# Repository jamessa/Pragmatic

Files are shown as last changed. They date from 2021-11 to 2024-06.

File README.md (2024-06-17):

# Pragmatic Keyboard Kit

**Pragmatic 務實鍵盤** 是一個分離式鍵盤套件，有數字列，有方向鍵與功能列。支援VIAL與QMK，輕鬆調整鍵盤配置，是分離式鍵盤的基本款。

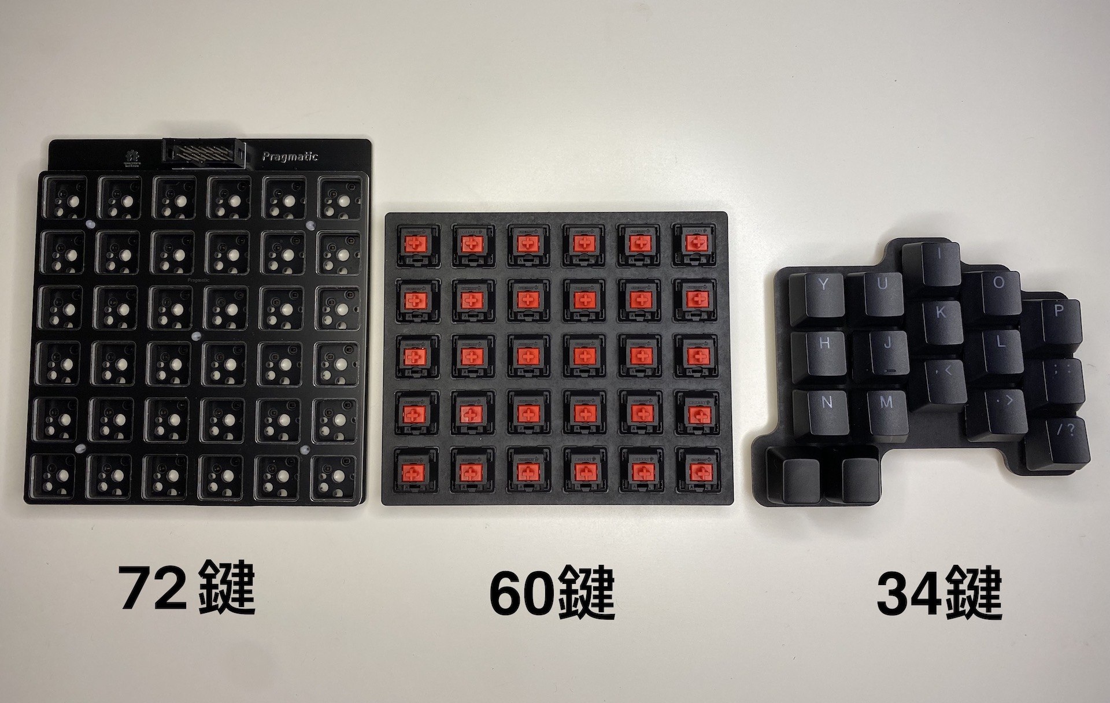
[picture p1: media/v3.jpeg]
V3


# 務實主義

本套件的開發將會務實的採用[敏捷流程](http://theleanstartup.com)，每次都發佈最小可行硬體套件，然後讓大家一起討論，看看如何讓這個鍵盤變得更好用。

換言之，這將是一把大家一起設計的鍵盤，而設計的原則就是「 **務實** 」，只加入使用的功能，降低開發的時間與成本；使用最少的硬體，達到最好的效果。

在嘗試了超多款鍵盤與超級多的[人體工學研究](https://youtu.be/p7gZdOTpbP8)之後，上週我無意間試做了分離式鍵盤的始祖直排[Let's split](https://github.com/nicinabox/lets-split-guide)，不得了！！！這實在太好用了，**務實，一整個好用。**

首先直排讓手指可以**自然的上下移動，減少手指的負擔**，讓使用者不會過勞。分離式鍵盤可以顯著改善腰酸背痛的辦公室症候群。自己改用了分離式鍵盤以後，背痛就減輕八成(個人經驗)。

**總鍵數達到72個，但是使用的空間卻比60%鍵盤還小**，實在是太神奇了。因此我才會想要開啟這個專案。

務實的設計目標是用最少的晶片做出可分離的鍵盤。不同於一般的分離式鍵盤需要兩個控制板，務實鍵盤只需要用到一個控制板。

**Pragmatic 務實鍵盤**是100%開源的，全程使用開源電路軟體KiCad設計，讓大家可以隨意改出符合自己需求的版本。要實踐一把務實鍵盤，需要以下的材料：

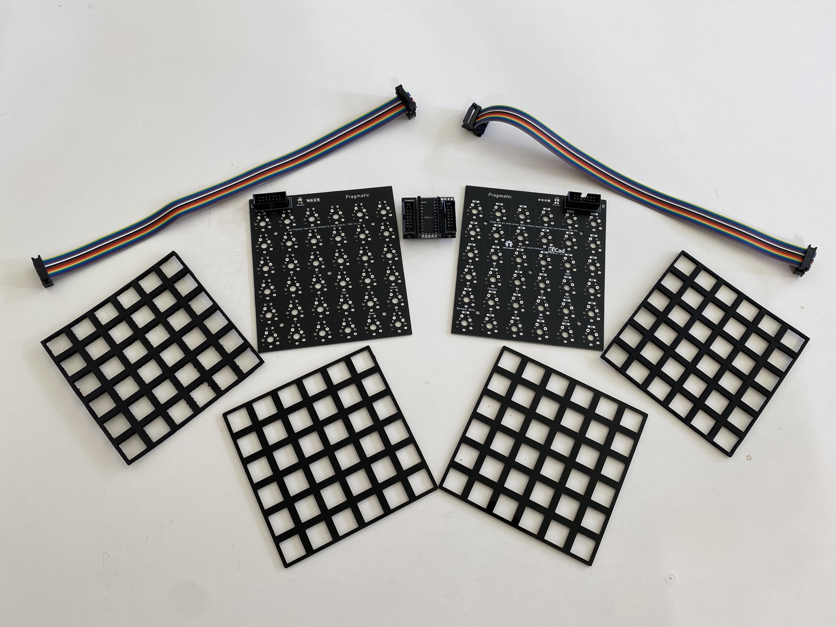
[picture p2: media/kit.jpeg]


- 務實鍵盤電路板套組，如上圖：
  - 電路板 * 3片：主控、左手、右手。
  - 壓克力定位板 * 2片
  - 消音泡棉 * 2片
  - 排線 * 2條

- 套組不含
   - [Pro Micro](https://www.sparkfun.com/products/12640)或相容的開發
   - 軸
   - 鍵帽
   - 願意打破傳統的心（對，就是你！）

# 預設配置
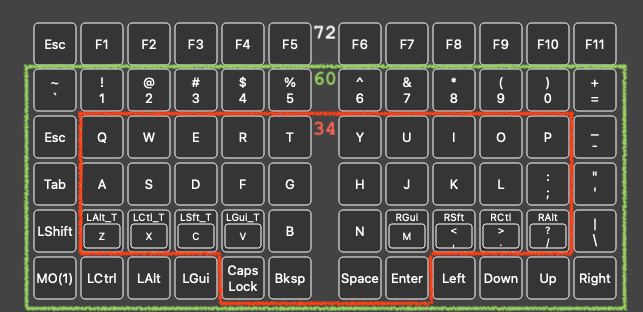
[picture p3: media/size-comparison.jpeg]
size comparison chart


# [使用手冊](START.md)

# FAQ

Pragmatic V3 FAQ (https://youtu.be/gGC56R72y4Q)說明影片

## 分離式鍵盤會不會很難適應？
老實說，這絕對不是一天就可以適應的，但是[鍵人谷](https://www.facebook.com/groups/1111882339005914)太多人換過鍵盤了，都可以提供很多方法。我自己會建議每天[keybr.com](keybr.com)練習15分鐘，慢慢打，求正確度，不用擔心速度。一到兩週就可以上手了，從此人生就改變了?!

## 拇指好按嗎？
內行人，其實我的右手很弱，打字一整天右手就會開始痛。然後我開始做鍵盤配置與手的解剖學研究，才發現到拇指不應該大量使用

## 組裝好之後，桌面到鍵帽(假設是高軸加上XDA鍵帽)的厚度如何？
24mm 我也是用XDA。應該說，因為我不用QWERTY配置，導致我只有XDA可以使用。

## 可以改鍵盤配置嗎？
本鍵盤支援[QMK](https://qmk.fm)與[Vial](https://get.vial.today)，讓你為所欲為。

## 可以給一下目前您用的定義嗎？
我的配置。我平常寫C, Python,最近寫Tex😅 打字的話，漢語拼音佔九成，英文一成。
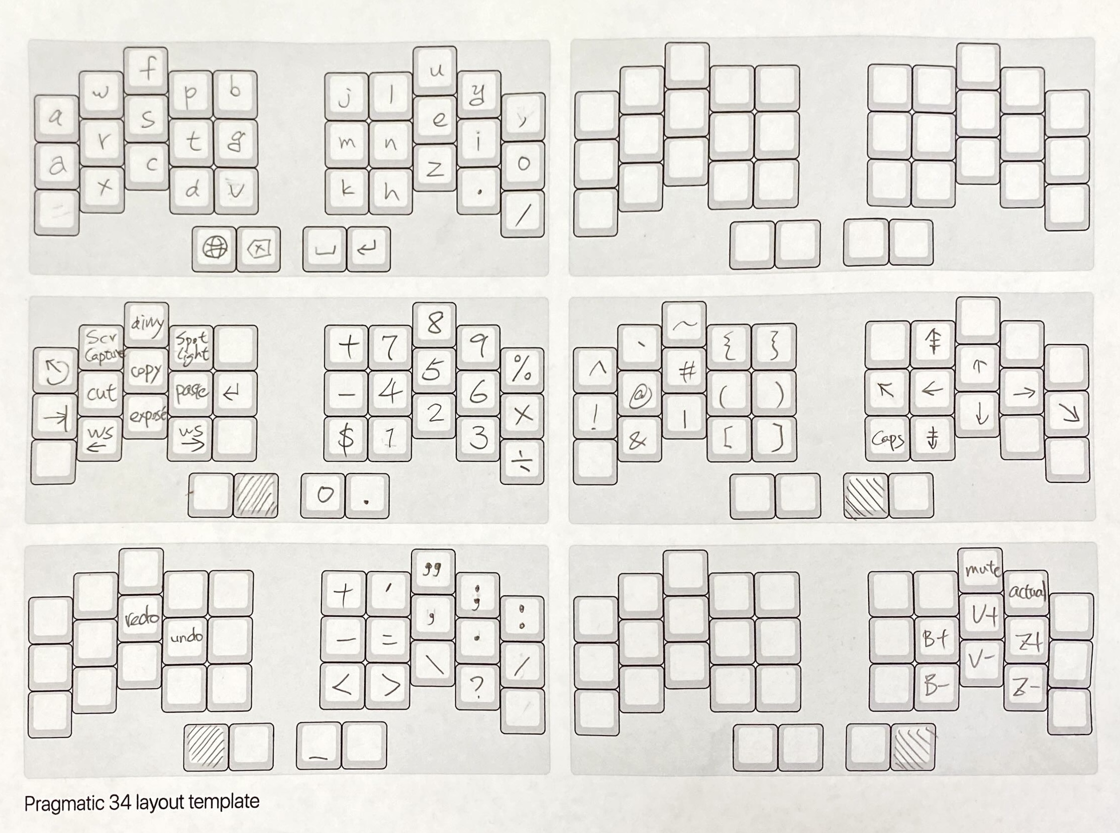
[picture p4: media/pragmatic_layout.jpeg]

而且我喜歡用鉛筆做記號，方便我快速修改配置。你可以在此下載

- 34的空白設計檔[PDF](media/pragmatic%2034%20layout%20sheet.pdf)。
- 42的空白設計檔[PDF](media/Pragmatic%2042%20Layout%20Designer.pdf)、[SVG](media/Pragmatic%2042%20Layout%20Designer.svg)。

## 關於小鍵盤使用比較複雜的指令，比如說 <kbd>Ctrl</kbd>+<kbd>C</kbd>，<kbd>Command</kbd>+<kbd>Space</kbd>這種橫跨多個 Layer 的情形，有甚麼比較好的處理方式嗎？設定Macro？

包括切換workspace，我都是做成左手快捷鍵。可以參考上圖左邊中間的配置，那是我的操作與數字層。

## 在咖啡廳使用會被搭訕嗎？
我不知道為什麼你要這麼問。但是我們也做了一個抽樣調查，正妹/天菜受訪者表示會想要瞭解這個新奇的鍵盤，而不是使用者別擔心。

# 安裝說明
1. 依照下圖順序排列
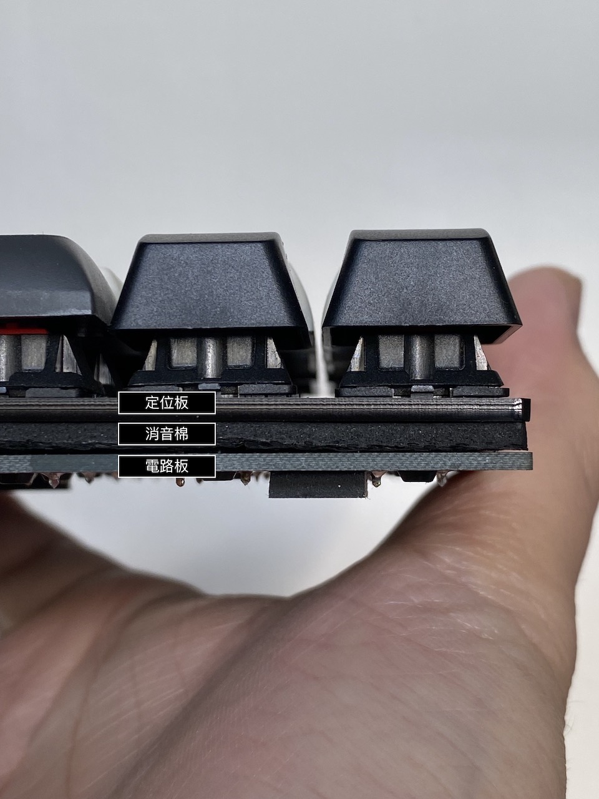
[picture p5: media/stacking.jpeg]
stacking

2. 接線方式
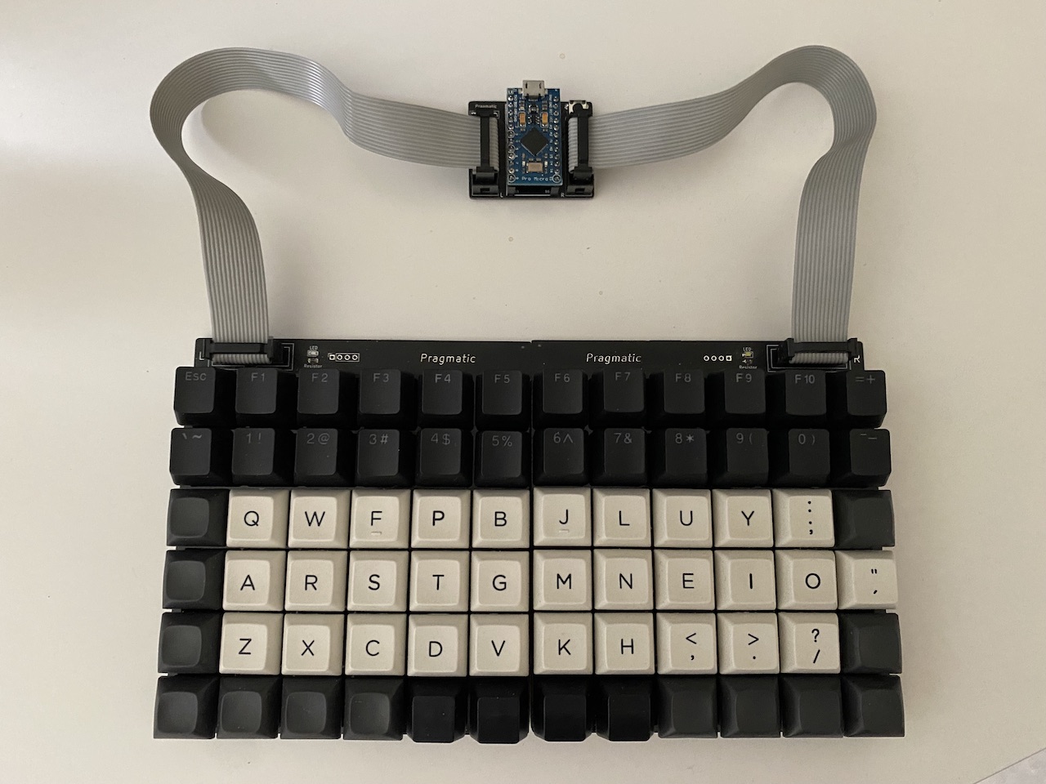
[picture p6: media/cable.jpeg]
cable


# Vial使用方式

1. 下載[Vial](https://get.vial.today)
1. 打開Vial.app就可以修改配置了。

# 更新韌體
1. 下載最新的
  - [QMK Toolbox](https://github.com/qmk/qmk_toolbox/releases/latest)
  - [務實韌體](https://github.com/jamessa/Pragmatic/releases/latest)
  - [Vial配置軟體](https://get.vial.today/download/)
2. 開啟「Vial」，備份目前的配置。「Vial」->「Save current layout」。
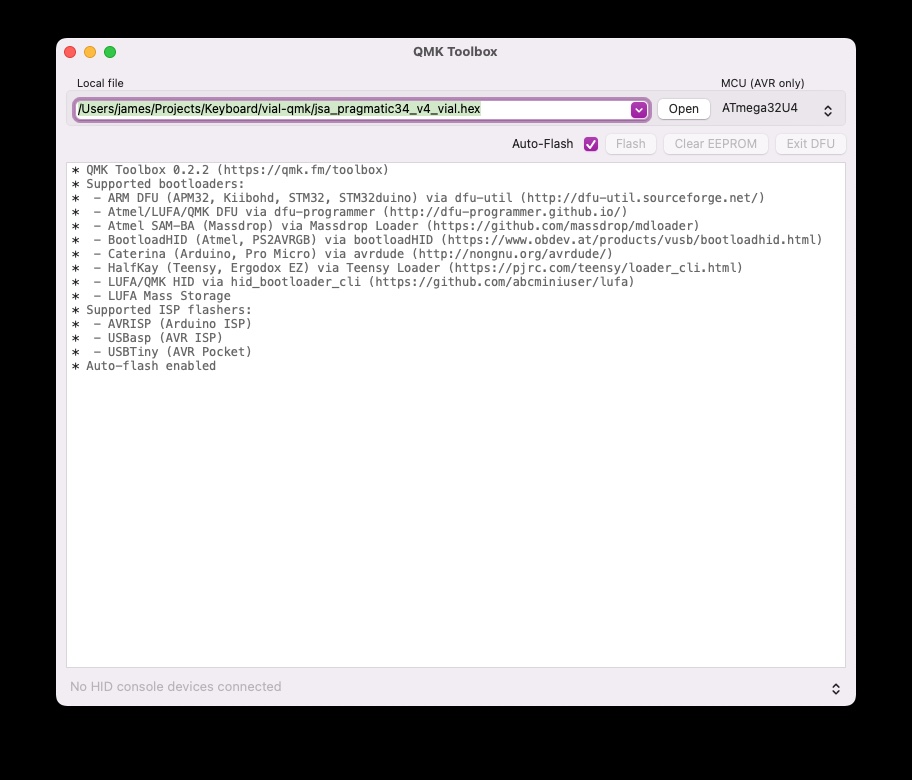
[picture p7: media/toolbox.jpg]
toolbox
3. 開啟QMK toolbox，選取剛剛下載的韌體，並且勾選*Auto-Flash*。
4. 按下控制板上面小小的Reset按鈕，這樣就更新完成了。

# Inspired by

- [34 key layout](Seniply https stevep99 github io seniply by Stevenp99)
- [Let's split](https://github.com/nicinabox/lets-split-guide)
- [GH36](https://geekhack.org/index.php?topic=61306.0)
- [Nyquist/Levison Keyboard](https://keeb.io/products/nyquist-keyboard)
- Xah lee [Why function keys are useful!](http://xahlee.info/kbd/keyboard_function_keys.html)
- Quasimode https://en.wikipedia.org/wiki/Mode_(user_interface)
- Mode slips and low discoverability. https://www.nngroup.com/articles/modes/

# 想知道更多

[臉書討論](https://www.facebook.com/groups/1111882339005914/posts/1790356644491810) 或 加入[Telegram群組](https://t.me/joinchat/qp7NLK_H0vY2MjA1)

# Changelog
- 2022-08-08 Refactor folder structure.
- 2022-08-05 Pragmatic 34 R2.
- 2022-06-11 V3.1 Controller with OLED.
- 2022-03-18 V3 with [3 form factor](https://www.facebook.com/groups/1111882339005914/posts/1883231691870971/)
- 2022-03-02 V2 Hotswap
- 2022-01-09 改用 Kicad 6
- V0.4 改回ProMicro腳位，增加相容性。
- V0.3 改為Elite-C腳位，重新定義IDC connector的腳位。
- V0.2 改為雙面版。
- V0.1 開始。

## Gallery

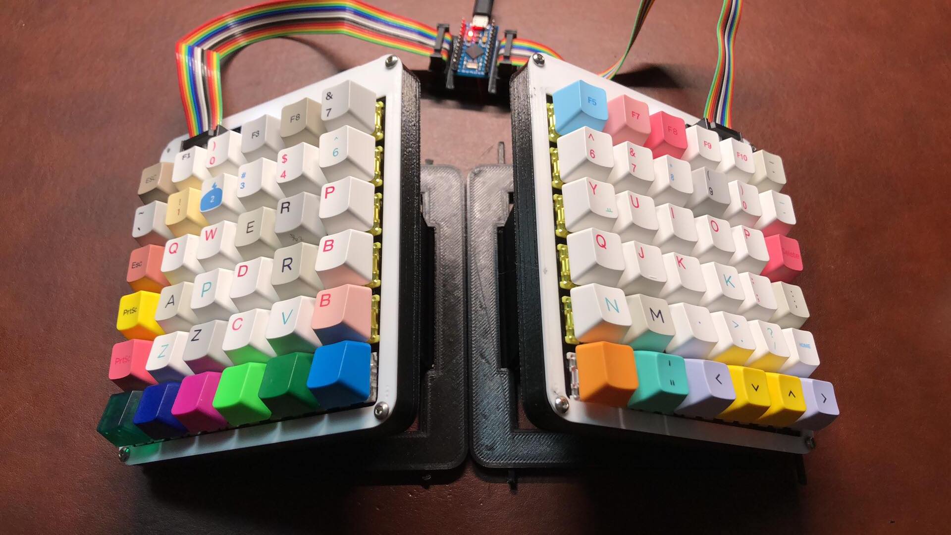
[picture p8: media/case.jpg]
Pragmatic with Case

Pragmatic 72 [Tent Case](https://www.thingiverse.com/thing:5178752) designed by [Botio! Studio](https://botiostudio.com)

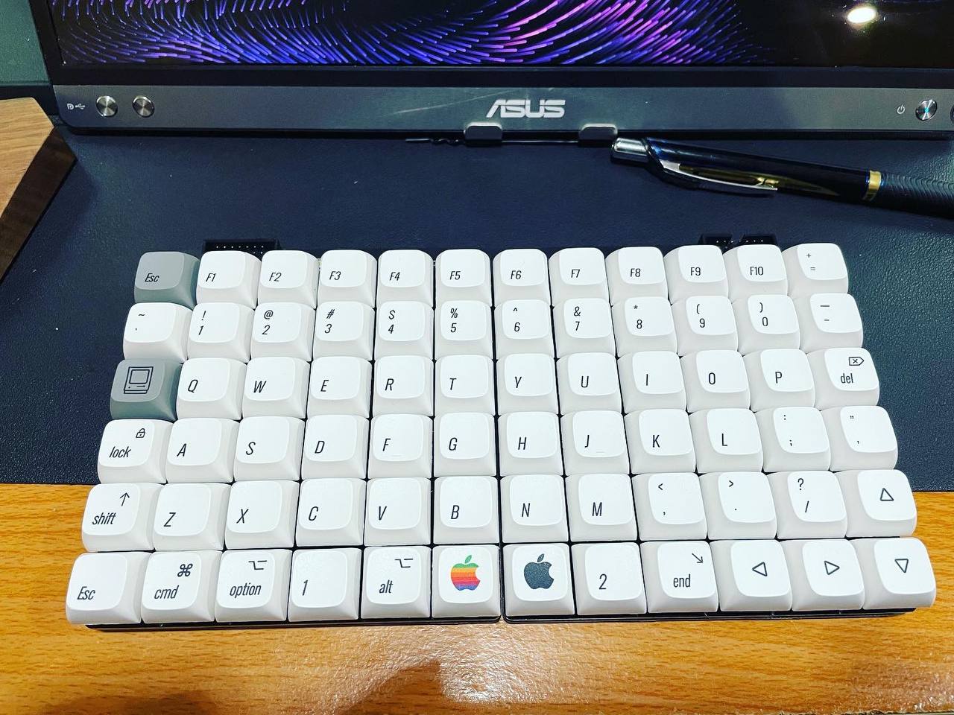
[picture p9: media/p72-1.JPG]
Pragmatic 72
 Pragmatic 72 by Bart.

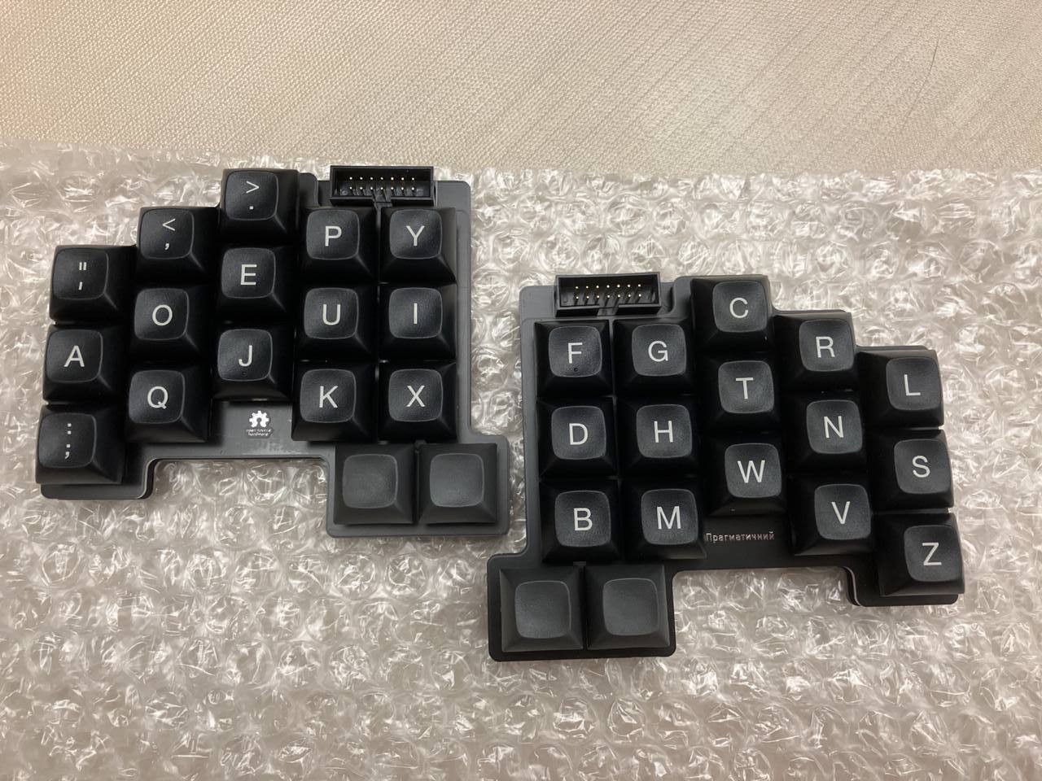
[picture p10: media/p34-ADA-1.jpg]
Pragmatic 34
 Pragmatic 34 with [ADA keycaps](https://drop.com/buy/tex-ada-keycap-set) by Sean

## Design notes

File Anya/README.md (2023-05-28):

# Changelog
## 2023-05-29 R2
- Use SK6812 for eaiser key switch change

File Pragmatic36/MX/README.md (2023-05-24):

The Pragmatic 36 keyboard features

- 21 keys per hand with a fully symmetric double side design. One side is designed for the left hand and the other for the right.
- Duplex Matrix to save pins. Use Controller A.
-  8-pin connector that utilizes a user-friendly 2x4 2.54mm PinHeader.
- Support Kailh hotswap sockets.
- A modern 19mm x 19mm key pitch.
- Supports Kailh PG12800 Half key switch.

Current status: initing.

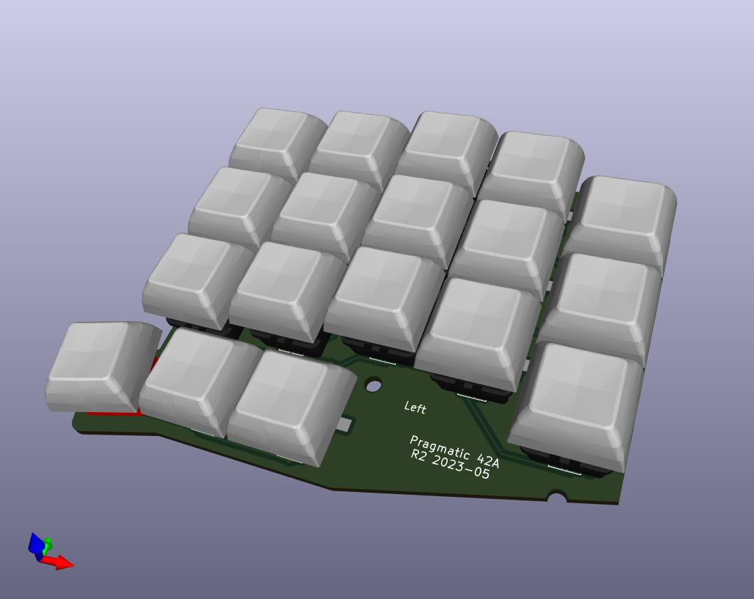
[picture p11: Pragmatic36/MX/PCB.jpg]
PCB


# Revsions
## MX36A1 2023-05-24 
   ^^ Swith type MX or Choc
     ^^ Number of keys
       ^ Matrix Type: null for naïve matrix, A for duplex matrix
        ^ PCB Revision
- Stagger Profile MX V3
- Initial release, modified from MX42A2.

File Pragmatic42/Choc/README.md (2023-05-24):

The Pragmatic56 keyboard features

- 28 keys per hand with a fully symmetric double side design. One side is designed for the left hand and the other for the right.
- Duplex Matrix to save pins.
-  8-pin connector that utilizes a user-friendly 2x4 2.54mm PinHeader.
- Support Kailh hotswap sockets.
- A compact key arrangement with a 19mm x 18mm pitch and an 18mm vertical pitch that reduces fingers need to travel distance.

Current status: Validating.

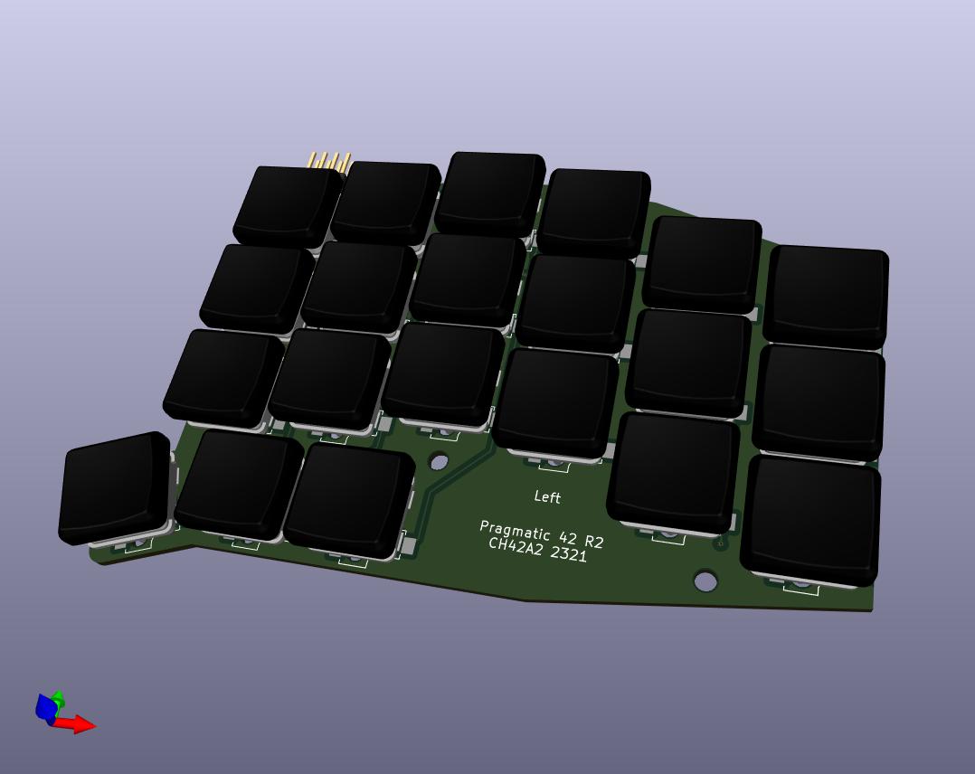
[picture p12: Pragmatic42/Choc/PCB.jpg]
PCB


PCB with switches

# Revisions

## CH42A2 2321
   ^^ Switch type CHoc or MX
     ^^ Number of keys
       ^ Matrix Type: null for naïve matrix, A for duplex matrix
        ^ PCB Revision
- Change to Profile Choc V3

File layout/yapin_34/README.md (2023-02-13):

# Pragmatic 60 
> (34 keys version)

> This is 34 key layout for Pragmatic 60

> This layout is for "Programmer Dvorak" user

> by yapin

## Design Detail

### 設計緣由
- 因為當初不敢直接跳34鍵的坑，所以先拿60鍵試水溫，但是由於實際使用時遇到符號鍵配置的問題，需要重新設計和習慣，思考了一下最後還是決定直接設計34鍵的配置，希望之後可以無縫接軌Pragmatic 34

### 設計邏輯

#### Layer 0
1. 主要參考Pragmatic 34 的功能鍵邏輯，再加上照搬Programmer Dvorak 的主鍵位
2. Backspace 和 Enter 在同一邊主要是考量到這兩按鍵不會需要大量的交替使用，因此放在同一邊即可。
    - 2-1. Enter內縮主要是因為以下原因
        - 2-1-1. 在terminal中enter會立即觸發，因此避免誤按
        - 2-1-2. 個人使用頻率上backspace遠高於enter

3. Space 習慣以右手觸發，幾乎不太會有左右手交互觸發的情形，因此只使用左半邊的space

#### Layer 1

1. 將原本Programmer Dvorak的數字列往下挪移
2. 將{}, [], () 獨立出來，以=,*為分界其餘符號向左遞補
    - 2-1. 部份符號可以利用shift轉換其他符號，因此直接將這些符號在向下挪移
    - 2-2. 考量到 "-" 已經習慣在home row，所以保留該位置並將 "@", "^" 往左移動
    - 2-3. 由於符號層正在適應，且原先符號可支援shift進行切換，因此保留shift，未來嘗試能否利用vial達到自定義shift layout

#### Layer 2

1. 此層主要用來定義{}, [], () 與方向鍵
2. {}, [], ()按鍵位置大幅採用Programmer Dvorak設計
3. 方向鍵以右手為主，並且以人類直覺為主
    - 3-1. Home 常用來指向程式碼的首位，因此設計在左方向鍵的左方
    - 3-2. End 常用來指向程式碼的末位，因此設計在右方向鍵的右方
    - 3-3. Page Up, Page Down 由於過往相對位置在方向鍵的右上方，因此考慮相對位置與邏輯進行配置
    - 3-4. Cope, Paste, Cut, 由於常配合方向鍵+shift進行選取，所以設計在右手邊
    - 3-5. 由於時常使用範圍選取功能，所以將shift定義在左手食指
    - 3-6. Esc, Tab則保留相對位置
    - 3-7. 保留alt, gui按鍵，這兩按鍵在單螢幕時，可以簡易地切換桌布和工作區

#### Layer 3

1. 未動工，預計保留給多媒體鍵，coding相關

#### Layer 4

1. 未動工，考慮保留給numpad

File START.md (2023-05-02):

# 組裝

### 務實56
組裝影片

組裝影片 (https://youtu.be/EOoOmIPXUWc)

### 務實34、60、75

1. 認識你的鍵盤。一把務實鍵盤由一塊主控板與兩片手板組成。
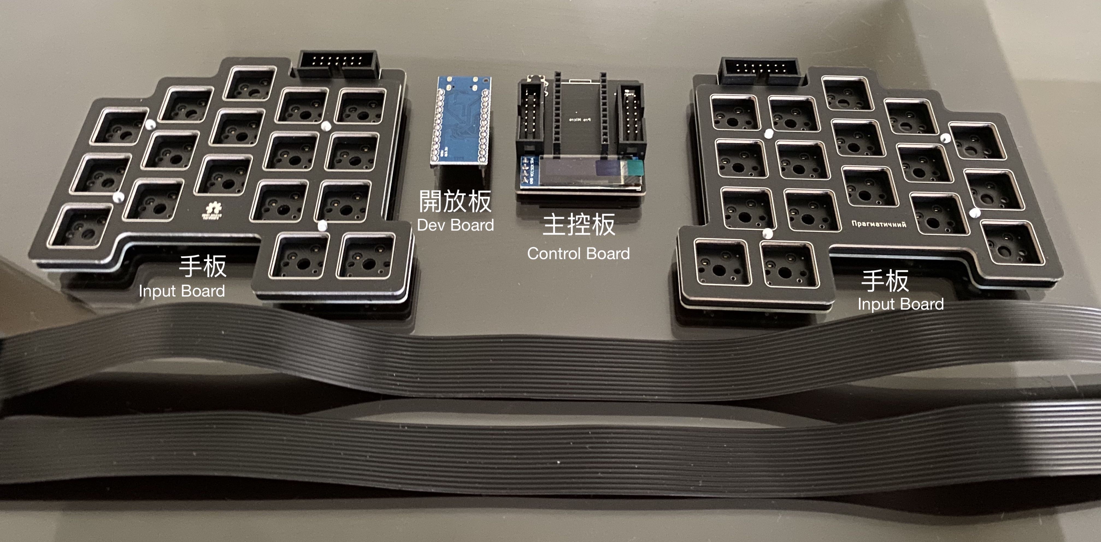
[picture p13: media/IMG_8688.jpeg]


1. 將開發板安裝到主控板上。注意Type C接口朝上。
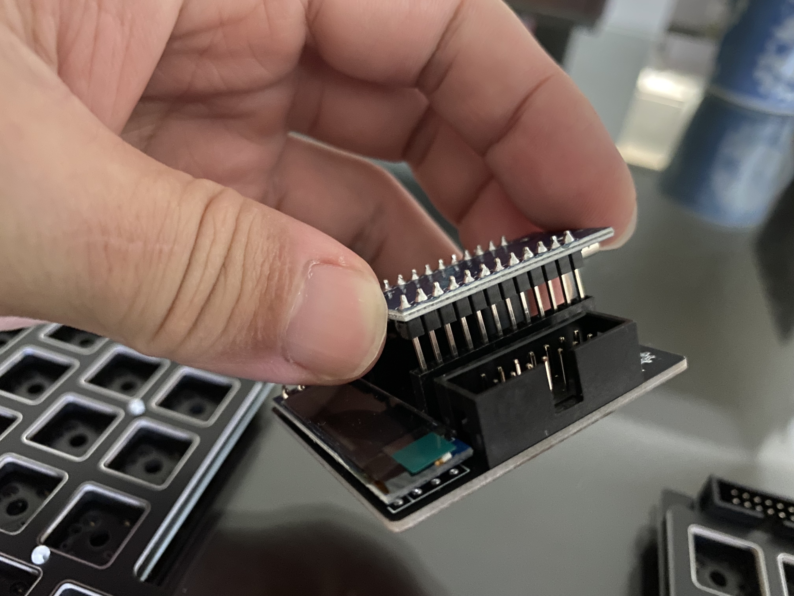
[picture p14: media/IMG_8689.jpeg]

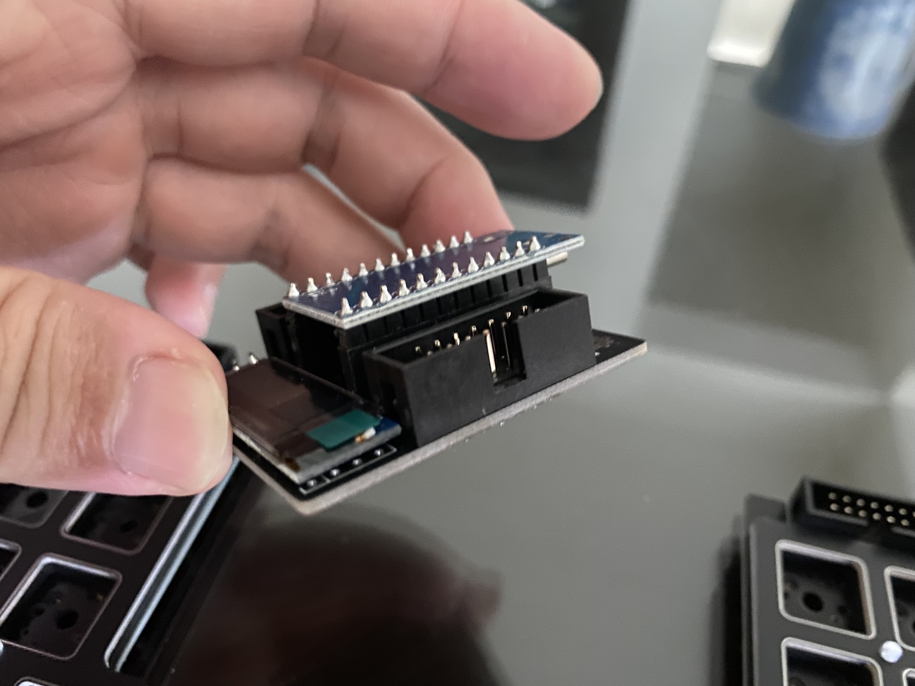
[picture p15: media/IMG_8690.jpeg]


1. 將排線插入主控板。注意排線有卡榫，要依照卡榫方向安裝。
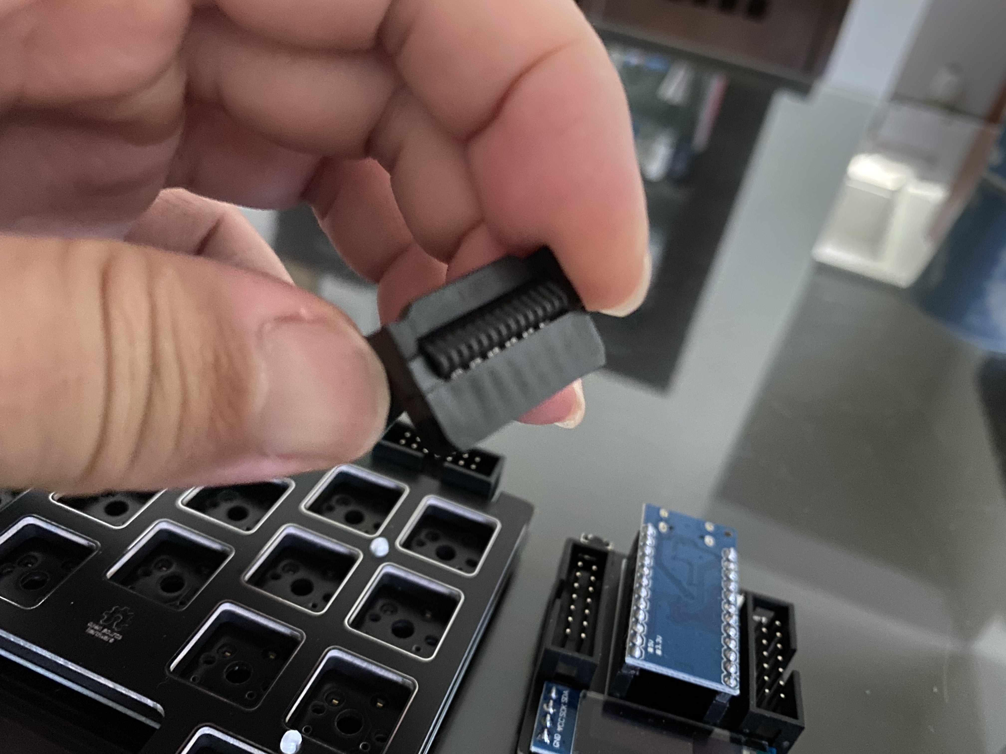
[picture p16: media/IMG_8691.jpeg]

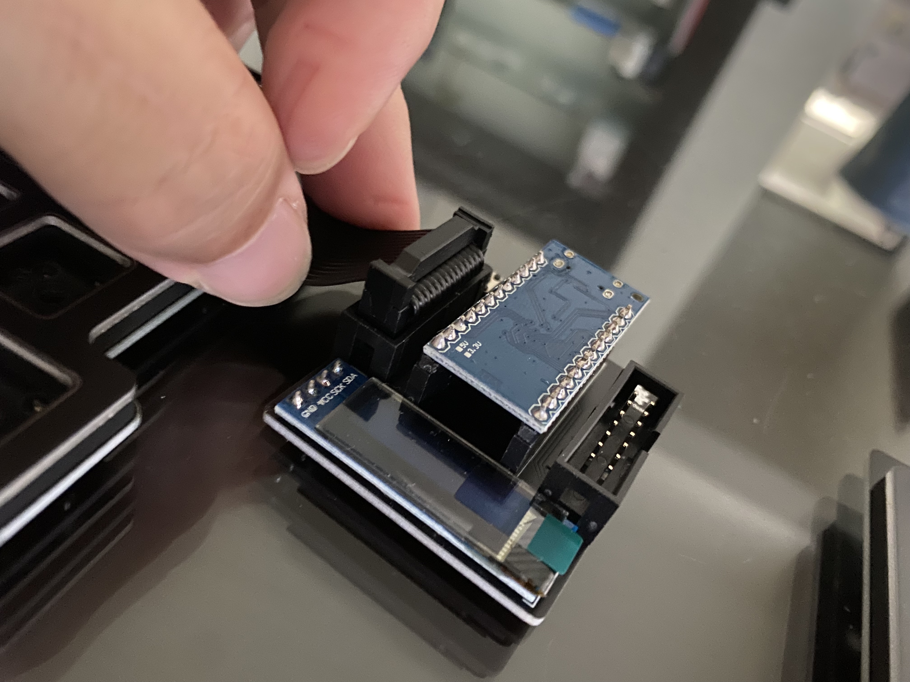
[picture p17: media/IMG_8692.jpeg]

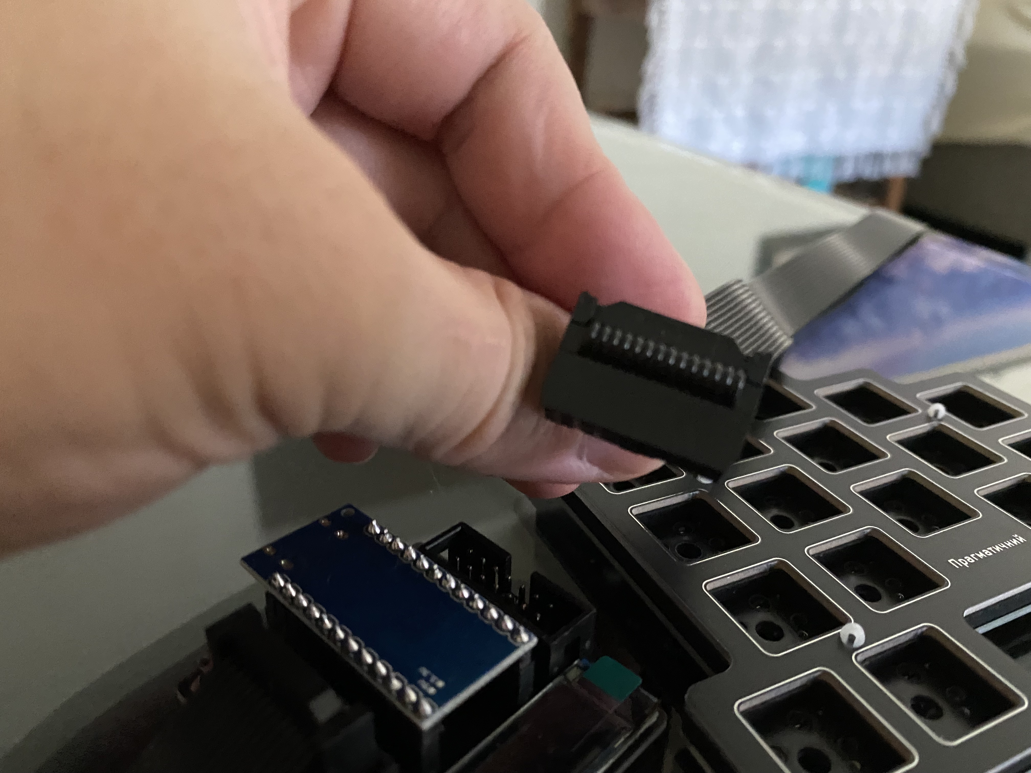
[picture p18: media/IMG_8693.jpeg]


1. 將排線插入手板。
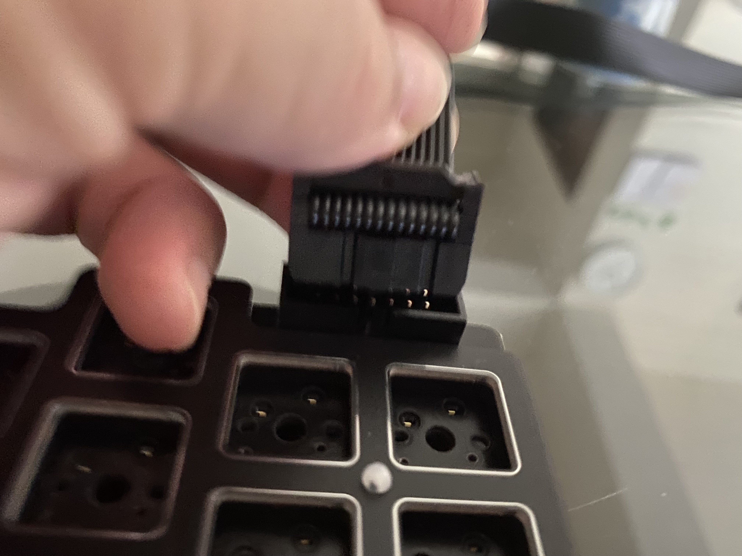
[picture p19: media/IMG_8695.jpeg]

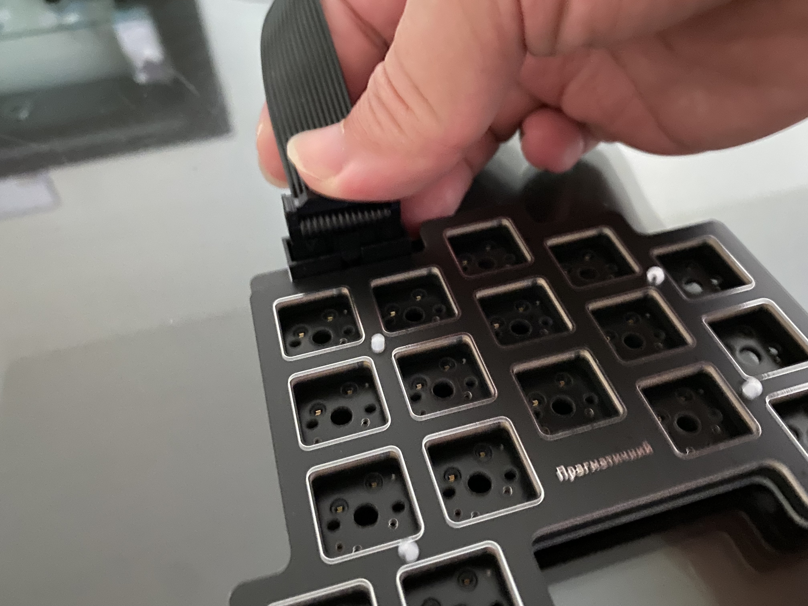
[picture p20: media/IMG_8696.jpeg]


1. 完成品。
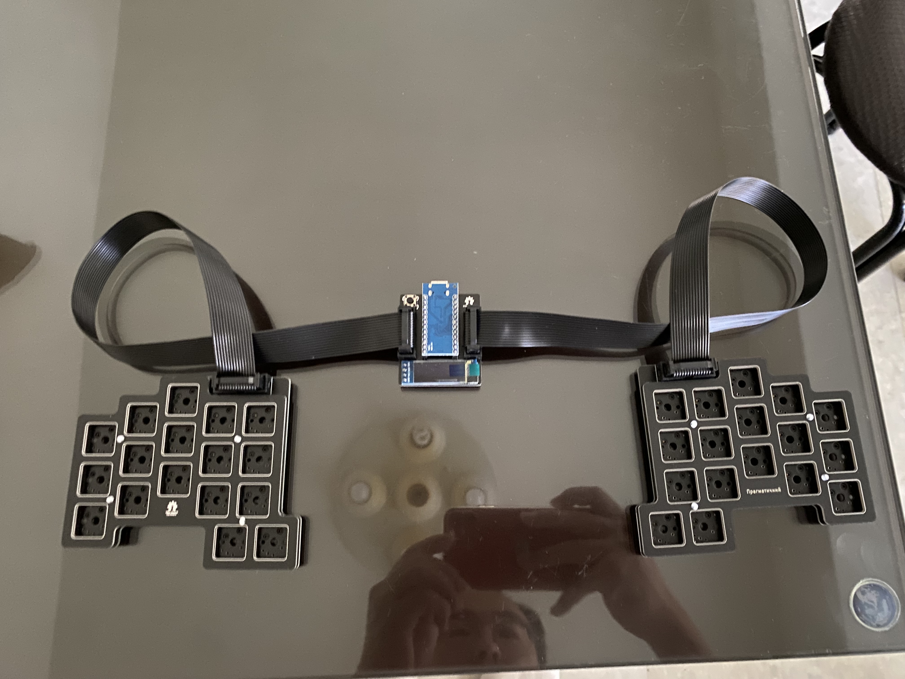
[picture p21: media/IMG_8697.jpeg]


## 測試

1. 接上電腦後會顯示
```
Pragmatic
-= 34 =-
```
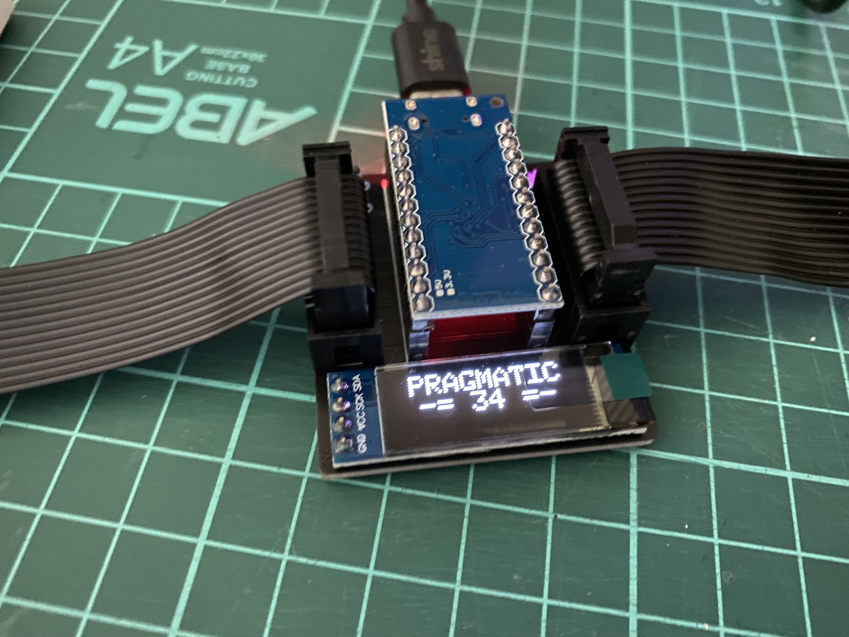
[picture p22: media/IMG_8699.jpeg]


1. 安裝 Vial.app，打開後開啟Matrix Tester頁面

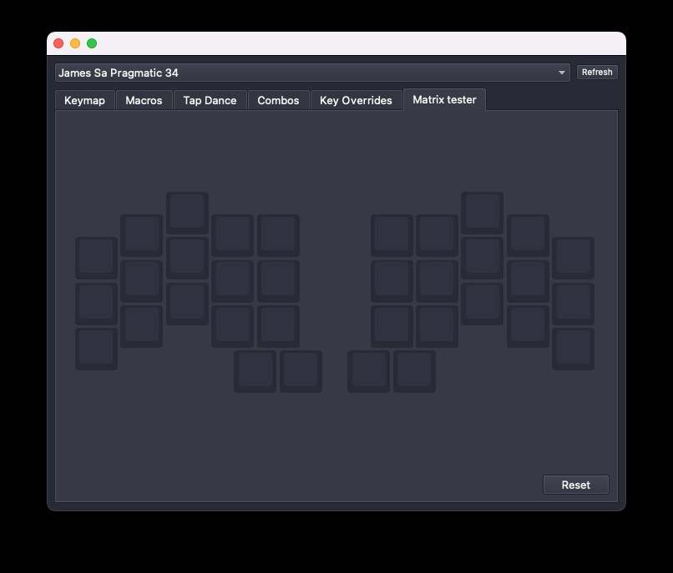
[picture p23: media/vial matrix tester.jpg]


1. 用導電物，譬如鑷子或是杜邦線依序輕觸熱插拔座的兩端。也可以直接把軸一個個裝上去，邊裝邊測試。
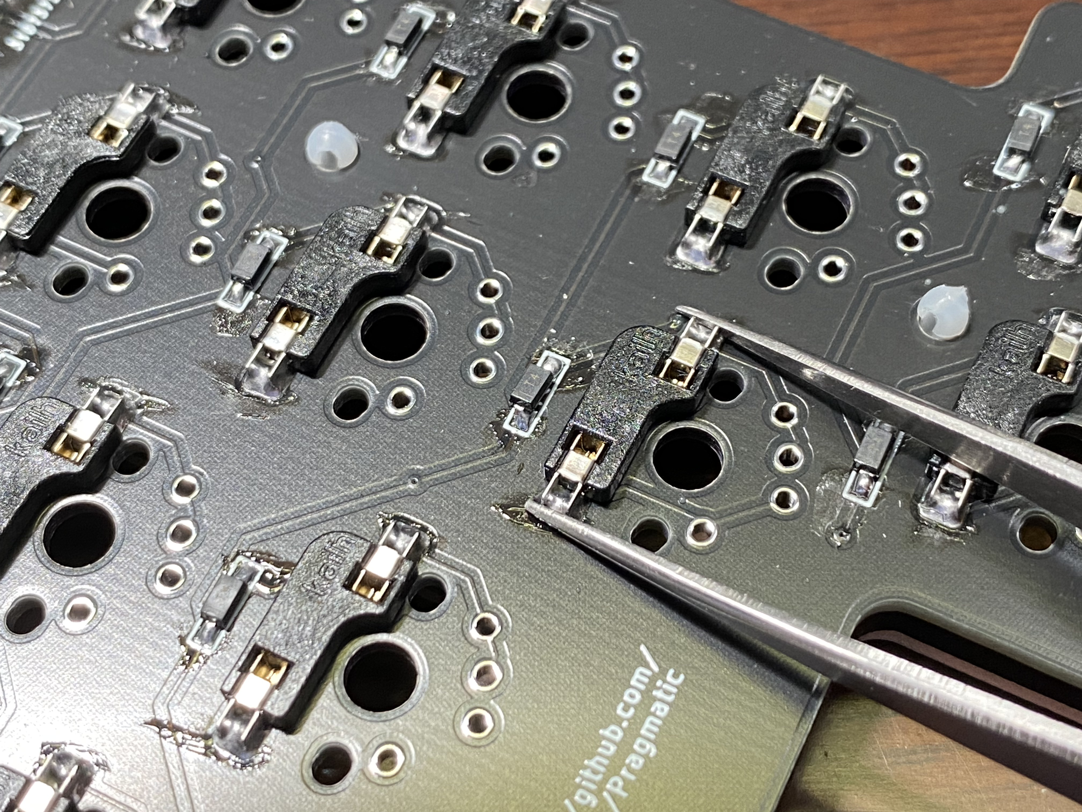
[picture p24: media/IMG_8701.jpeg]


1. 如果每一個按鍵都亮起來了，就是測試成功了。
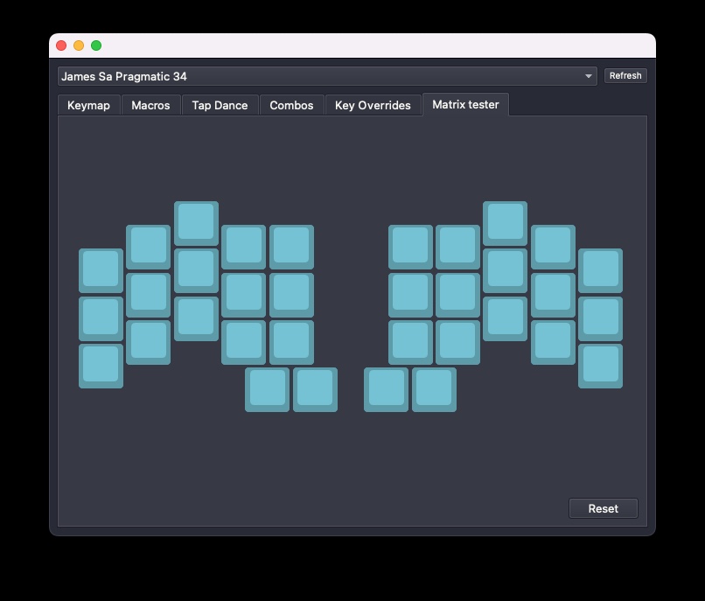
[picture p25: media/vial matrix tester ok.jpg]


## 使用

打開 Vial.app 的 Keymap頁面，預設的英文輸入法是Colemak DHM
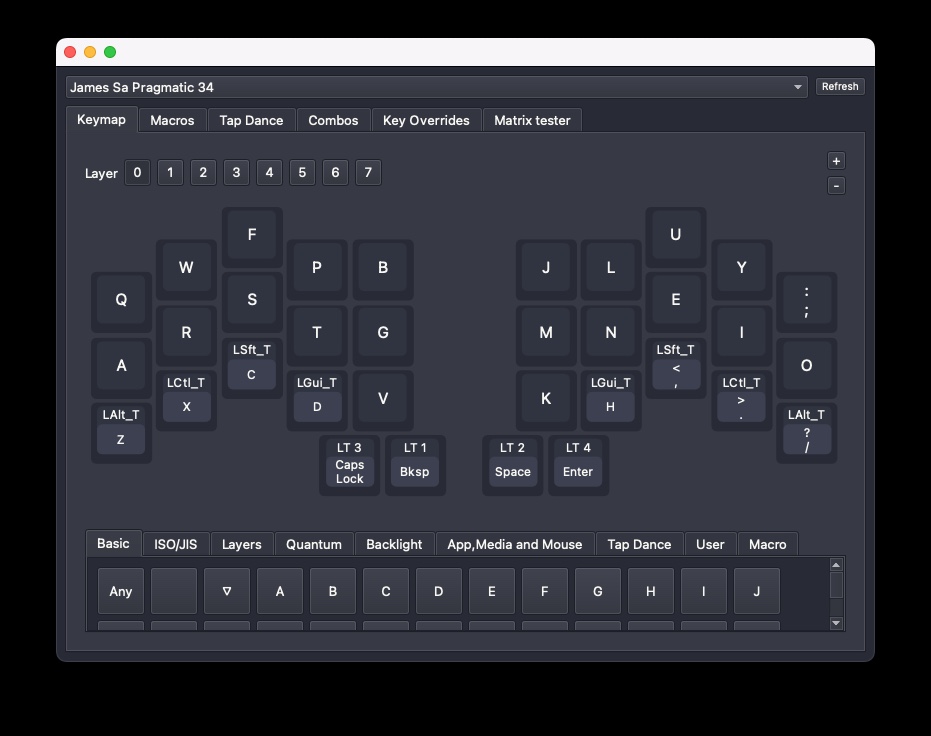
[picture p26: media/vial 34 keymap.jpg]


修飾鍵 Modifiers
- `LGui_T(D)`：表示長按就是左Gui鍵，按一下是<kbd>D</kbd>。Gui鍵在macOS就是<kbd>⌘</kbd>，在Windows就是<kbd>⊞</kbd>
- `LSft_T(C)`：表示長按就是左<kbd>Shift</kbd>，按一下是<kbd>C</kbd>。
- `LCtl_T(X)`：表示長按就是左<kbd>Control</kbd>，按一下是<kbd>X</kbd>。
- `LAlt_T(Z)`：表示長按就是左<kbd>Alt</kbd>，按一下是<kbd>Z</kbd>。

層鍵 Layer Keys
- `LT1(Bksp)`：表示長按Long Tap會切到第1層，按一下是<kbd>Backspace</kbd>。
- `LT2(Space)`：表示長按會切到第2層，按一下是<kbd>Space</kbd>。
- `LT3(Caps Lock)`：表示長按會切到第3層，按一下是<kbd>Caps Lock</kbd>。
- `LT4(Enter)`：表示長按會切到第4層，按一下是<kbd>Enter</kbd>。

# 改

要修改前，記得先把目前的配置存起來，Vial.app -> File -> Save Current Layout。

如果遇到問題，都可以直接到[Telegram Group](https://t.me/+qp7NLK_H0vY2MjA1)詢問喔。

> "If computer is the bicycle to the mind, keyboard is the pedal.", James Sa, creator of Pragmatic keyboard.

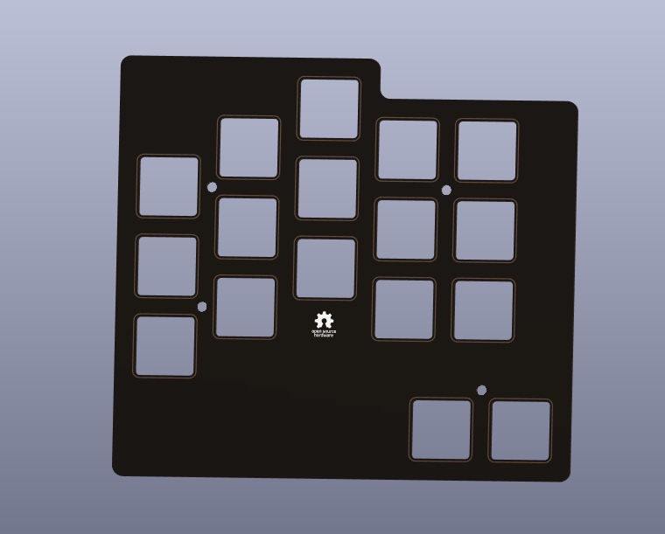
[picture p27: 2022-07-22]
Pragmatic34/LeftPlate/Renders/Screen Shot 2022-07-17 at 10.48.44 PM.jpg

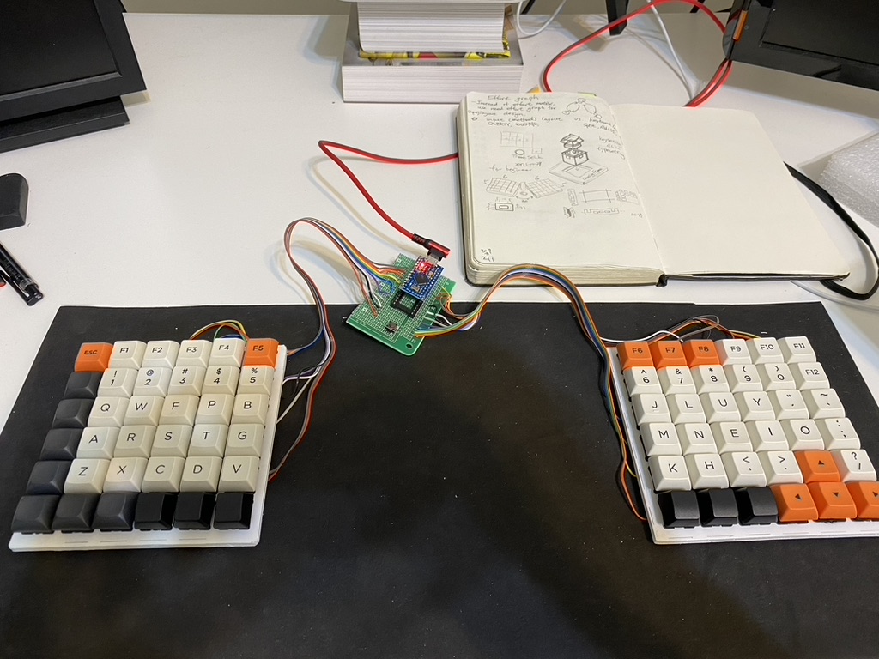
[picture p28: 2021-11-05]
media/poc.jpeg

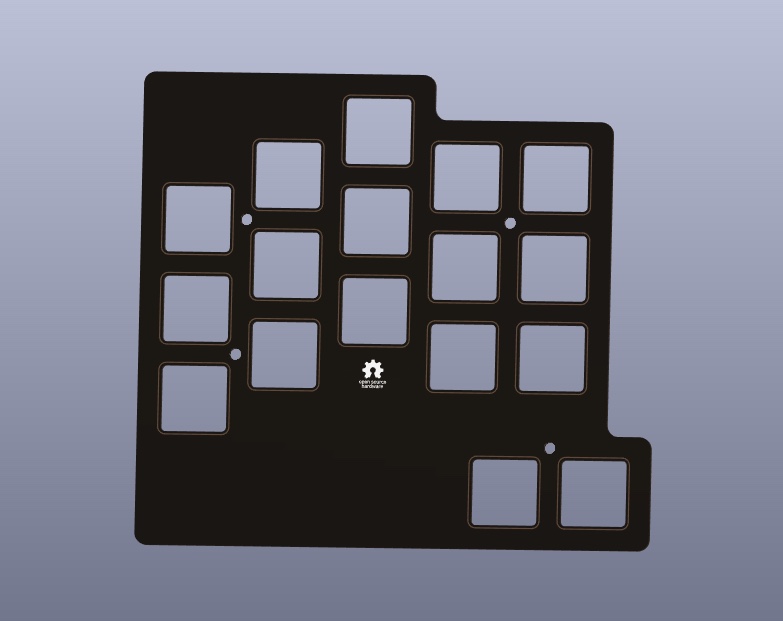
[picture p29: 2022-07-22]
Pragmatic34/RightPlate/Renders/Screen Shot 2022-07-17 at 10.47.02 PM.jpg

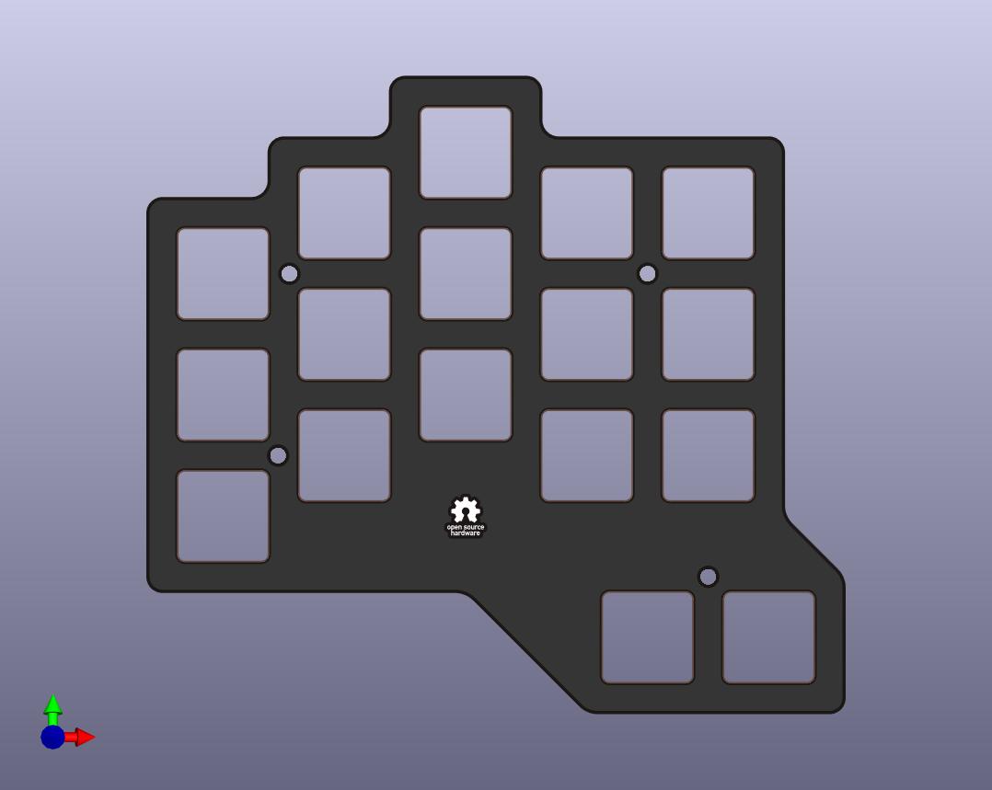
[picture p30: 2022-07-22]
Pragmatic34/RightPlate/Renders/final.jpg

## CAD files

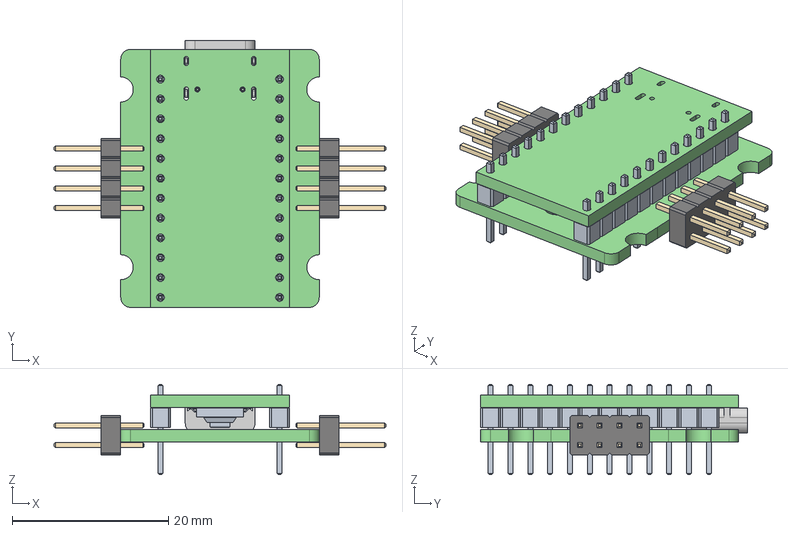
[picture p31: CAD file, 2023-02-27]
ControlR2/Control PCB.step
42.5 x 34.1 x 11.5 mm
Control PCB

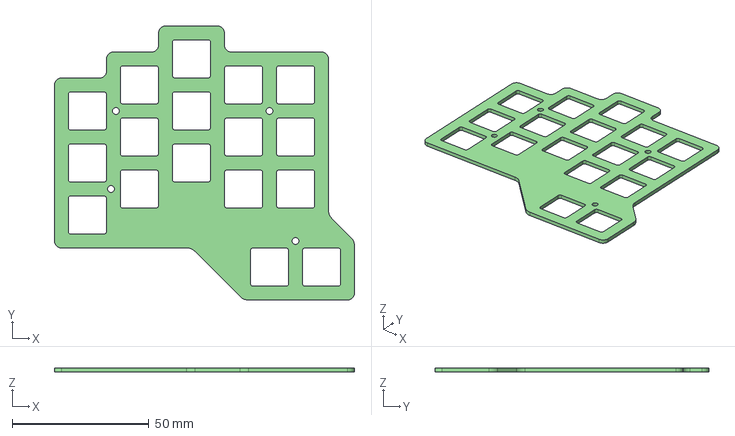
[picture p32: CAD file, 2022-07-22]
Pragmatic34/LeftPlate/Plate.step
109.9 x 100.3 x 1.60 mm

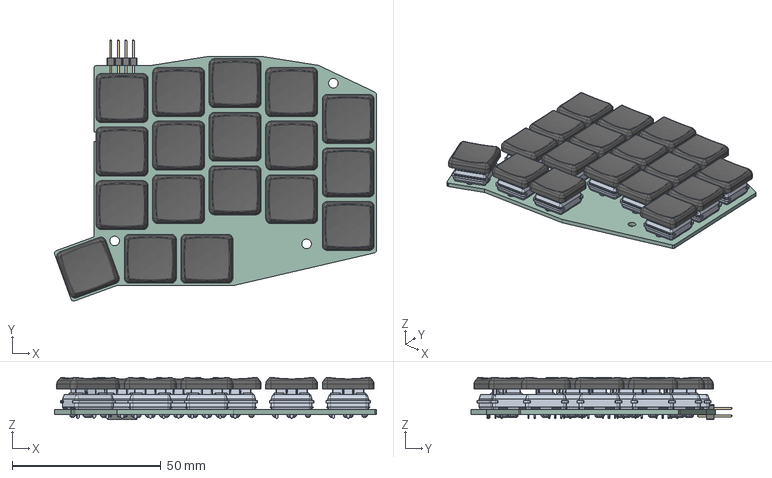
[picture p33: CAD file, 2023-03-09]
Pragmatic36/Choc/PCB.step
108.2 x 87.8 x 14.3 mm
PCB

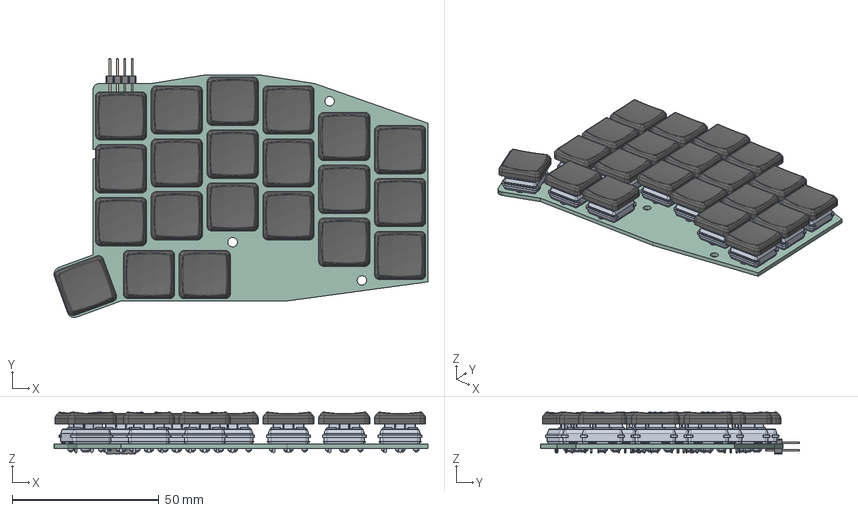
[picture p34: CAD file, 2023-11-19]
Pragmatic42/Choc/PCB R2.step
127.3 x 88.2 x 14.3 mm
Input PCB

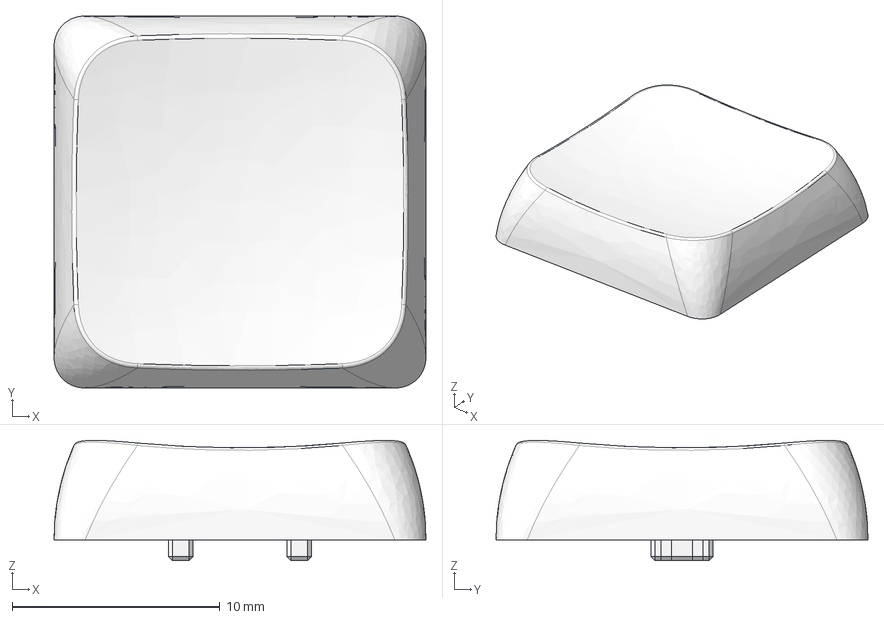
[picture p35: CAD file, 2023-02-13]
Pragmatic54/Choc/Models/Kailh Choc FunkMonk 1u.step
17.9 x 17.9 x 5.78 mm

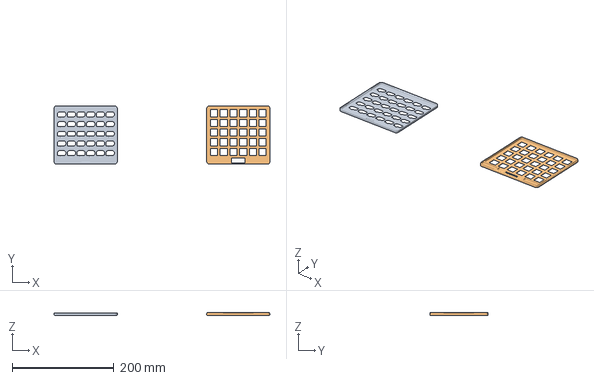
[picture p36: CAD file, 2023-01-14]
Pragmatic60/Case/MX60 V3 Low Profile.3mf
424.4 x 114.9 x 5.60 mm
Bottom
Top

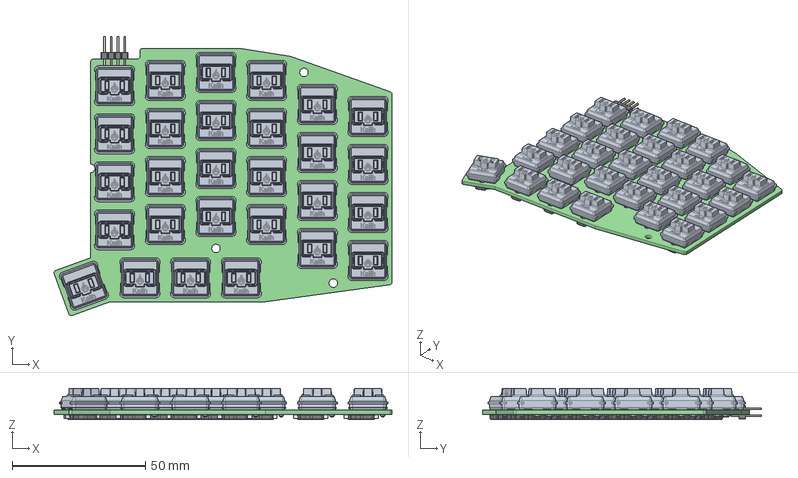
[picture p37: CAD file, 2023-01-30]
Prototyping/V4/V4.step
126.7 x 104.8 x 11.7 mm
V4 PCB

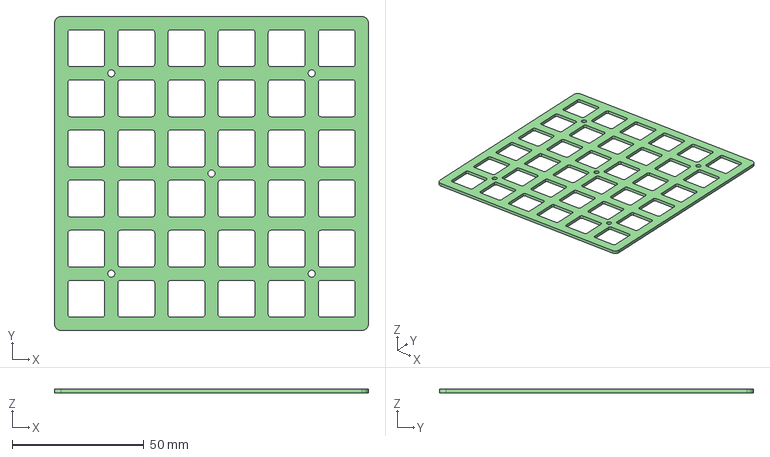
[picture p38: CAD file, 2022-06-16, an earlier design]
Archive/Pragmatic72/Input 6x6 plate/Plate.step
119.4 x 119.4 x 1.60 mm

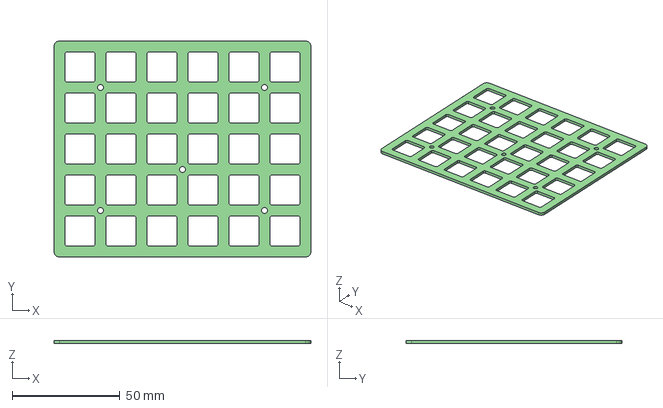
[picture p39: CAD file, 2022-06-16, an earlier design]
Pragmatic60/Input 5x6 plate/Plate.step
119.4 x 100.3 x 1.60 mm

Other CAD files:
Pragmatic34/RightPlate/Plate.step
Pragmatic42/Choc/PCB.step

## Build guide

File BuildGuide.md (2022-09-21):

# 務實34組裝說明

你需要一下工具
- 鑷子
- 斜口鉗
- 烙鐵
- 橡皮筋一條

預估時間約90分鐘可以完成。

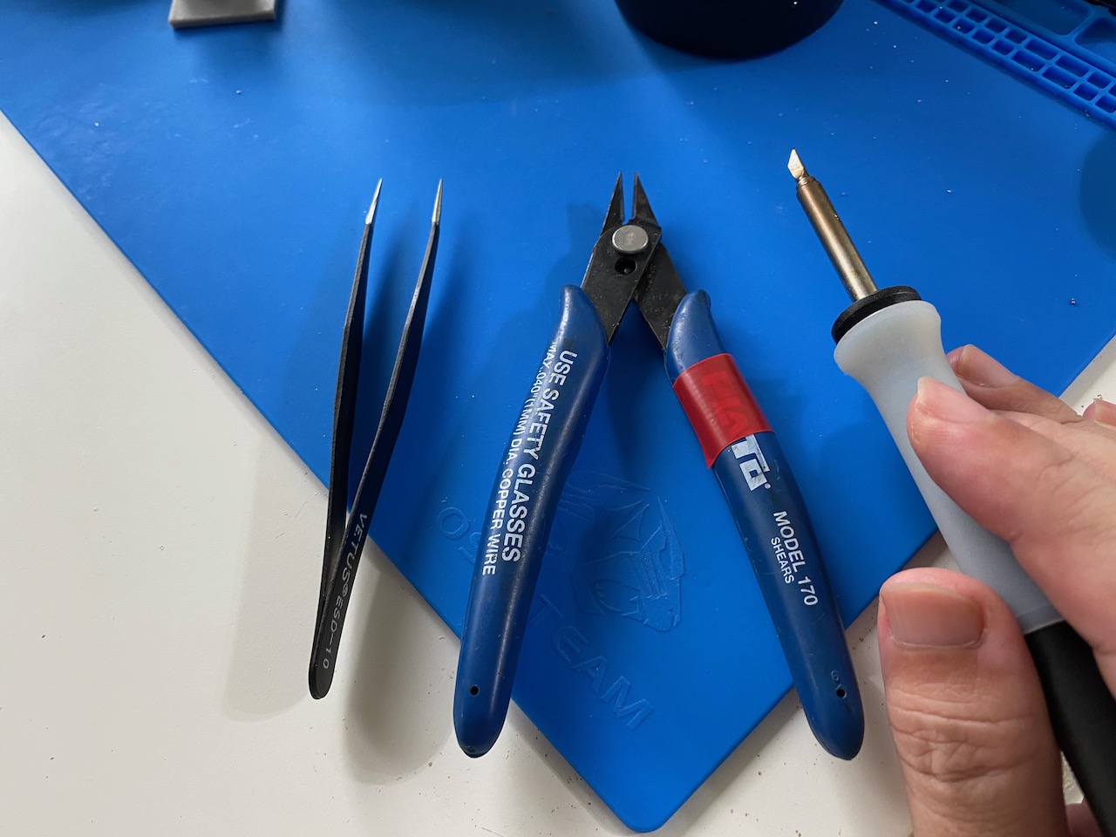
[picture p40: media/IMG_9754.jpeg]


# 手板的焊接

1. 在二極體腳位右邊(紅色箭頭處)的焊點加上一些焊錫。
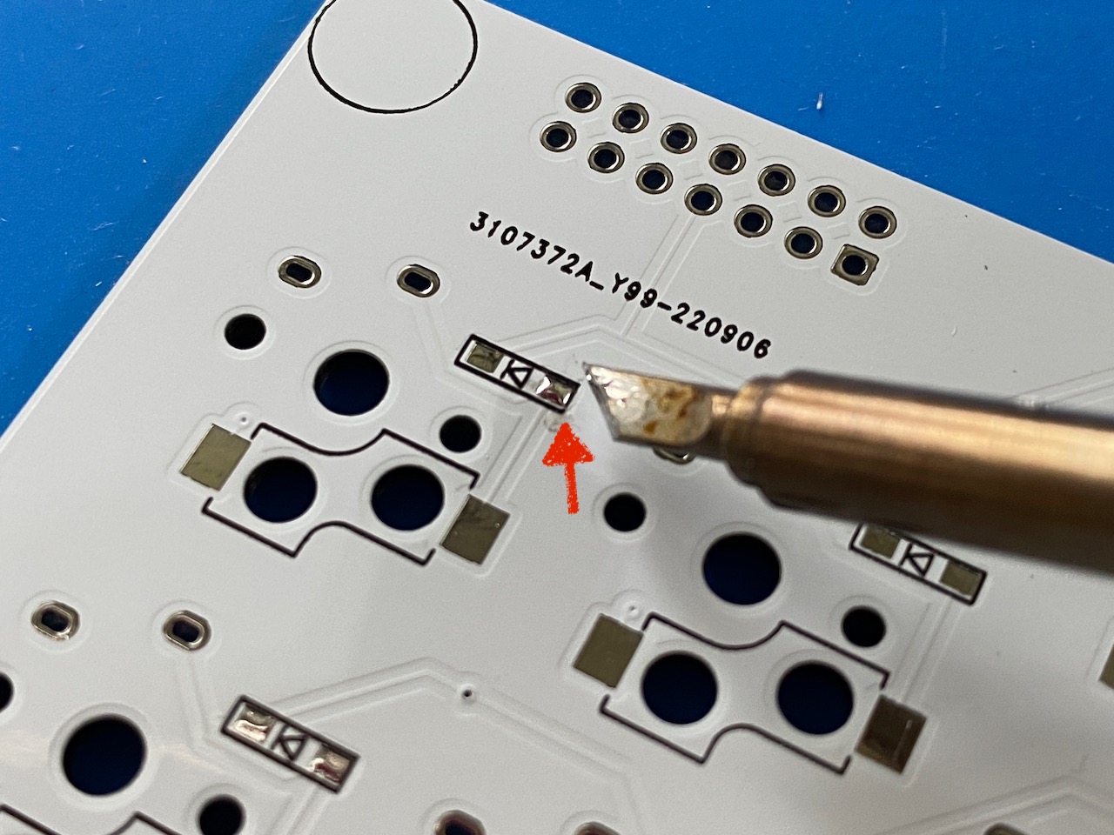
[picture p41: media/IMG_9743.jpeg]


2. 擺上二極體並確認方向。二極體有方向性，元件上有一條直槓(紅色箭頭)，請跟圖示(綠色箭頭)保持同一方向。
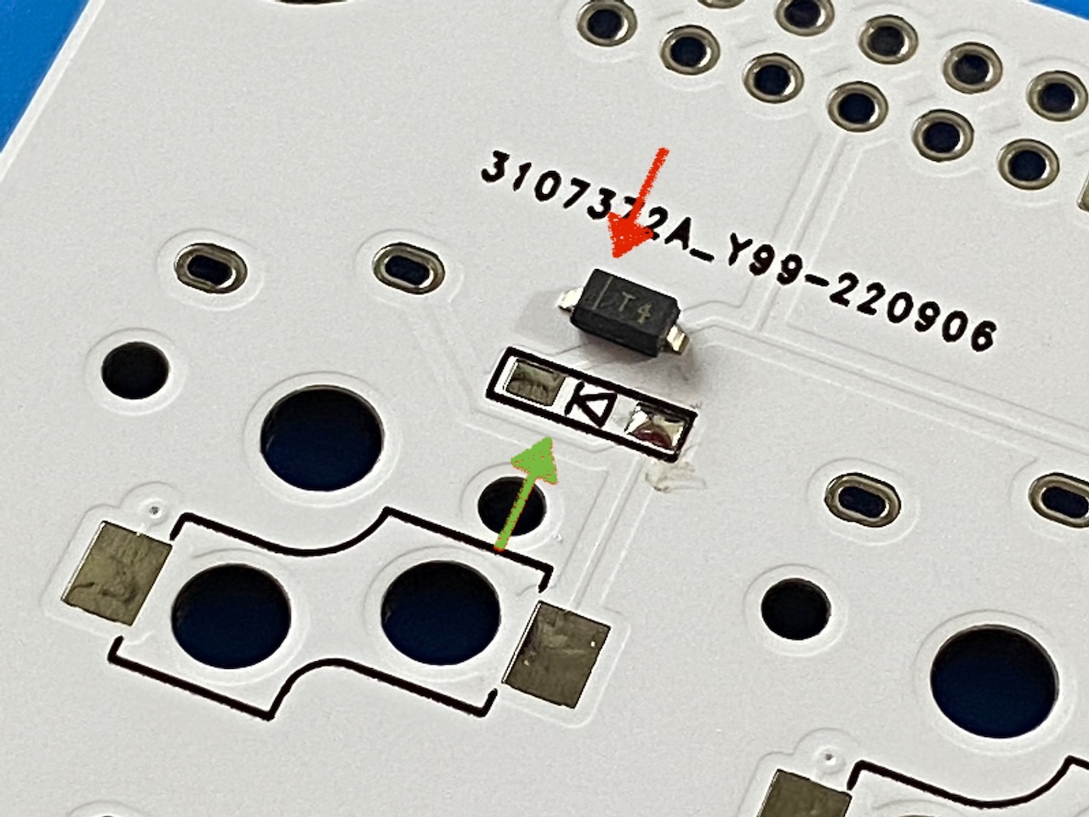
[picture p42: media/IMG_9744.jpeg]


3. 用鑷子固定，先焊一邊。
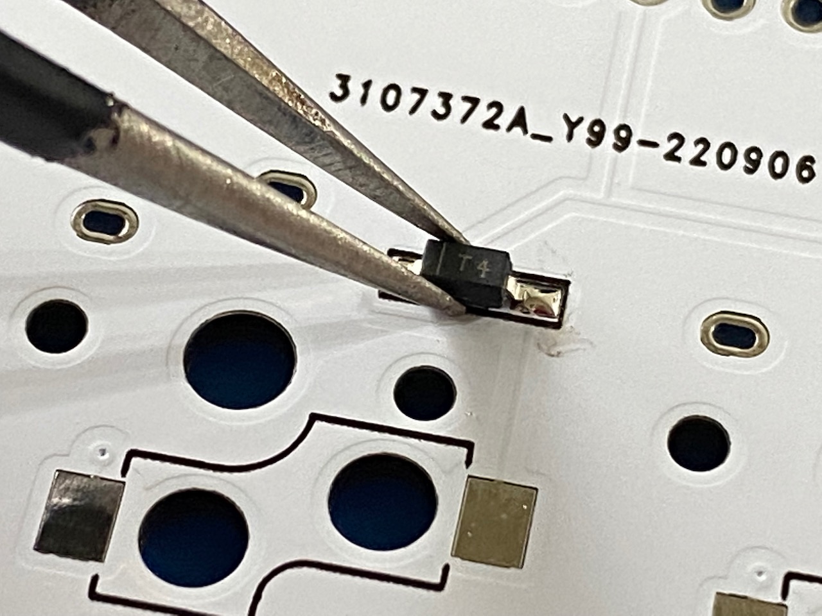
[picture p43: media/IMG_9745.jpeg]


4. 再焊另外一邊。登登，你就完成一個二極體了。接下來把剩下的33個二極體都焊起來吧。要注意，大部分的二極體都是直桿在右邊，但是少數上直槓在左邊，焊接前請注意。
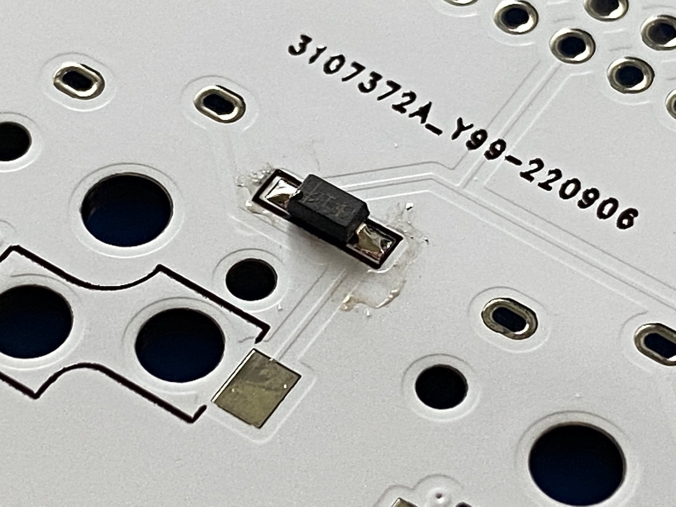
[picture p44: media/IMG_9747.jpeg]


5. 接下來焊接熱插拔座吧。先把它依照圖示放好。
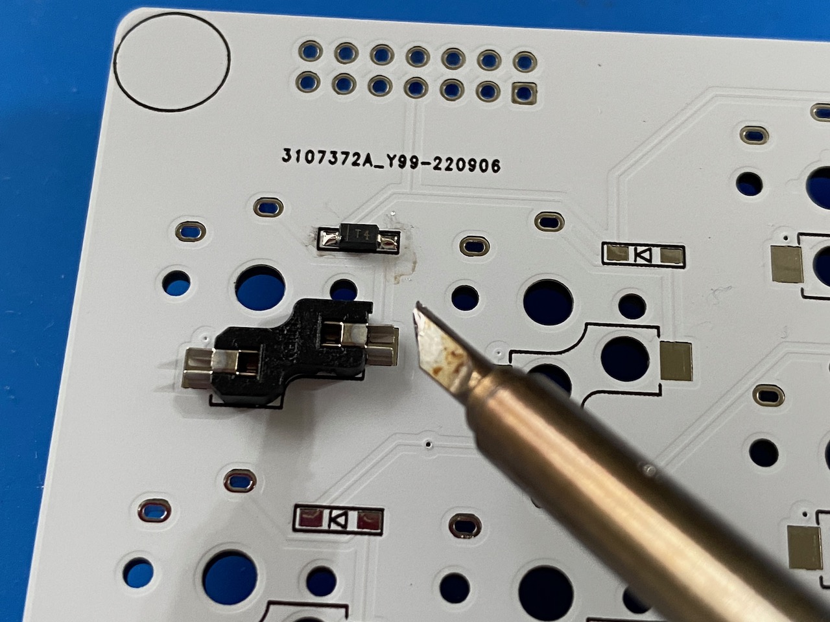
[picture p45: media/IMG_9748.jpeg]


6. 將兩邊焊上。注意，要看到焊錫同時吃到熱插拔座與電路板上。如下圖有爬錫的現象就對了。如果沒焊好，最後可以再回來補焊，沒關係。一樣反覆操作33次。這時候是不是覺得鍵盤很小很好啊。
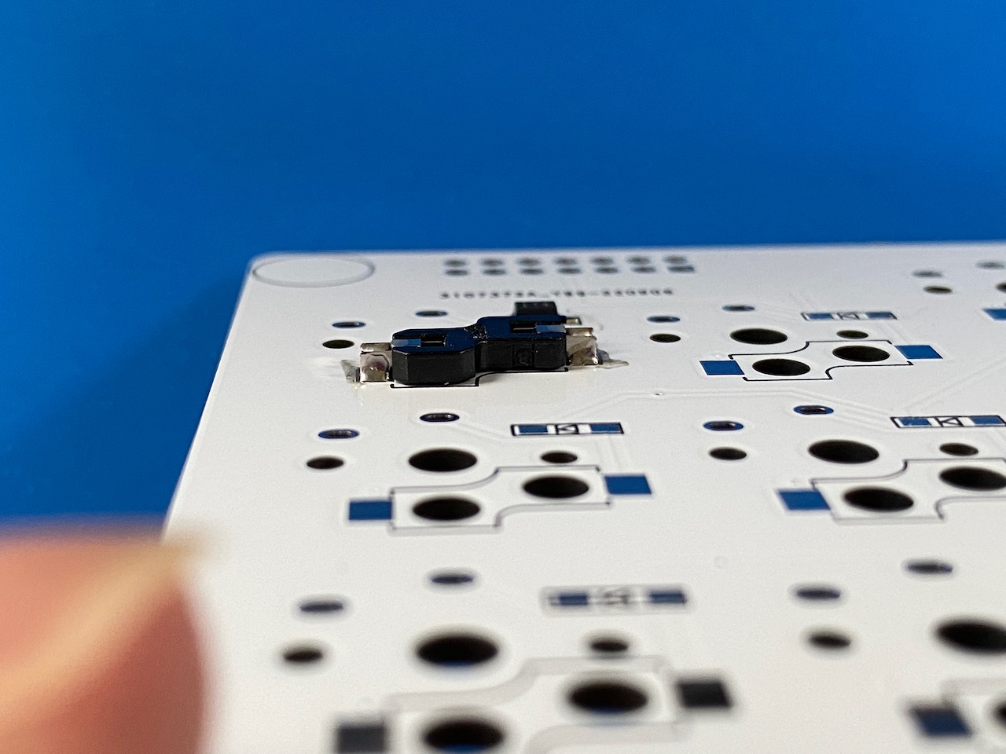
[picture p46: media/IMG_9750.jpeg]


7. 接下來就是要焊接牛角接頭。要注意凹槽圖示(紅色箭頭)與接頭上的凹槽(綠色箭頭)方向要一致。插入後翻面。
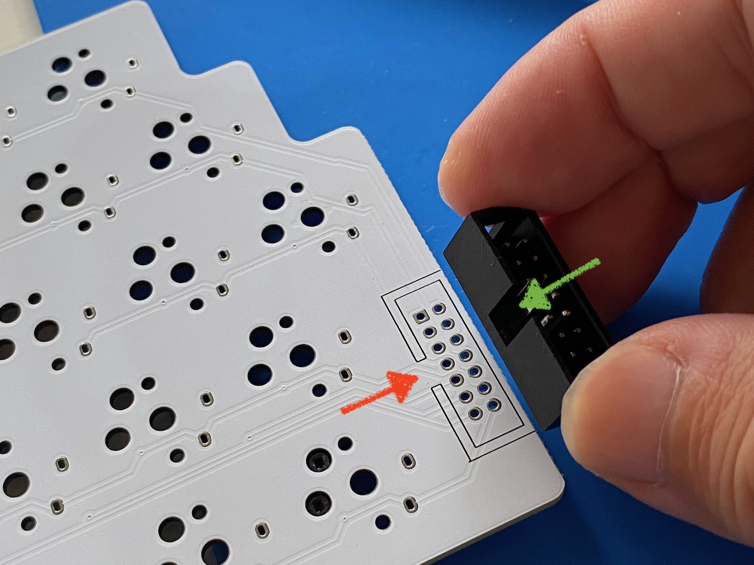
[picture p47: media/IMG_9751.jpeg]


8. 祕技出現了。將另外一個牛角接頭放在紅色箭頭處，此時鍵盤就是平的，等一下焊接時就不會歪了。將14個點焊上。
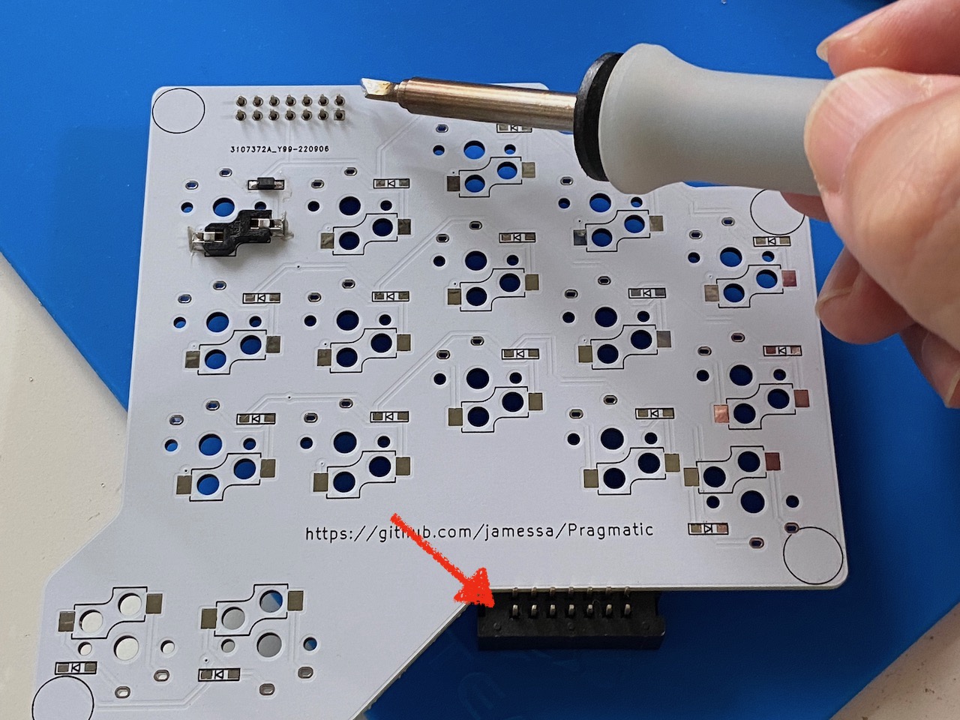
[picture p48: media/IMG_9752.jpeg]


9. 拿出鑷子，把防滑豆豆貼到鍵盤四周(黑色圈圈處)，達到最好的防滑效果。
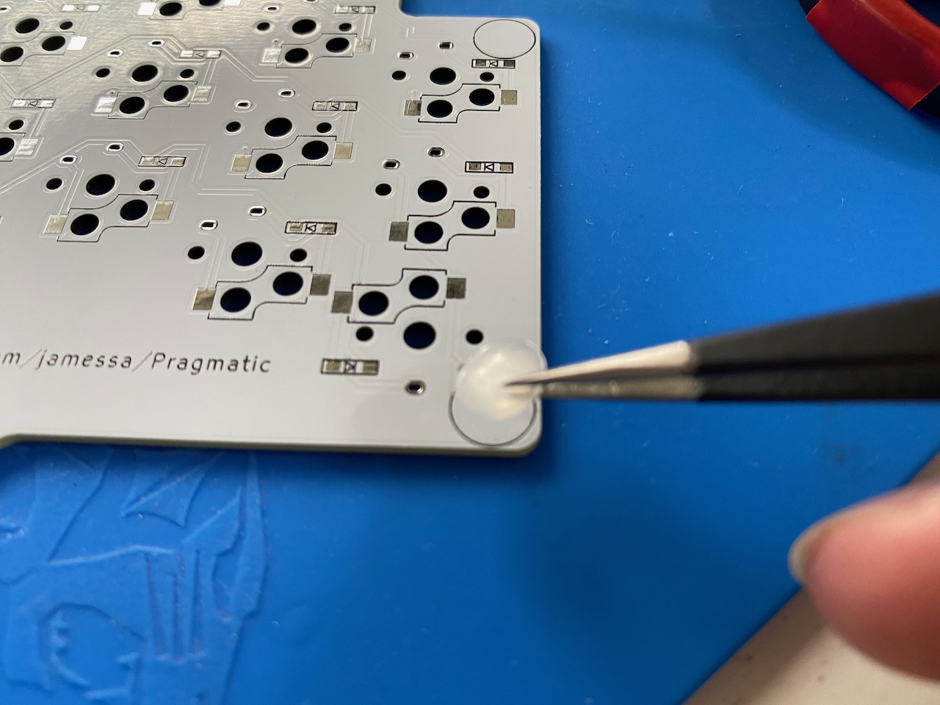
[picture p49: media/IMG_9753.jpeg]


10. 拿出外殼，把焊好的電路板卡上去。恭喜你完成一片手板，喝口水，看看遠方，然後從步驟一再來一次。
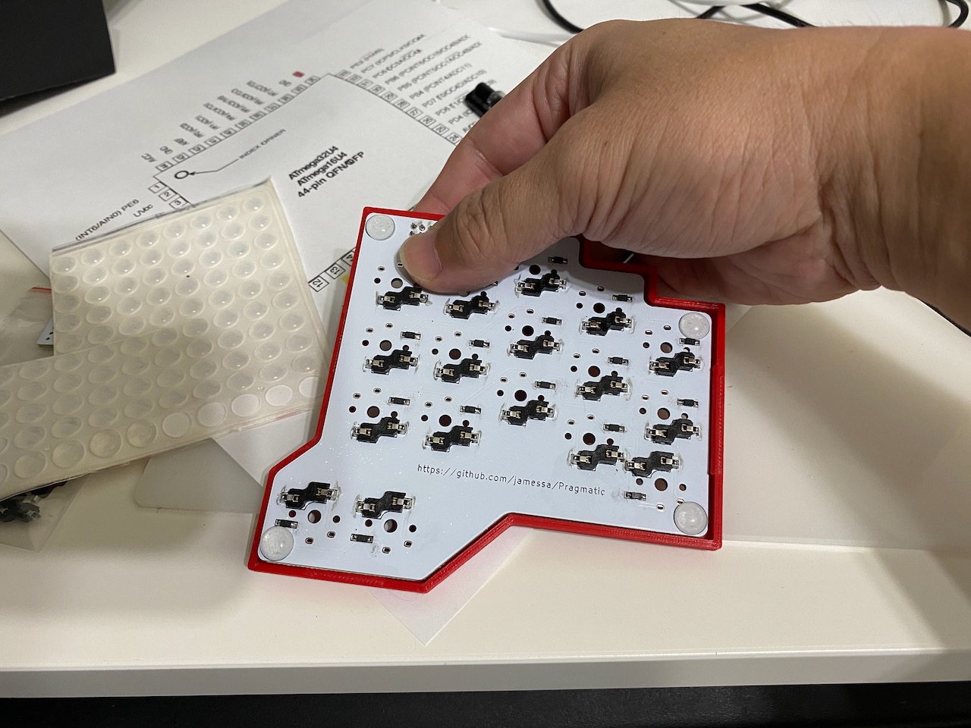
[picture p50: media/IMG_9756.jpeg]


# 主控版的製作
## OLED的焊接
1. (可省略)先把OLED針腳上面的塑膠墊片(紅色箭頭)拆除，這樣可以降低OLED的高度。如果覺得麻煩可以跳過。
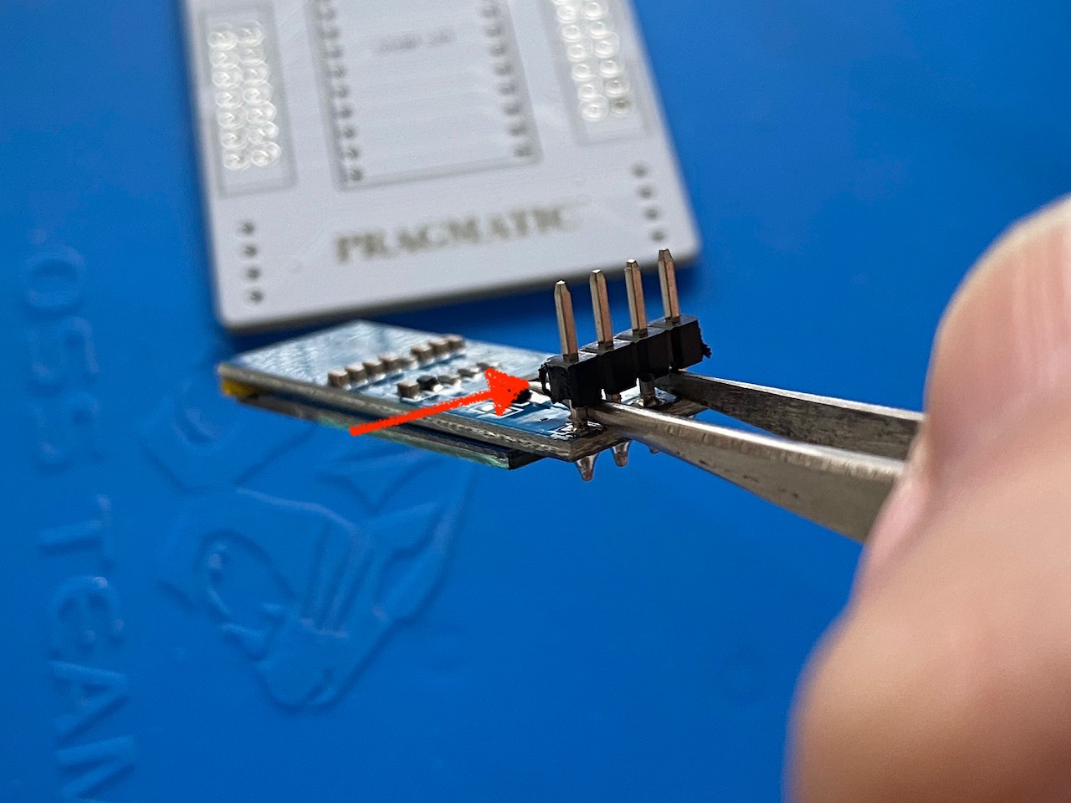
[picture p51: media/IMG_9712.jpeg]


拆起來以後像這樣。
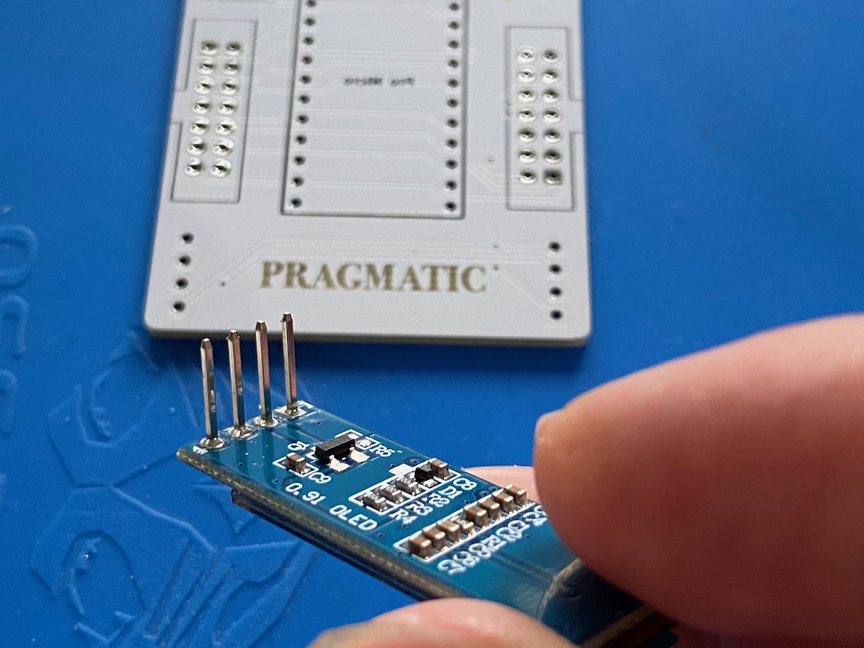
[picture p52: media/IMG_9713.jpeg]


2. 插入後主控版，要注意方向，針腳(紅色箭頭)在左。
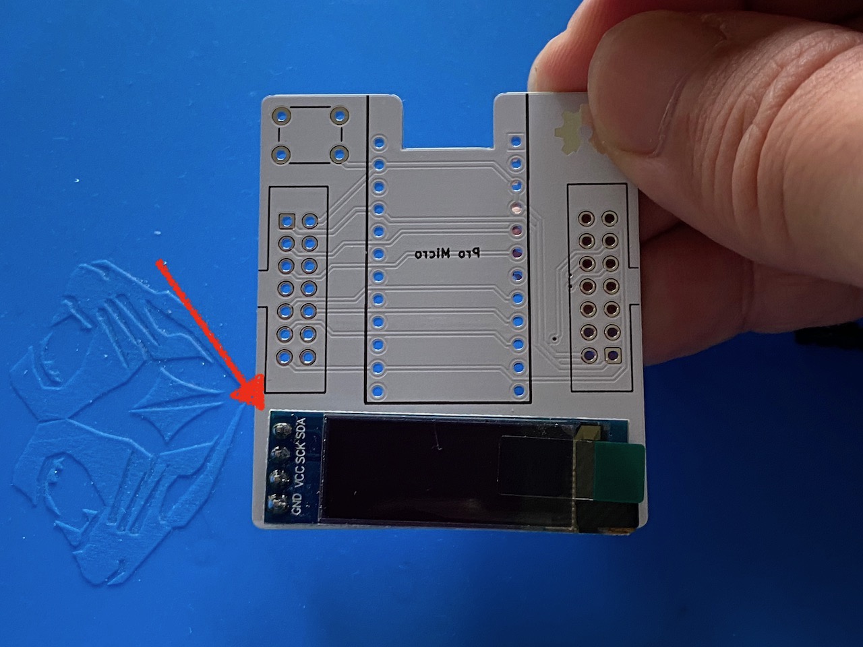
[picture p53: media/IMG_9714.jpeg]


3. 祕技二：逆焊法。將主控版直立起來大約60˚，讓OLED自然垂下，這樣會最好對齊。焊紅色箭頭那一支腳就好。看一下OLED板是不是跟主控版是平行的，如果歪太多會卡到牛角母座。
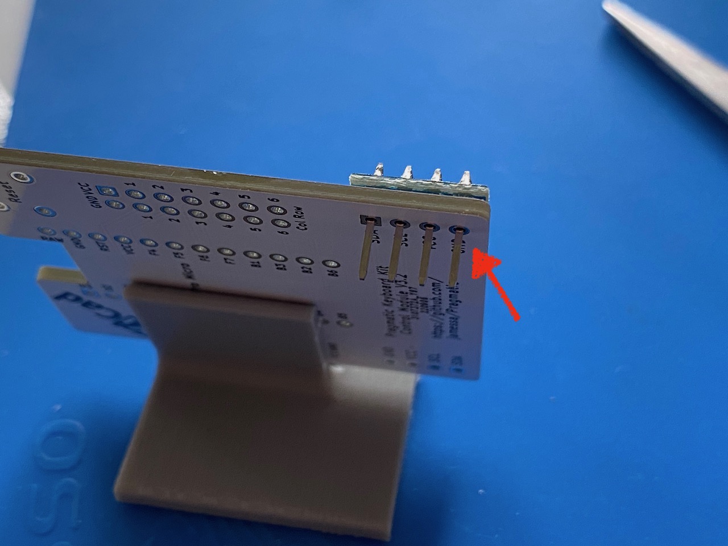
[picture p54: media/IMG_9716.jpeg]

 
4. 將多出來的排線剪掉。
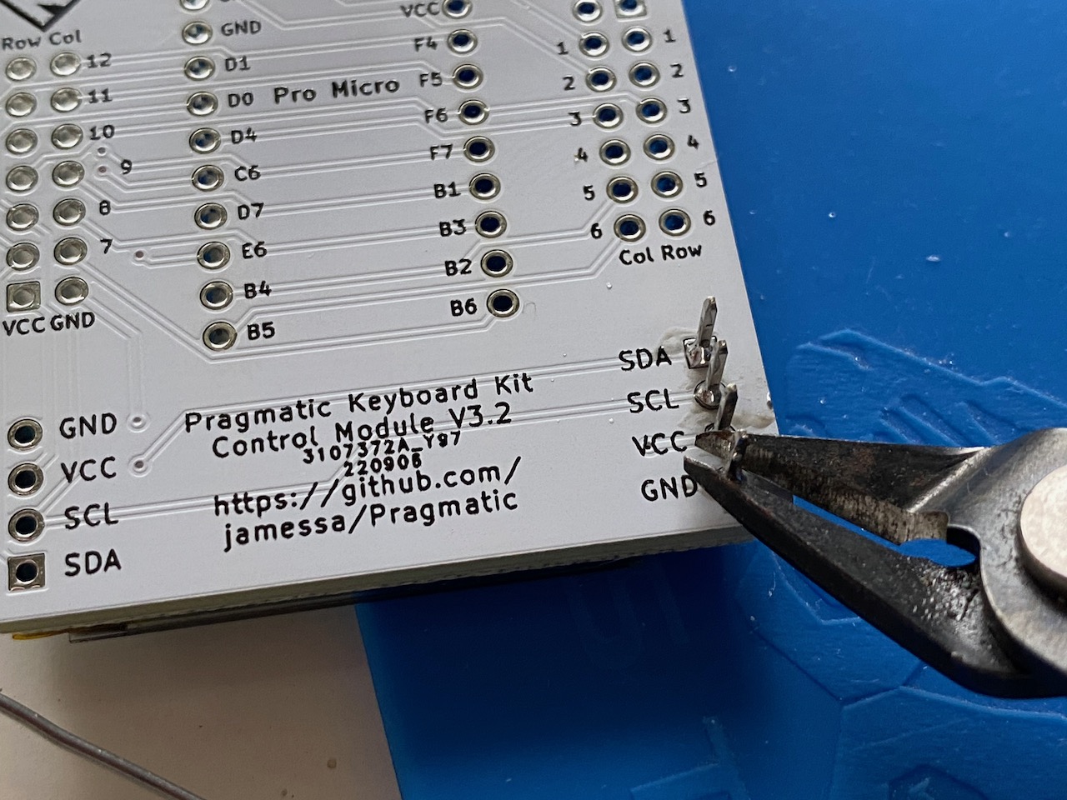
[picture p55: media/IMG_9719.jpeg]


5. 完成圖。
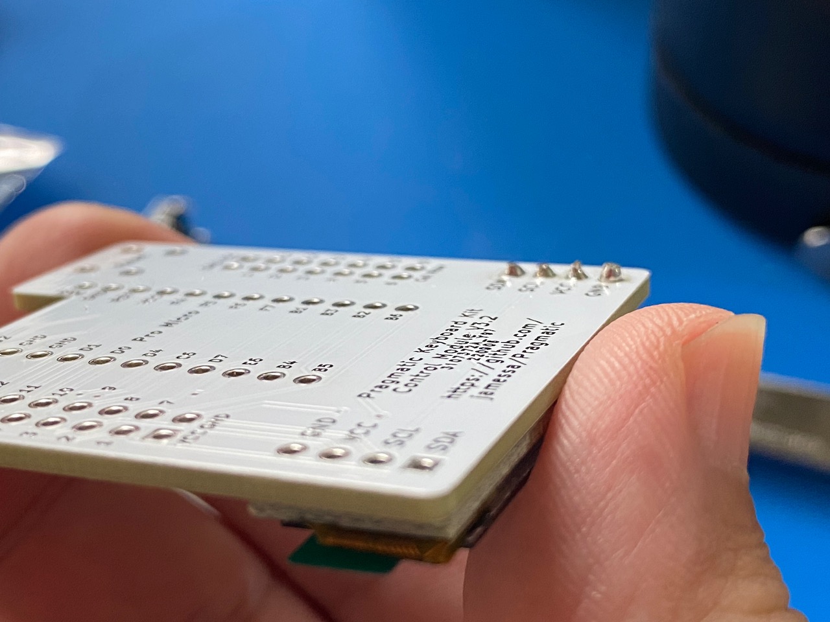
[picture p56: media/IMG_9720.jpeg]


## 重置鍵與開發版
1. 先將按鈕插入紅色箭頭處，這按鈕是長方形的，如果第一次插不進去，轉90˚再插一次即可。插入後就會自動卡住，不會掉下來。
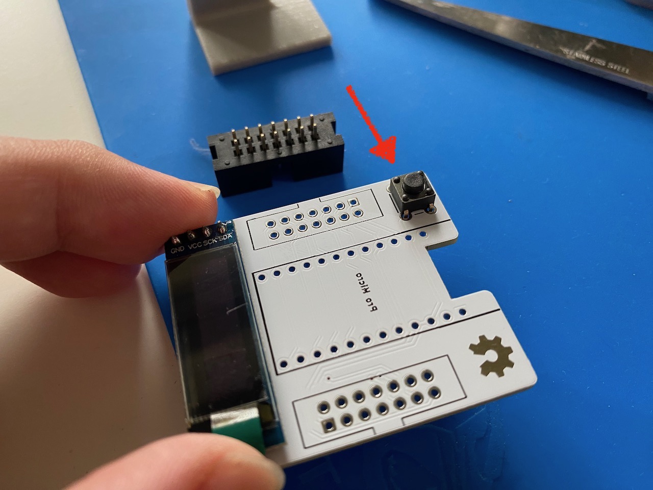
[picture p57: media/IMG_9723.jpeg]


2. 拿出14P的針腳，短頭朝上。 
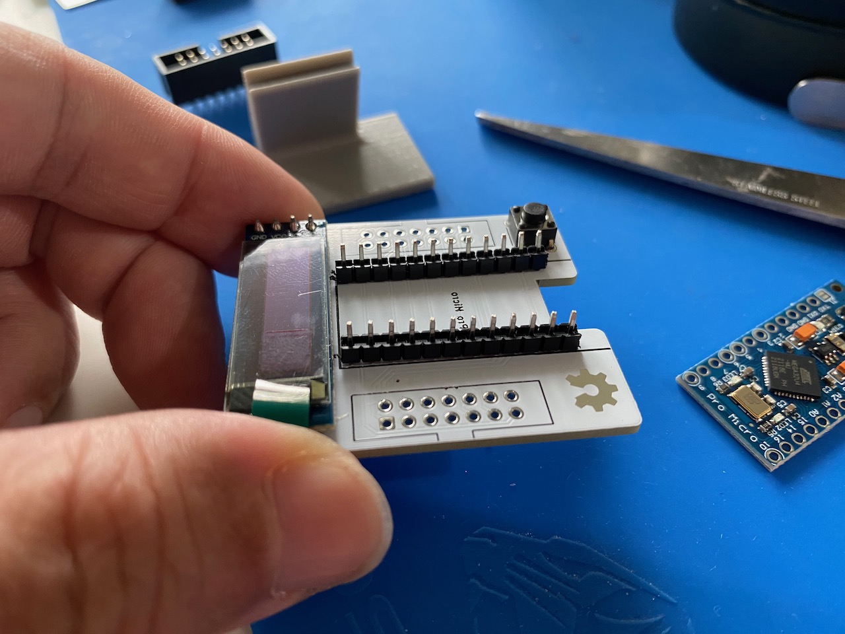
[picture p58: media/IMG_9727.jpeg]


3.  祕技三：橡皮筋固定法。把開發板反過來放上去，用橡皮筋綁起來固定。從側面看看有沒有歪，稍微調正一下讓各針腳都是直的。
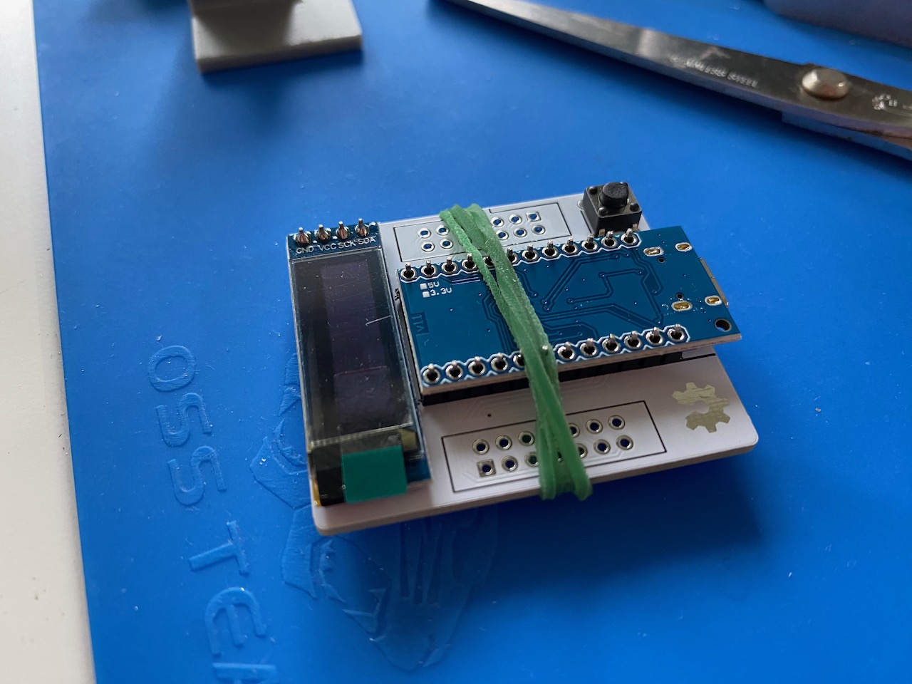
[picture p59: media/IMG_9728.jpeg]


4. 先焊四個角落，紅色箭頭處。其他點先不要焊，焊完後翻面。
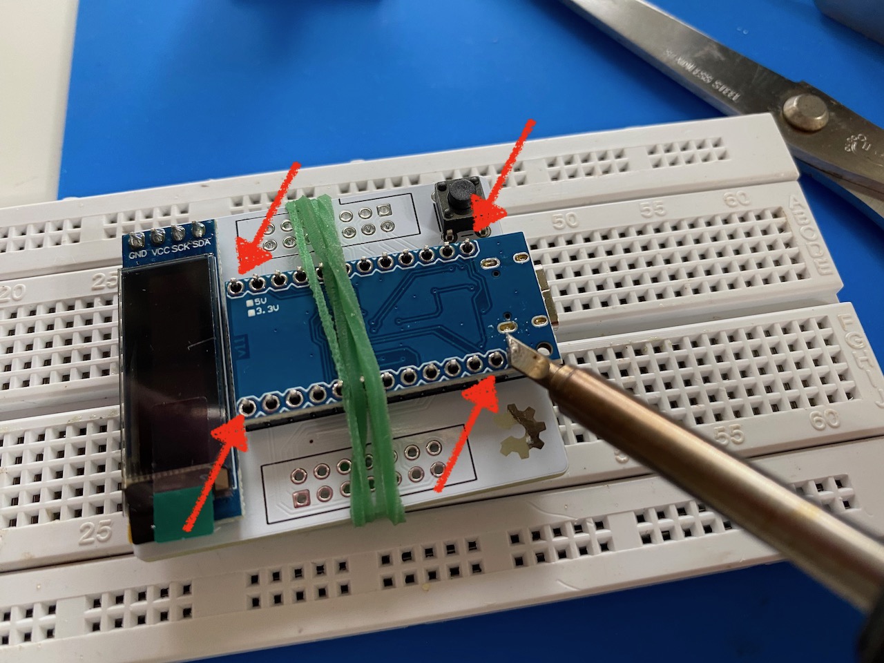
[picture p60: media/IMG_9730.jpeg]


5. 後面也是先焊四邊，紅色箭頭處。焊好四角以後，把橡皮筋拆掉，然後把所有的點都焊起來，正反兩面都要喔。焊後，再把多出來的針腳剪掉。
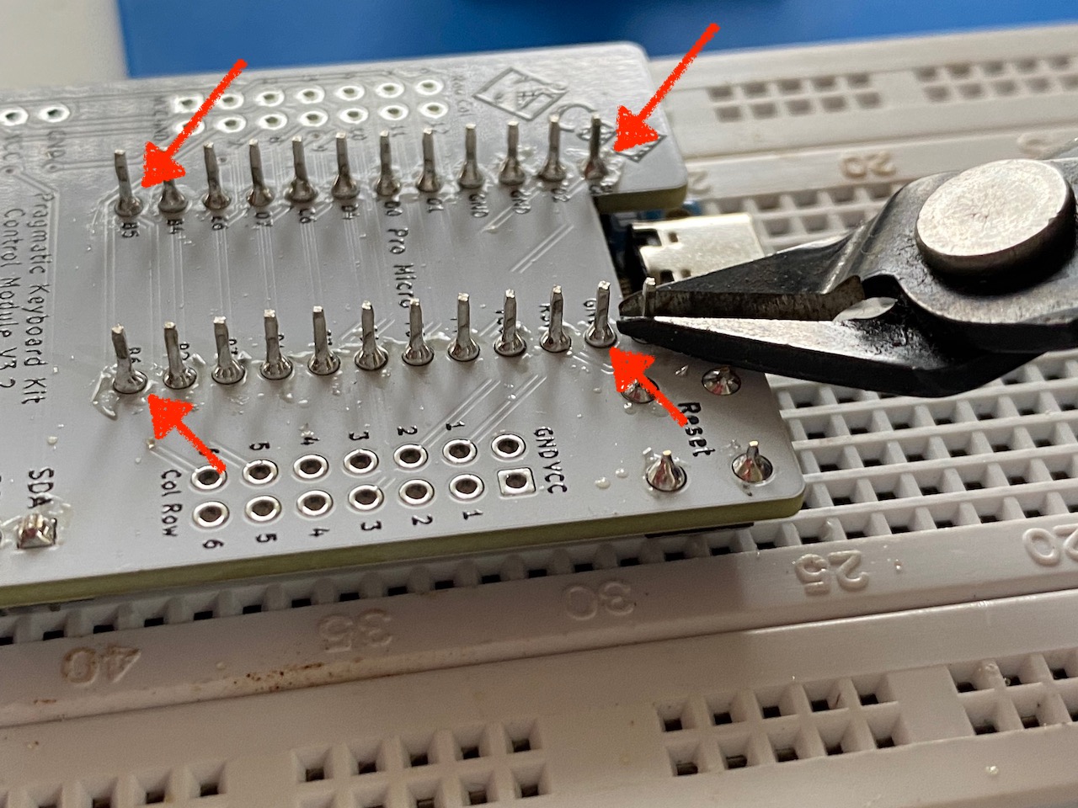
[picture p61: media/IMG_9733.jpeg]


6. 完成圖。
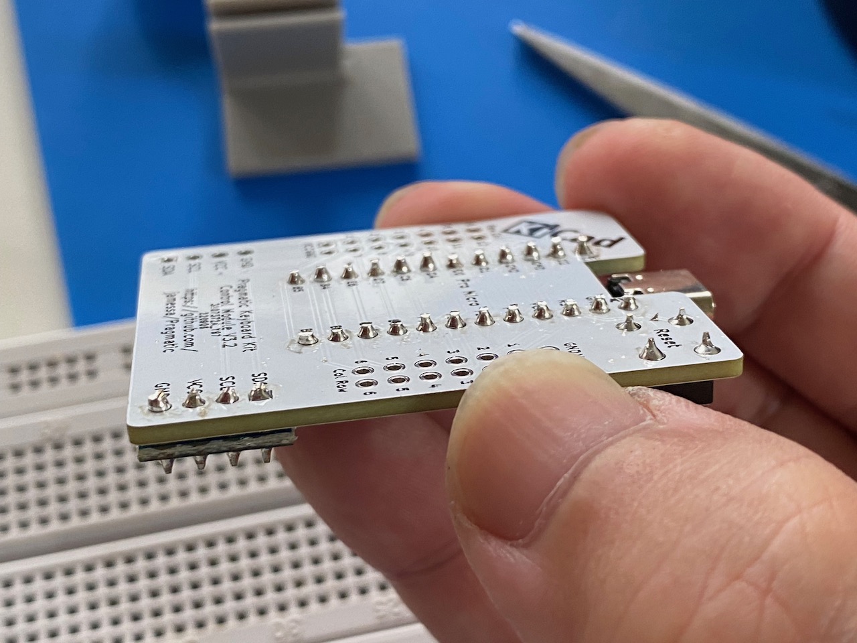
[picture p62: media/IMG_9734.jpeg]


## 牛角母座
1. 快要完成了。依照凹槽方向放入兩個牛角母座，兩個缺口都是朝外。小知識，牛角母座的英文叫做IDC connector是80年代常見的連結電子儀器的方式。
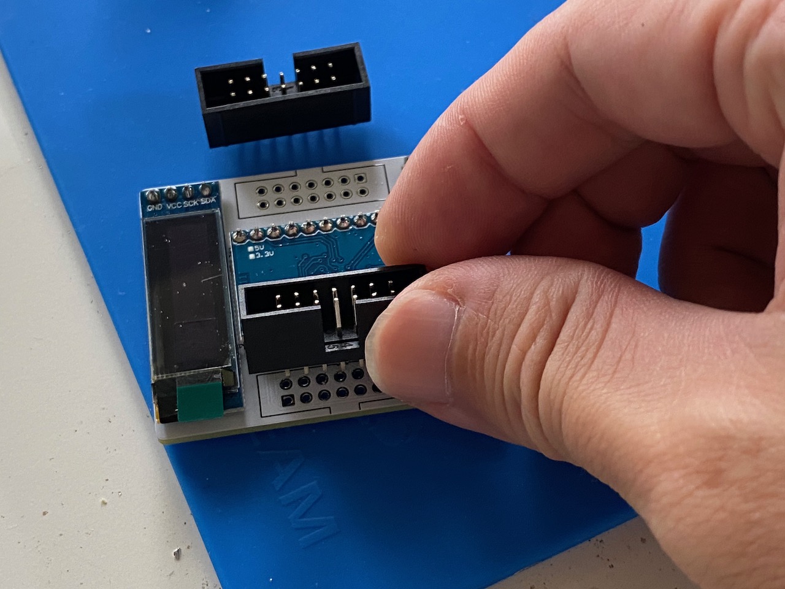
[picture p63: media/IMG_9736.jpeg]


2. 翻到背面依序焊起來即可。完成以後，檢查(欣賞)一下是不是每個點都有焊到。
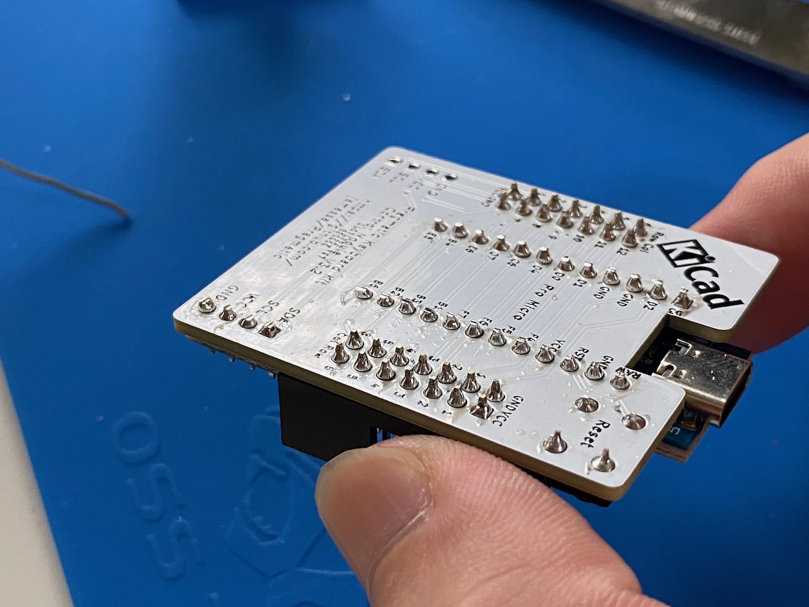
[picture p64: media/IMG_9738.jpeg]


## 完成圖

恭喜你打造了一把自己的鍵盤。
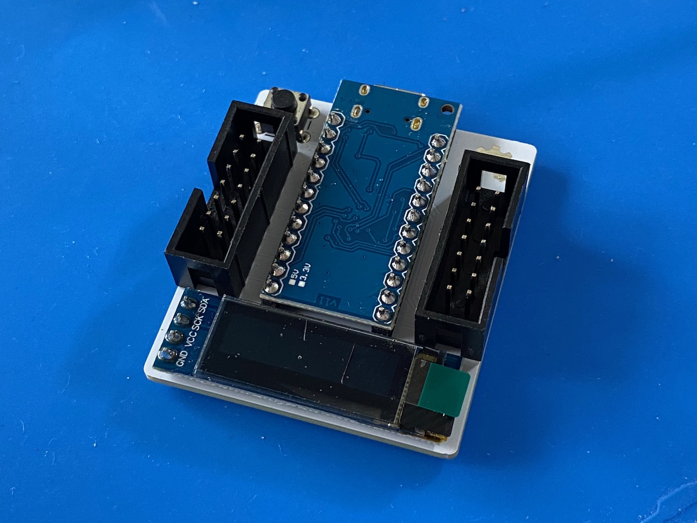
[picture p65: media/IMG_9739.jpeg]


# Troubleshooting

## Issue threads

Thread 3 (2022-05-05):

Couldn't send "m" key

peoplewhite, 2022-05-05:
Couldn't send "m" key signal when keyboard was initialized. It will be enabled after pressing it repeatedly. Weird.

This config will be OK.
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

This config will cause this issue I mentioned as title.
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

jamessa, 2022-05-06:
try with original qmk code base.
try disable Nkro.

jamessa, 2022-05-11:
It turns out to be a misconfiguration. In Combos tab,  `M` was accidentally set as first key of a combo. By clearing the combos, everything back to normal.

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

@peoplewhite please verify.

peoplewhite, 2022-06-14:
totally fixed. appreciate it. ❤️

Closed 2022-06-14.

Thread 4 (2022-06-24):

OLED的版本會在某些情況下freeze.

jamessa, 2022-06-24:
OLED的版本會在某些情況下freeze，會完全沒辦法輸出按鍵，沒有OLED訊號。但是非OLED的版本從來沒有遇過這個問題。

目前已知可以重現的方式
1. 在鍵盤直接插在電腦上時，關機。
2. 第二天起來，電腦開機，鍵盤就沒有反應了。

解決方法
先刷`make jsa/pragmatic34/v3:vial:flash`再刷`make jsa/pragmatic34/v3:oled:flash`就可以恢復正常。
但是如果直接重刷`make jsa/pragmatic34/v3:oled:flash`就沒有用。

下次再遇到時測試先清除eeprom看看。

jamessa, 2023-02-13:
OLED is deprecated.

Closed 2023-02-13.

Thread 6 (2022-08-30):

Type C to Type C don't work.

jamessa, 2022-08-30:
Can be reproduced on

- mbpr14+小米 typec 線. (hsinhung)
- iMac + unknown type C cable. (James)

Next step check Pro Micro pull up resistor.

jamessa, 2023-02-13:
fixed

Closed 2023-02-13.

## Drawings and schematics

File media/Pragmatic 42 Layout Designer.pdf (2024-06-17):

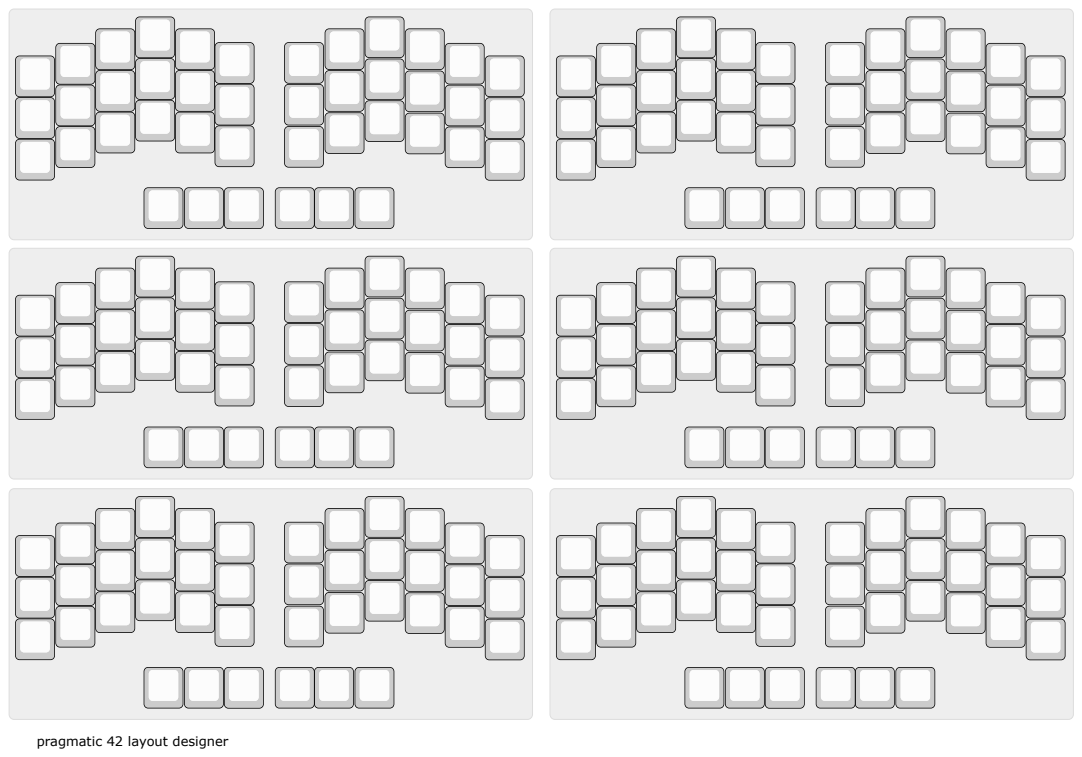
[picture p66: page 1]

pragmatic 42 layout designer

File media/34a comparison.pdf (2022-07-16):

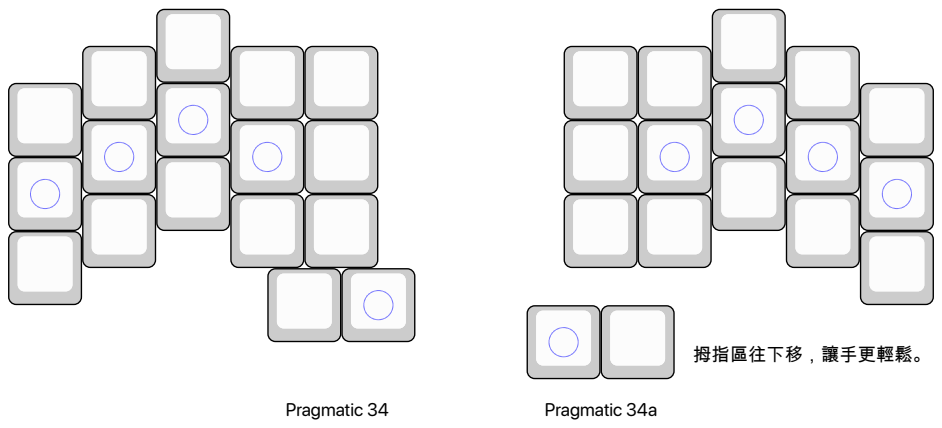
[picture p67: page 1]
Pragmatic 34; Pragmatic 34a; 拇指區往下移，讓手更輕鬆。

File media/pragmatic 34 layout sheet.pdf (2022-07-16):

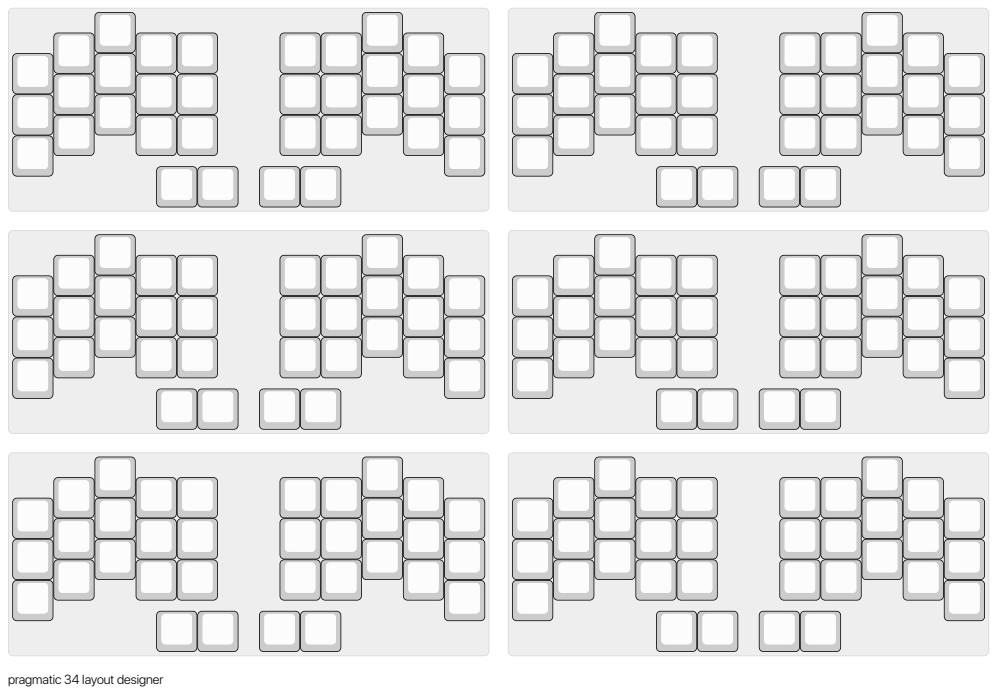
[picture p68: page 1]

pragmatic 34 layout designer

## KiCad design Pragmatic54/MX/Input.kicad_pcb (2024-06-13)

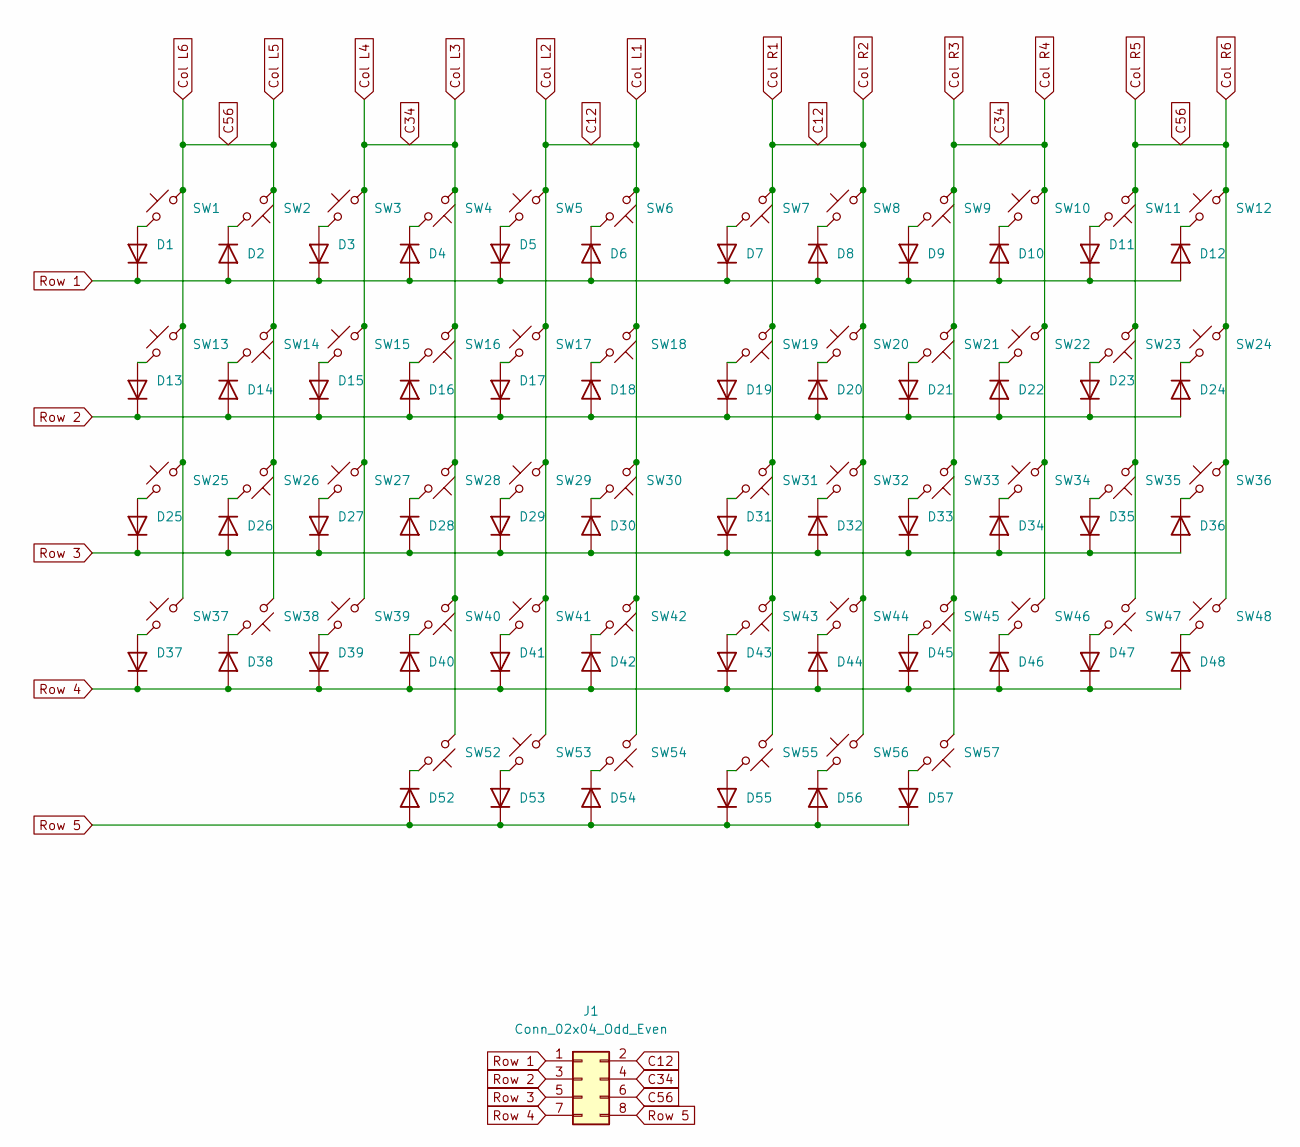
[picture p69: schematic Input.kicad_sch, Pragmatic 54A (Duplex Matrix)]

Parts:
D1, D2, D3, D4, D5, D6, D7, D8, D9, D10, D11, D12, D13, D14, D15, D16, D17, D18, D19, D20, D21, D22, D23, D24, D25, D26, D27, D28, D29, D30, D31, D32, D33, D34, D35, D36, D37, D38, D39, D40, D41, D42, D43, D44, D45, D46, D47, D48, D52, D53, D54, D55, D56, D57: 1N4448W; D3_SMD_v2
J1: Conn_02x04_Odd_Even; matrix_connector
SW1, SW2, SW3, SW4, SW5, SW6, SW13, SW14, SW15, SW16, SW17, SW18, SW25, SW26, SW27, SW28, SW29, SW30, SW37, SW38, SW39, SW40, SW41, SW42, SW52, SW53, SW54: SW_Push_45deg; MX_Hotswap Reverse
SW7, SW8, SW9, SW10, SW11, SW12, SW19, SW20, SW21, SW22, SW23, SW24, SW31, SW32, SW33, SW34, SW35, SW36, SW43, SW44, SW45, SW46, SW47, SW48, SW55, SW56, SW57: SW_Push_45deg; MX_Hotswap

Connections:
C12: J1.2, SW5.2, SW6.1, SW7.1, SW8.2, SW17.2, SW18.1, SW19.1, SW20.2, SW29.2, SW30.1, SW31.1, SW32.2, SW41.2, SW42.1, SW43.1, SW44.2, SW53.2, SW54.1, SW55.1, SW56.2
C34: J1.4, SW3.2, SW4.1, SW9.1, SW10.2, SW15.2, SW16.1, SW21.1, SW22.2, SW27.2, SW28.1, SW33.1, SW34.2, SW39.2, SW40.1, SW45.1, SW46.2, SW52.1, SW57.1
C56: J1.6, SW1.2, SW2.1, SW11.1, SW12.2, SW13.2, SW14.1, SW23.1, SW24.2, SW25.2, SW26.1, SW35.1, SW36.2, SW37.2, SW38.1, SW47.1, SW48.2
unnamed: D1.2 (A), SW1.1
unnamed: D2.1 (K), SW2.2
unnamed: D3.2 (A), SW3.1
unnamed: D4.1 (K), SW4.2
unnamed: D5.2 (A), SW5.1
unnamed: D6.1 (K), SW6.2
unnamed: D7.2 (A), SW7.2
unnamed: D8.1 (K), SW8.1
unnamed: D9.2 (A), SW9.2
unnamed: D10.1 (K), SW10.1
unnamed: D11.2 (A), SW11.2
unnamed: D12.1 (K), SW12.1
unnamed: D13.2 (A), SW13.1
unnamed: D14.1 (K), SW14.2
unnamed: D15.2 (A), SW15.1
unnamed: D16.1 (K), SW16.2
unnamed: D17.2 (A), SW17.1
unnamed: D18.1 (K), SW18.2
unnamed: D19.2 (A), SW19.2
unnamed: D20.1 (K), SW20.1
unnamed: D21.2 (A), SW21.2
unnamed: D22.1 (K), SW22.1
unnamed: D23.2 (A), SW23.2
unnamed: D24.1 (K), SW24.1
unnamed: D25.2 (A), SW25.1
unnamed: D26.1 (K), SW26.2
unnamed: D27.2 (A), SW27.1
unnamed: D28.1 (K), SW28.2
unnamed: D29.2 (A), SW29.1
unnamed: D30.1 (K), SW30.2
unnamed: D31.2 (A), SW31.2
unnamed: D32.1 (K), SW32.1
unnamed: D33.2 (A), SW33.2
unnamed: D34.1 (K), SW34.1
unnamed: D35.2 (A), SW35.2
unnamed: D36.1 (K), SW36.1
unnamed: D37.2 (A), SW37.1
unnamed: D38.1 (K), SW38.2
unnamed: D39.2 (A), SW39.1
unnamed: D40.1 (K), SW40.2
unnamed: D41.2 (A), SW41.1
unnamed: D42.1 (K), SW42.2
unnamed: D43.2 (A), SW43.2
unnamed: D44.1 (K), SW44.1
unnamed: D45.2 (A), SW45.2
unnamed: D46.1 (K), SW46.1
unnamed: D47.2 (A), SW47.2
unnamed: D48.1 (K), SW48.1
unnamed: D52.1 (K), SW52.2
unnamed: D53.2 (A), SW53.1
unnamed: D54.1 (K), SW54.2
unnamed: D55.2 (A), SW55.2
unnamed: D56.1 (K), SW56.1
unnamed: D57.2 (A), SW57.2
Row 1: D1.1 (K), D2.2 (A), D3.1 (K), D4.2 (A), D5.1 (K), D6.2 (A), D7.1 (K), D8.2 (A), D9.1 (K), D10.2 (A), D11.1 (K), D12.2 (A), J1.1
Row 2: D13.1 (K), D14.2 (A), D15.1 (K), D16.2 (A), D17.1 (K), D18.2 (A), D19.1 (K), D20.2 (A), D21.1 (K), D22.2 (A), D23.1 (K), D24.2 (A), J1.3
Row 3: D25.1 (K), D26.2 (A), D27.1 (K), D28.2 (A), D29.1 (K), D30.2 (A), D31.1 (K), D32.2 (A), D33.1 (K), D34.2 (A), D35.1 (K), D36.2 (A), J1.5
Row 4: D37.1 (K), D38.2 (A), D39.1 (K), D40.2 (A), D41.1 (K), D42.2 (A), D43.1 (K), D44.2 (A), D45.1 (K), D46.2 (A), D47.1 (K), D48.2 (A), J1.7
Row 5: D52.2 (A), D53.1 (K), D54.2 (A), D55.1 (K), D56.2 (A), D57.1 (K), J1.8

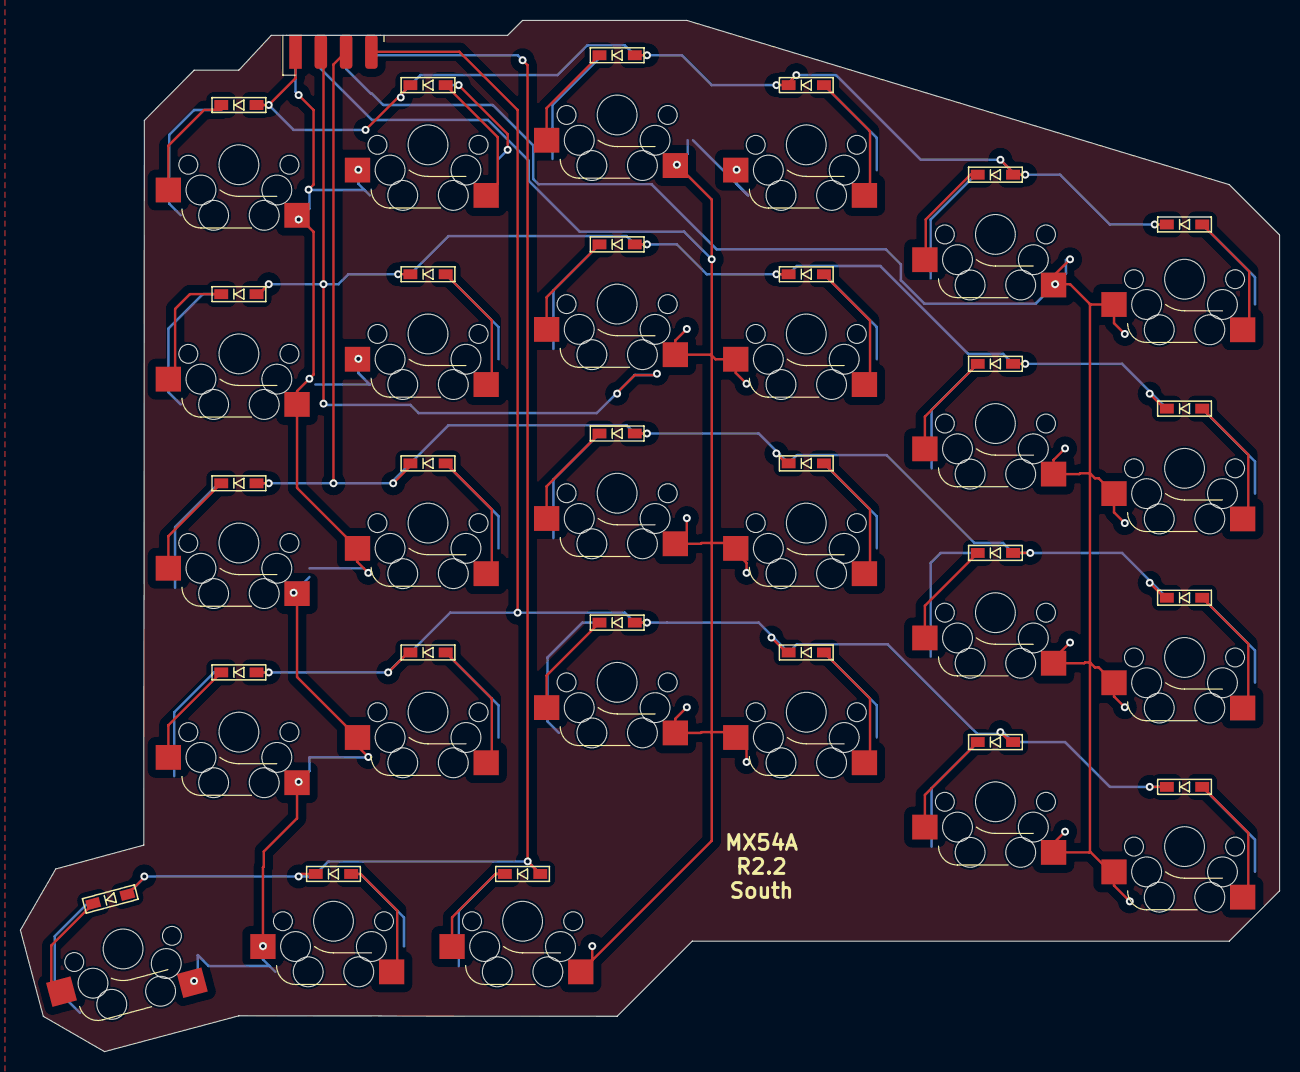
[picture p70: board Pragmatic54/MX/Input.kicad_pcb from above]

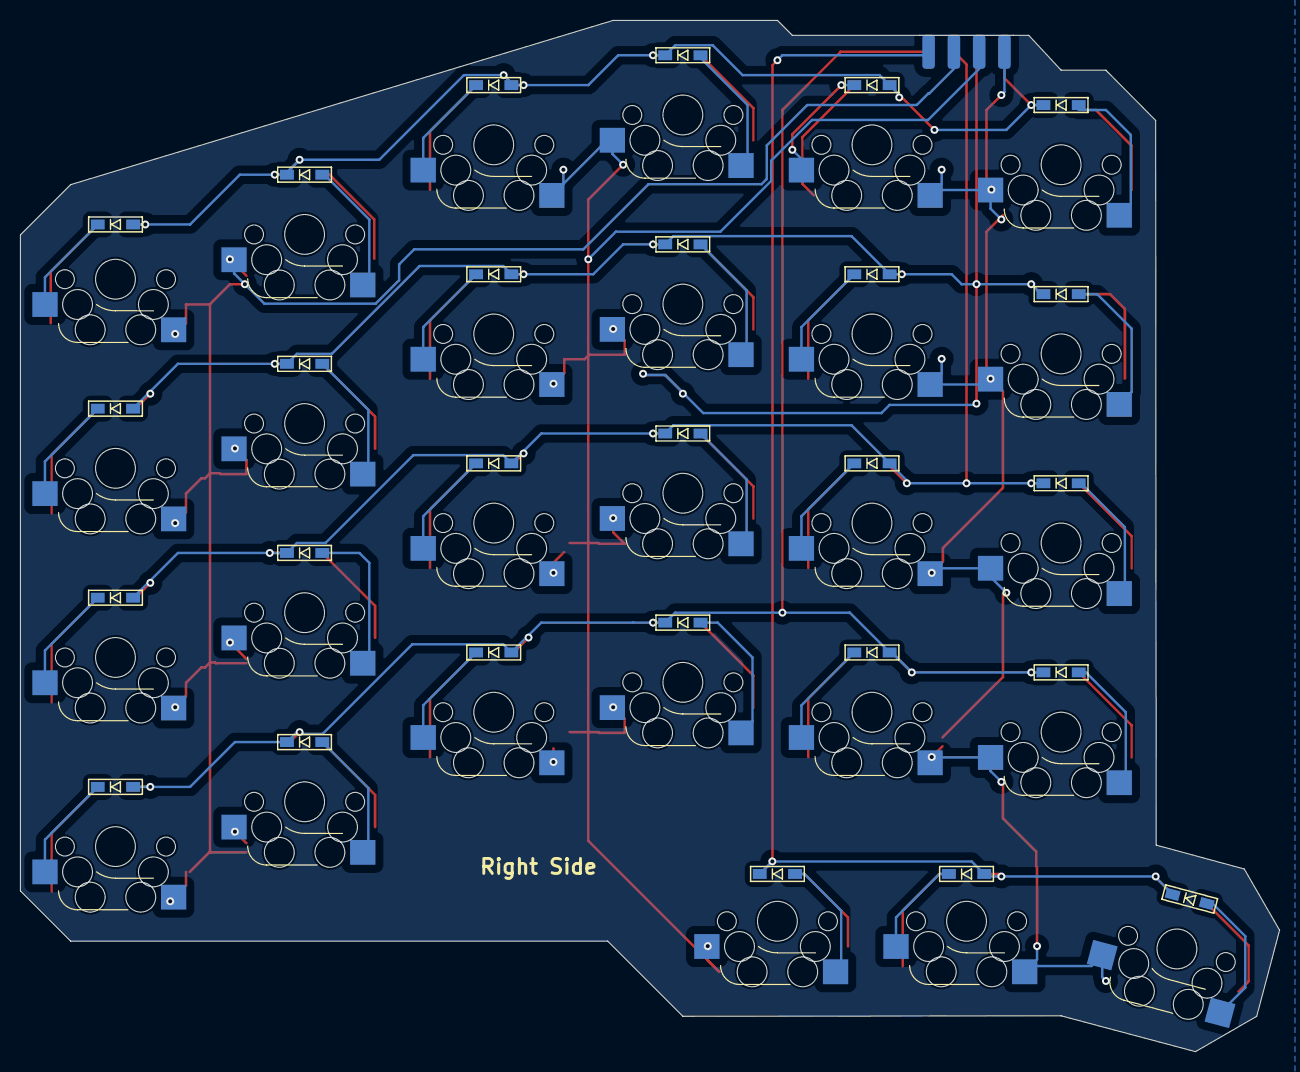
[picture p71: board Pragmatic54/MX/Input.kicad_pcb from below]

Board: 2 copper layers, 126.5 x 103.6 mm, 109 parts (27 on the bottom side), 62 nets.

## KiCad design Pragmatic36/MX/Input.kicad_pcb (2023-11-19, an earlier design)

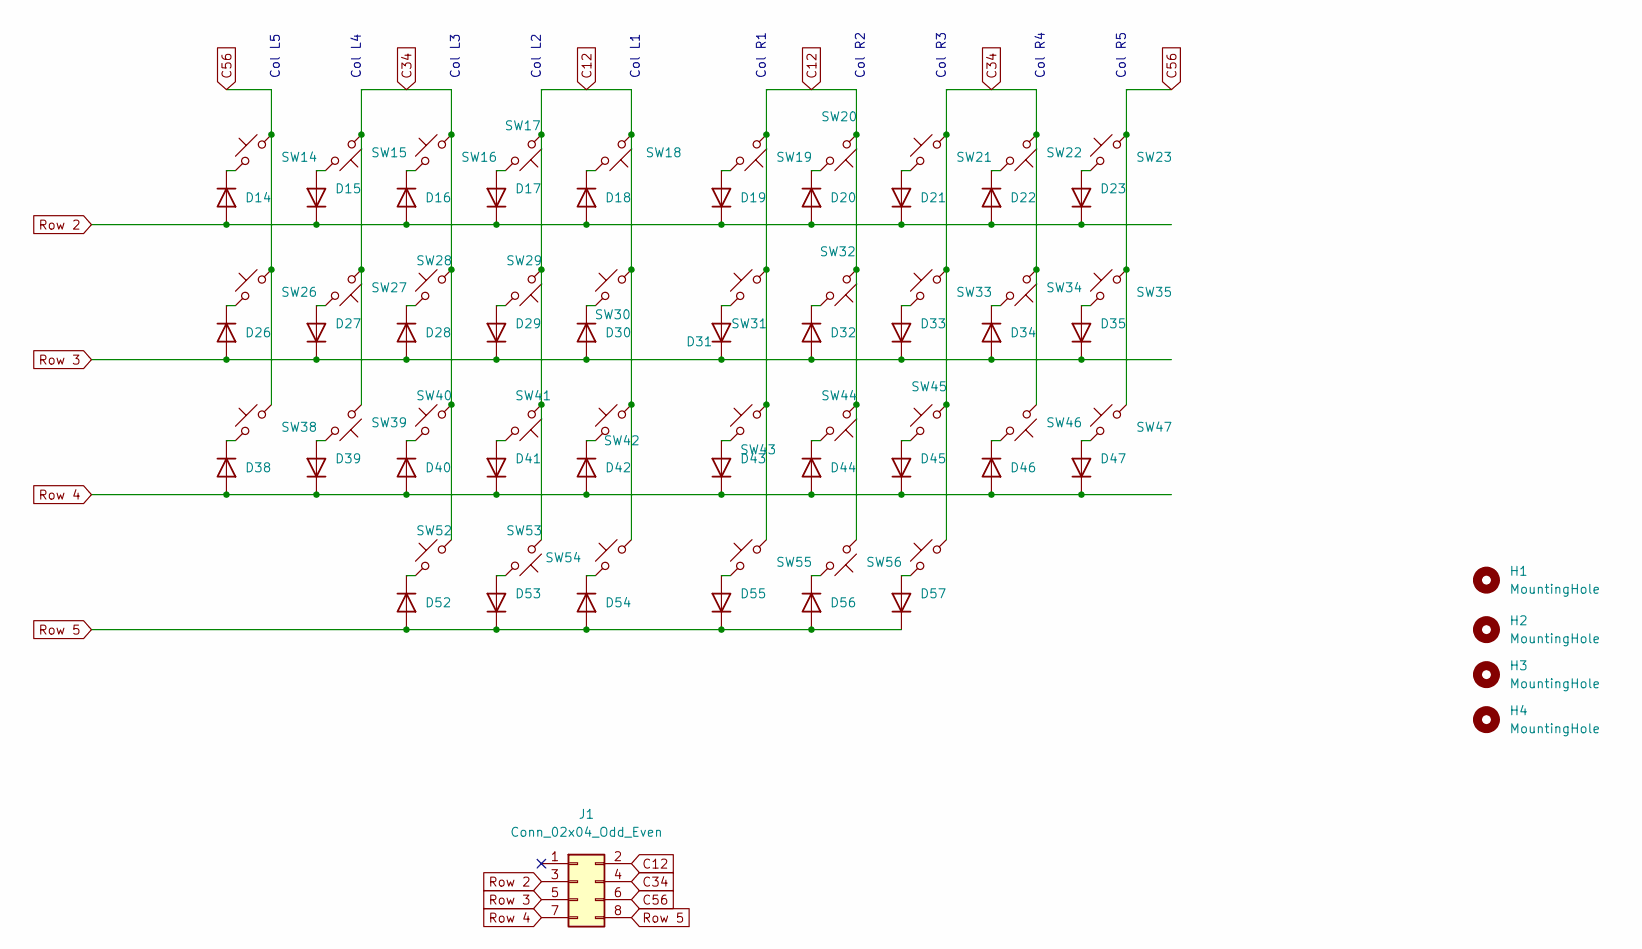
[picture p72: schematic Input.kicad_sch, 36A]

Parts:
D14, D15, D16, D17, D18, D19, D20, D21, D22, D23, D26, D27, D28, D29, D30, D31, D32, D33, D34, D35, D38, D39, D40, D41, D42, D43, D44, D45, D46, D47, D52, D53, D54, D55, D56, D57: 1N4448W; D3_SMD_v2
H1, H2, H3, H4: MountingHole; MountingHole_3.2mm_M3_DIN965
J1: Conn_02x04_Odd_Even; matrix_connector
SW14, SW15, SW16, SW17, SW18, SW26, SW27, SW28, SW29, SW30, SW38, SW39, SW40, SW41, SW42, SW52, SW53, SW54: SW_Push_45deg; MX_Hotswap Reverse
SW19, SW20, SW21, SW22, SW23, SW31, SW32, SW33, SW34, SW35, SW43, SW44, SW45, SW46, SW47: SW_Push_45deg; MX_Hotswap
SW55, SW56, SW57: SW_Push_45deg; MX_Hotswap_KH

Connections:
C12: J1.2, SW17.1, SW18.1, SW19.1, SW20.1, SW29.1, SW30.2, SW31.2, SW32.1, SW41.1, SW42.2, SW43.2, SW44.1, SW53.1, SW54.2, SW55.2, SW56.1
C34: J1.4, SW15.1, SW16.2, SW21.2, SW22.1, SW27.1, SW28.2, SW33.2, SW34.1, SW39.1, SW40.2, SW45.2, SW46.1, SW52.2, SW57.2
C56: J1.6, SW14.2, SW23.2, SW26.2, SW35.2, SW38.2, SW47.2
unnamed: D14.1 (K), SW14.1
unnamed: D15.2 (A), SW15.2
unnamed: D16.1 (K), SW16.1
unnamed: D17.2 (A), SW17.2
unnamed: D18.1 (K), SW18.2
unnamed: D19.2 (A), SW19.2
unnamed: D20.1 (K), SW20.2
unnamed: D21.2 (A), SW21.1
unnamed: D22.1 (K), SW22.2
unnamed: D23.2 (A), SW23.1
unnamed: D26.1 (K), SW26.1
unnamed: D27.2 (A), SW27.2
unnamed: D28.1 (K), SW28.1
unnamed: D29.2 (A), SW29.2
unnamed: D30.1 (K), SW30.1
unnamed: D31.2 (A), SW31.1
unnamed: D32.1 (K), SW32.2
unnamed: D33.2 (A), SW33.1
unnamed: D34.1 (K), SW34.2
unnamed: D35.2 (A), SW35.1
unnamed: D38.1 (K), SW38.1
unnamed: D39.2 (A), SW39.2
unnamed: D40.1 (K), SW40.1
unnamed: D41.2 (A), SW41.2
unnamed: D42.1 (K), SW42.1
unnamed: D43.2 (A), SW43.1
unnamed: D44.1 (K), SW44.2
unnamed: D45.2 (A), SW45.1
unnamed: D46.1 (K), SW46.2
unnamed: D47.2 (A), SW47.1
unnamed: D52.1 (K), SW52.1
unnamed: D53.2 (A), SW53.2
unnamed: D54.1 (K), SW54.1
unnamed: D55.2 (A), SW55.1
unnamed: D56.1 (K), SW56.2
unnamed: D57.2 (A), SW57.1
Row 2: D14.2 (A), D15.1 (K), D16.2 (A), D17.1 (K), D18.2 (A), D19.1 (K), D20.2 (A), D21.1 (K), D22.2 (A), D23.1 (K), J1.3
Row 3: D26.2 (A), D27.1 (K), D28.2 (A), D29.1 (K), D30.2 (A), D31.1 (K), D32.2 (A), D33.1 (K), D34.2 (A), D35.1 (K), J1.5
Row 4: D38.2 (A), D39.1 (K), D40.2 (A), D41.1 (K), D42.2 (A), D43.1 (K), D44.2 (A), D45.1 (K), D46.2 (A), D47.1 (K), J1.7
Row 5: D52.2 (A), D53.1 (K), D54.2 (A), D55.1 (K), D56.2 (A), D57.1 (K), J1.8

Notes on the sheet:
Col L4
Col R1
Col L1
Col R5
Col R3
Col L3
Col L5
Col R2
Col R4
Col L2

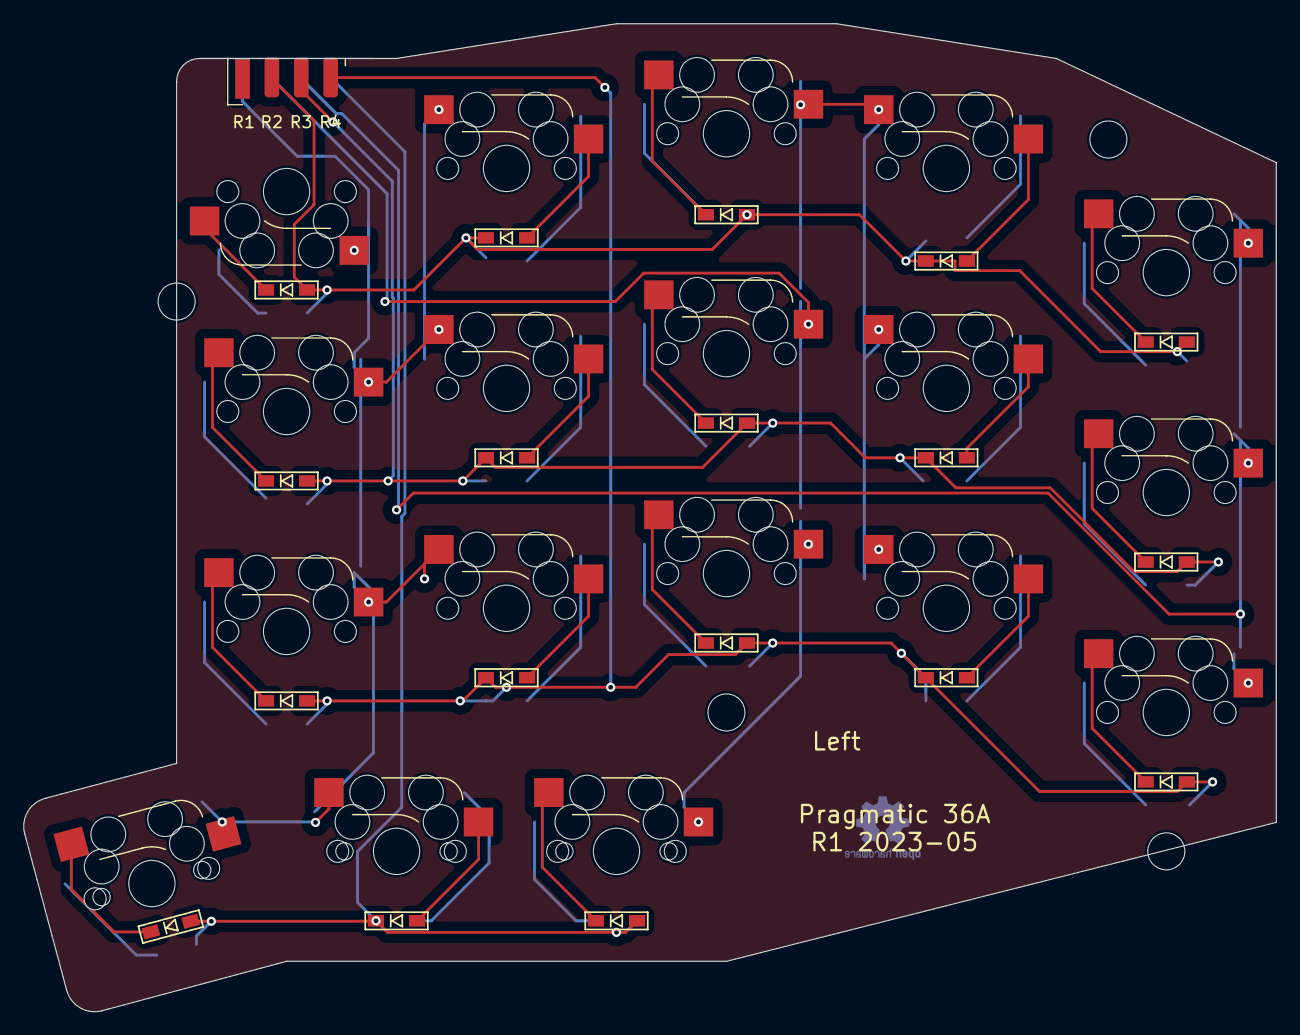
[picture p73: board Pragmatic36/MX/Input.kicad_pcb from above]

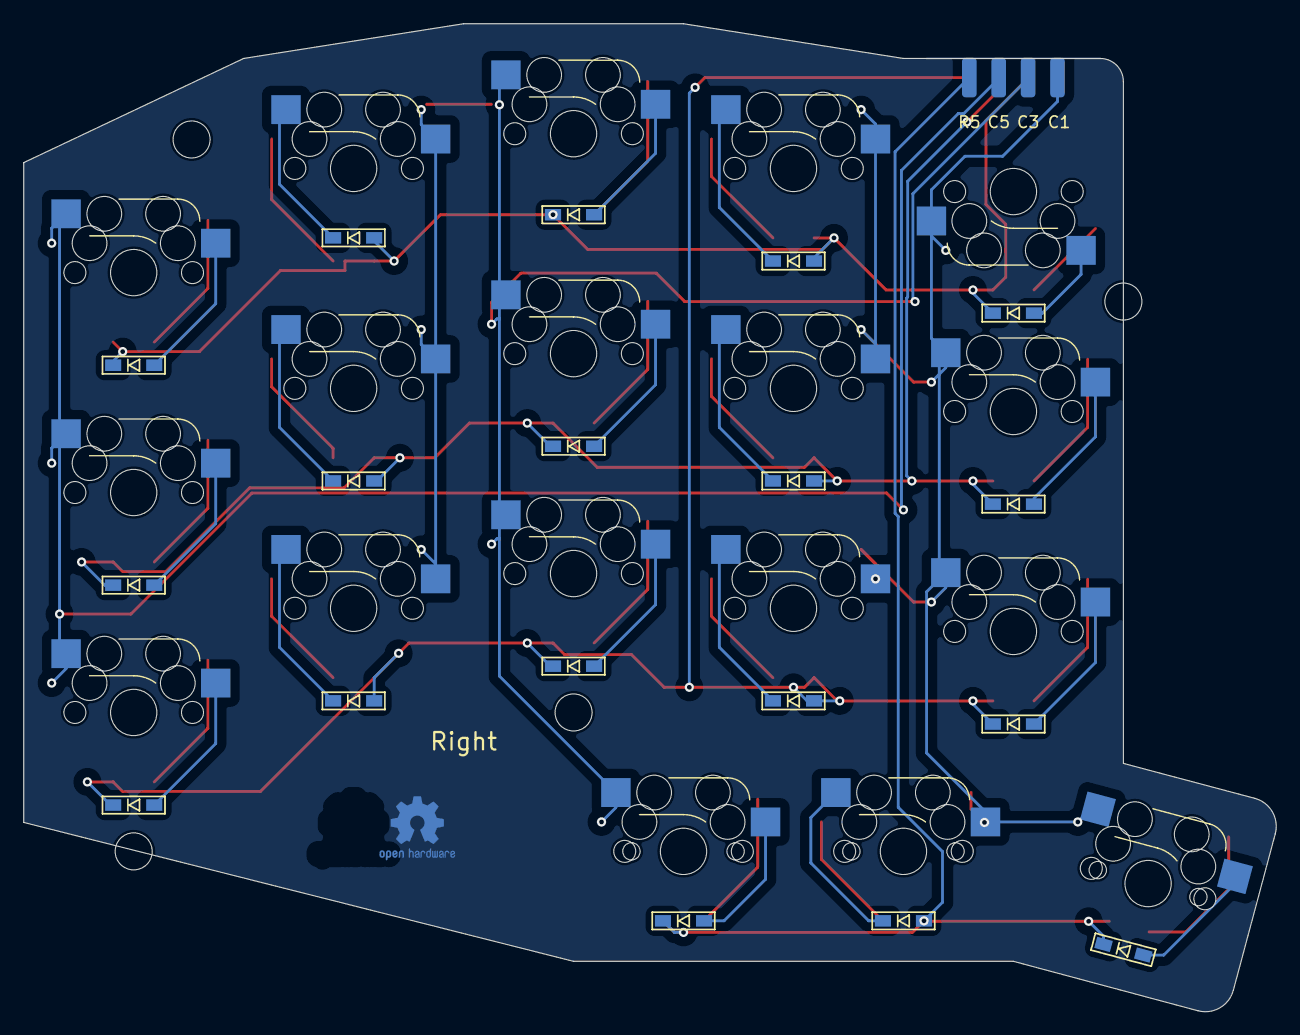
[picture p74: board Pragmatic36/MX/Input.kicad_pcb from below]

Board: 2 copper layers, 108.2 x 85.4 mm, 77 parts (21 on the bottom side), 43 nets.

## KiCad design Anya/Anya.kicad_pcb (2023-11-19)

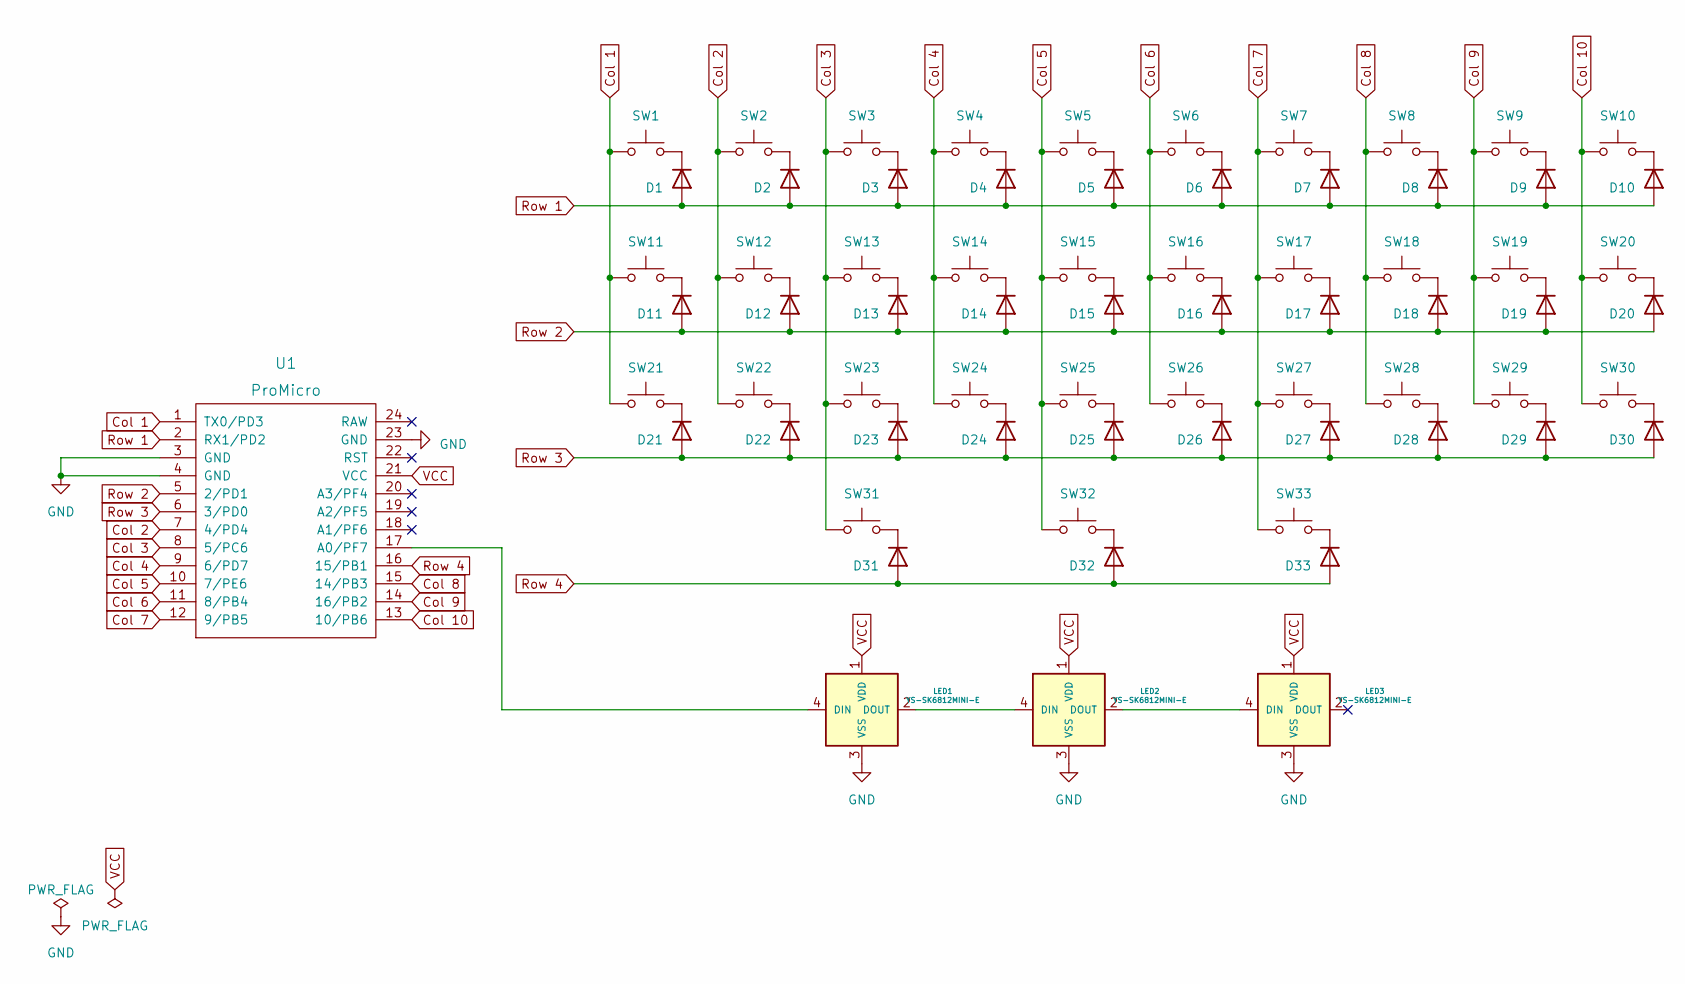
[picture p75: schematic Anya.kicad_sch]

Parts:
D1, D2, D3, D4, D5, D6, D7, D8, D9, D10, D11, D12, D13, D14, D15, D16, D17, D18, D19, D20, D21, D22, D23, D24, D25, D26, D27, D28, D29, D30, D31, D32, D33: 1N4448W; D3_SMD_v2
LED1, LED2, LED3: YS-SK6812MINI-E
SW1, SW2, SW3, SW4, SW5, SW6, SW7, SW8, SW9, SW10, SW11, SW12, SW13, SW14, SW15, SW16, SW17, SW18, SW19, SW20, SW21, SW22, SW23, SW24, SW25, SW26, SW27, SW28, SW29, SW30, SW31, SW32, SW33: SW_Push; MX_Hotswap
U1: ProMicro; ArduinoProMicro

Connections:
Col 1: SW1.1, SW11.1, SW21.1, U1.1 (TX0/PD3)
Col 2: SW2.1, SW12.1, SW22.1, U1.7 (4/PD4)
Col 3: SW3.1, SW13.1, SW23.1, SW31.1, U1.8 (5/PC6)
Col 4: SW4.1, SW14.1, SW24.1, U1.9 (6/PD7)
Col 5: SW5.1, SW15.1, SW25.1, SW32.1, U1.10 (7/PE6)
Col 6: SW6.1, SW16.1, SW26.1, U1.11 (8/PB4)
Col 7: SW7.1, SW17.1, SW27.1, SW33.1, U1.12 (9/PB5)
Col 8: SW8.1, SW18.1, SW28.1, U1.15 (14/PB3)
Col 9: SW9.1, SW19.1, SW29.1, U1.14 (16/PB2)
Col 10: SW10.1, SW20.1, SW30.1, U1.13 (10/PB6)
GND: LED1.3 (VSS), LED2.3 (VSS), LED3.3 (VSS), U1.3 (GND), U1.4 (GND), U1.23 (GND)
unnamed: D1.1 (K), SW1.2
unnamed: D2.1 (K), SW2.2
unnamed: D3.1 (K), SW3.2
unnamed: D4.1 (K), SW4.2
unnamed: D5.1 (K), SW5.2
unnamed: D6.1 (K), SW6.2
unnamed: D7.1 (K), SW7.2
unnamed: D8.1 (K), SW8.2
unnamed: D9.1 (K), SW9.2
unnamed: D10.1 (K), SW10.2
unnamed: D11.1 (K), SW11.2
unnamed: D12.1 (K), SW12.2
unnamed: D13.1 (K), SW13.2
unnamed: D14.1 (K), SW14.2
unnamed: D15.1 (K), SW15.2
unnamed: D16.1 (K), SW16.2
unnamed: D17.1 (K), SW17.2
unnamed: D18.1 (K), SW18.2
unnamed: D19.1 (K), SW19.2
unnamed: D20.1 (K), SW20.2
unnamed: D21.1 (K), SW21.2
unnamed: D22.1 (K), SW22.2
unnamed: D23.1 (K), SW23.2
unnamed: D24.1 (K), SW24.2
unnamed: D25.1 (K), SW25.2
unnamed: D26.1 (K), SW26.2
unnamed: D27.1 (K), SW27.2
unnamed: D28.1 (K), SW28.2
unnamed: D29.1 (K), SW29.2
unnamed: D30.1 (K), SW30.2
unnamed: D31.1 (K), SW31.2
unnamed: D32.1 (K), SW32.2
unnamed: D33.1 (K), SW33.2
unnamed: LED1.4 (DIN), U1.17 (A0/PF7)
unnamed: LED1.2 (DOUT), LED2.4 (DIN)
unnamed: LED2.2 (DOUT), LED3.4 (DIN)
Row 1: D1.2 (A), D2.2 (A), D3.2 (A), D4.2 (A), D5.2 (A), D6.2 (A), D7.2 (A), D8.2 (A), D9.2 (A), D10.2 (A), U1.2 (RX1/PD2)
Row 2: D11.2 (A), D12.2 (A), D13.2 (A), D14.2 (A), D15.2 (A), D16.2 (A), D17.2 (A), D18.2 (A), D19.2 (A), D20.2 (A), U1.5 (2/PD1)
Row 3: D21.2 (A), D22.2 (A), D23.2 (A), D24.2 (A), D25.2 (A), D26.2 (A), D27.2 (A), D28.2 (A), D29.2 (A), D30.2 (A), U1.6 (3/PD0)
Row 4: D31.2 (A), D32.2 (A), D33.2 (A), U1.16 (15/PB1)
VCC: LED1.1 (VDD), LED2.1 (VDD), LED3.1 (VDD), U1.21 (VCC)

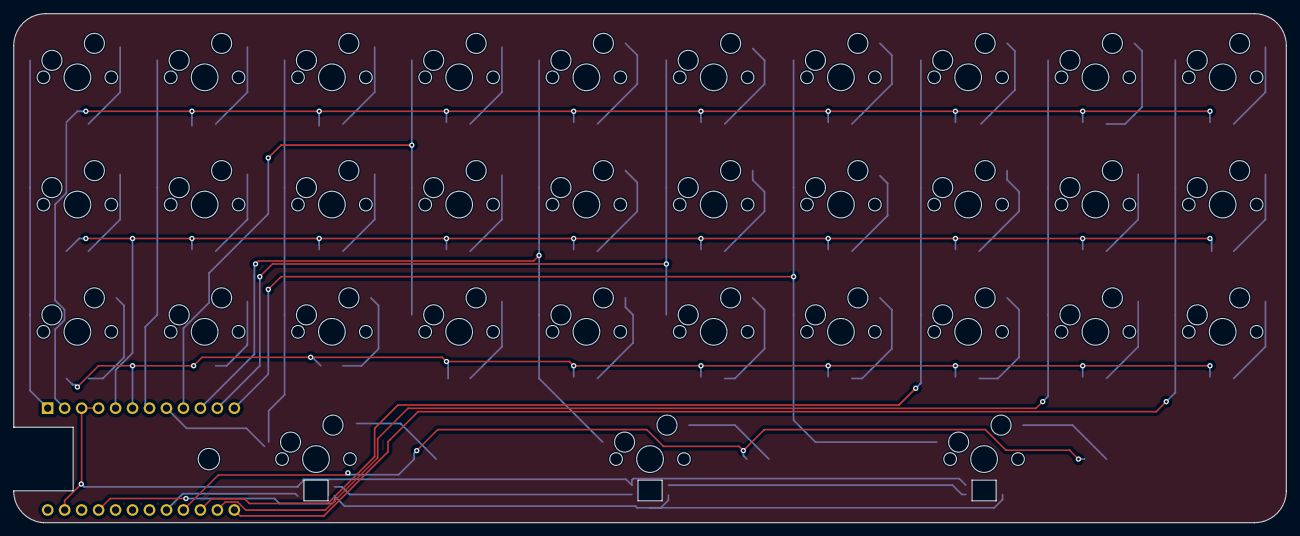
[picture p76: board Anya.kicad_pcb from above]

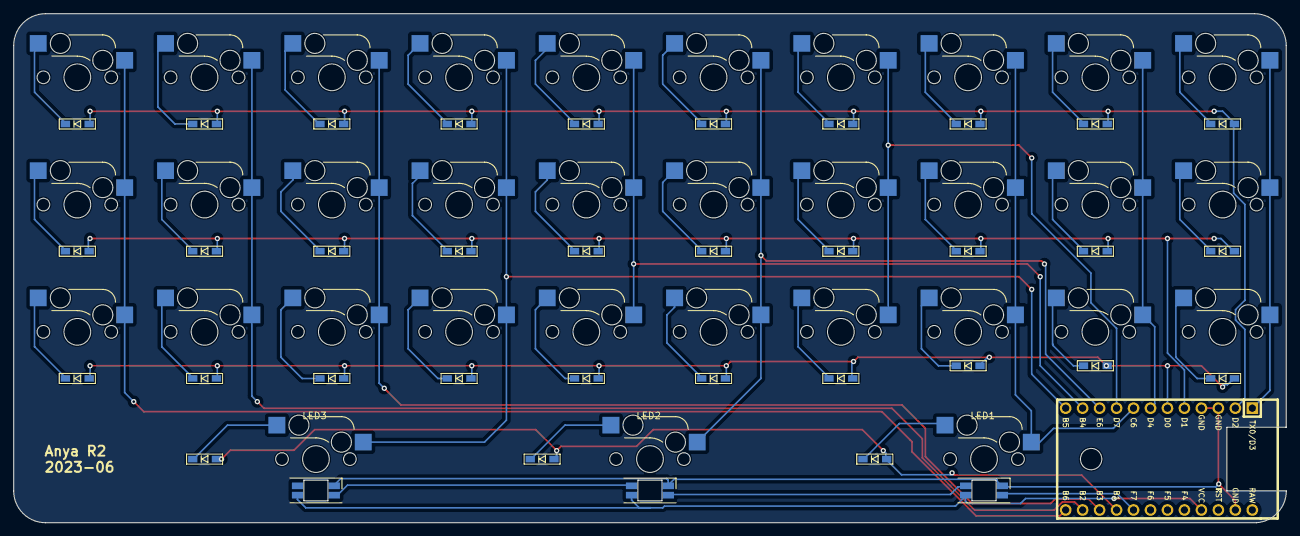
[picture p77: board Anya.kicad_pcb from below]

Board: 2 copper layers, 190.5 x 76.2 mm, 70 parts (37 on the bottom side), 52 nets.

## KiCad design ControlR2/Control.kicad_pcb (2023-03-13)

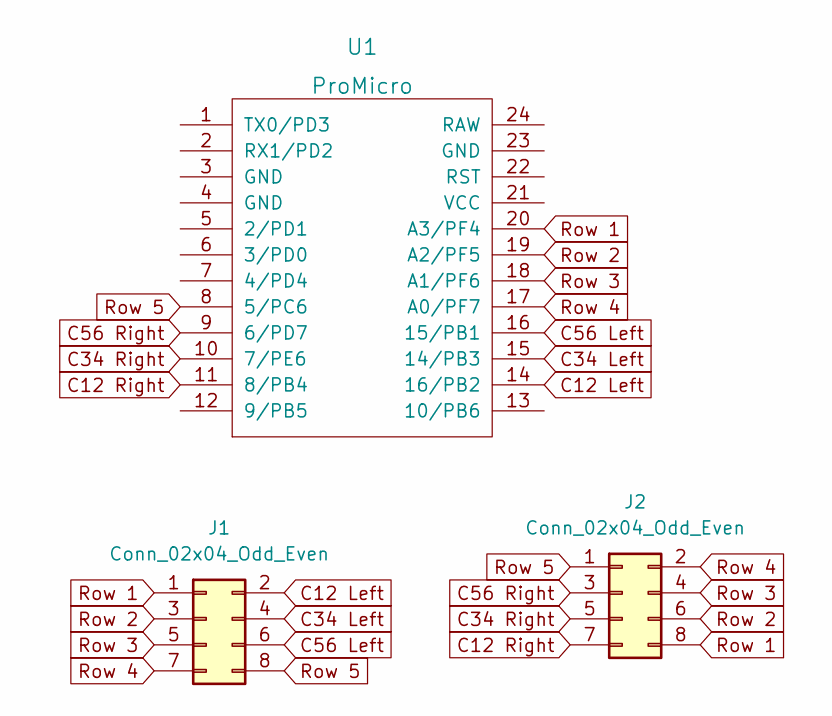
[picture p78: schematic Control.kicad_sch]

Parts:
J1, J2: Conn_02x04_Odd_Even; matrix_connector
U1: ProMicro; ProMicro Reversed

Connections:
C12 Left: J1.2, U1.14 (16/PB2)
C12 Right: J2.7, U1.11 (8/PB4)
C34 Left: J1.4, U1.15 (14/PB3)
C34 Right: J2.5, U1.10 (7/PE6)
C56 Left: J1.6, U1.16 (15/PB1)
C56 Right: J2.3, U1.9 (6/PD7)
Row 1: J1.1, J2.8, U1.20 (A3/PF4)
Row 2: J1.3, J2.6, U1.19 (A2/PF5)
Row 3: J1.5, J2.4, U1.18 (A1/PF6)
Row 4: J1.7, J2.2, U1.17 (A0/PF7)
Row 5: J1.8, J2.1, U1.8 (5/PC6)

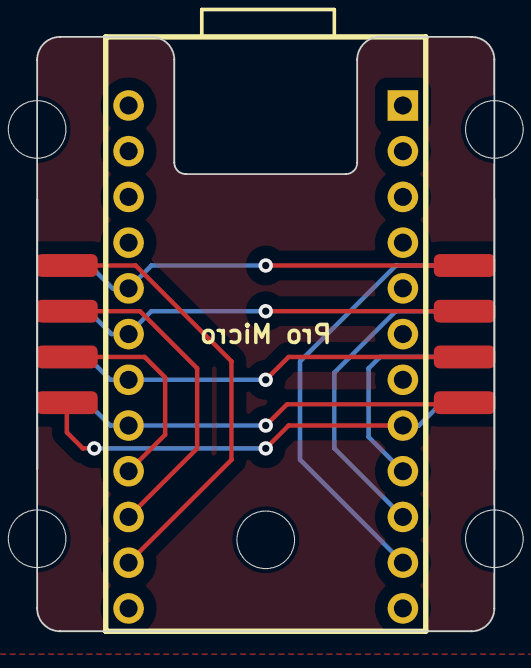
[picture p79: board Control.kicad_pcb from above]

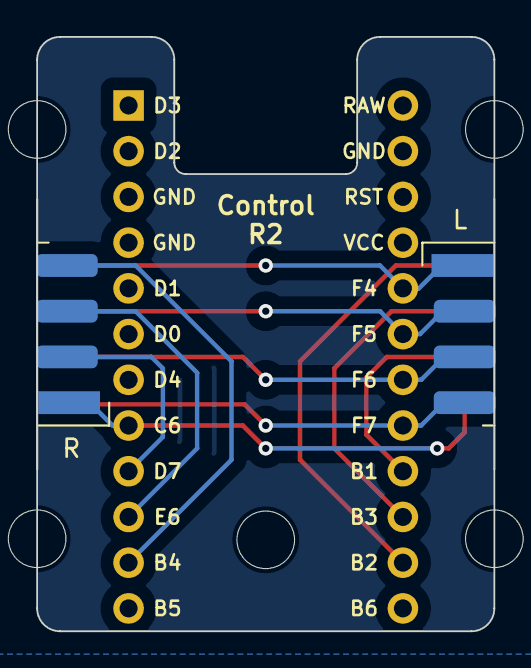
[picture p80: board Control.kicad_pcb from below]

Board: 2 copper layers, 25.4 x 33.0 mm, 3 parts (3 on the bottom side), 11 nets.

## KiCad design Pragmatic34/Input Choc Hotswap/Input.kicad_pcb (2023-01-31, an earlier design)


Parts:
D1, D2, D3, D4, D5, D6, D7, D8, D9, D10, D11, D12, D13, D14, D15, D16, D17, D18, D19, D20, D21, D22, D23, D24, D25, D26, D27, D28, D29, D30, D31, D32, D33, D34: 1N4148; D3_SMD_v2; LCSC C81598
J1, J2: Hand-Soldering; IDC-Header_2x07_P2.54mm_Vertical; LCSC C3406
SW1, SW2, SW3, SW4, SW5, SW6, SW7, SW8, SW9, SW10, SW11, SW12, SW13, SW14, SW15, SW16, SW17, SW18, SW19, SW20, SW21, SW22, SW23, SW24, SW25, SW26, SW27, SW28, SW29, SW30, SW31, SW32, SW33, SW34: SW_Push; MX_Hotswap; LCSC C2803348

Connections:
Col2: J1.6, SW1.2, SW11.2, SW21.2
Col3: J1.8, SW2.2, SW12.2, SW22.2
Col4: J1.10, SW3.2, SW13.2, SW23.2
Col5: J1.12, SW4.2, SW14.2, SW24.2, SW31.2
Col6: J1.14, SW5.2, SW15.2, SW25.2, SW32.2
Col7: J2.4, SW6.2, SW16.2, SW26.2, SW33.2
Col8: J2.6, SW7.2, SW17.2, SW27.2, SW34.2
Col9: J2.8, SW8.2, SW18.2, SW28.2
Col10: J2.10, SW9.2, SW19.2, SW29.2
Col11: J2.12, SW10.2, SW20.2, SW30.2
GND: J1.2, J2.2
unnamed: D1.2 (A), SW1.1
unnamed: D2.2 (A), SW2.1
unnamed: D3.2 (A), SW3.1
unnamed: D4.2 (A), SW4.1
unnamed: D5.2 (A), SW5.1
unnamed: D6.2 (A), SW6.1
unnamed: D7.2 (A), SW7.1
unnamed: D8.2 (A), SW8.1
unnamed: D9.2 (A), SW9.1
unnamed: D10.2 (A), SW10.1
unnamed: D11.2 (A), SW11.1
unnamed: D12.2 (A), SW12.1
unnamed: D13.2 (A), SW13.1
unnamed: D14.2 (A), SW14.1
unnamed: D15.2 (A), SW15.1
unnamed: D16.2 (A), SW16.1
unnamed: D17.2 (A), SW17.1
unnamed: D18.2 (A), SW18.1
unnamed: D19.2 (A), SW19.1
unnamed: D20.2 (A), SW20.1
unnamed: D21.2 (A), SW21.1
unnamed: D22.2 (A), SW22.1
unnamed: D23.2 (A), SW23.1
unnamed: D24.2 (A), SW24.1
unnamed: D25.2 (A), SW25.1
unnamed: D26.2 (A), SW26.1
unnamed: D27.2 (A), SW27.1
unnamed: D28.2 (A), SW28.1
unnamed: D29.2 (A), SW29.1
unnamed: D30.2 (A), SW30.1
unnamed: D31.2 (A), SW31.1
unnamed: D32.2 (A), SW32.1
unnamed: D33.2 (A), SW33.1
unnamed: D34.2 (A), SW34.1
Row3: D1.1 (K), D2.1 (K), D3.1 (K), D4.1 (K), D5.1 (K), J1.7
Row3': D6.1 (K), D7.1 (K), D8.1 (K), D9.1 (K), D10.1 (K), J2.7
Row4: D11.1 (K), D12.1 (K), D13.1 (K), D14.1 (K), D15.1 (K), J1.9
Row4': D16.1 (K), D17.1 (K), D18.1 (K), D19.1 (K), D20.1 (K), J2.9
Row5: D21.1 (K), D22.1 (K), D23.1 (K), D24.1 (K), D25.1 (K), J1.11
Row5': D26.1 (K), D27.1 (K), D28.1 (K), D29.1 (K), D30.1 (K), J2.11
Row6: D31.1 (K), D32.1 (K), J1.13
Row6': D33.1 (K), D34.1 (K), J2.13
VCC: J1.1, J2.1

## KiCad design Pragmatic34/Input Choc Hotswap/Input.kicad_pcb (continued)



Board: 2 copper layers, 222.2 x 110.5 mm, 70 parts (68 on the bottom side), 54 nets.

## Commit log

2021-11-06 connector and rows
    [Pragmatic.kicad_pcb, Pragmatic.sch]
2021-11-06 before rework.
    [Pragmatic.kicad_pcb, Pragmatic.sch]
2021-11-06 left ready
    [Pragmatic.kicad_pcb, Pragmatic.sch]
2021-11-06 left done
    [Pragmatic.kicad_pcb]
2021-11-06 head board
    [DIP-24 W15.24mm IC Socket.STEP, Pragmatic.kicad_pcb, Pragmatic.sch]
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2021-11-07 fix power track width
    [Pragmatic.kicad_pcb, Pragmatic.sch]
2021-11-08 finish up left
    [Pragmatic.kicad_pcb]
2021-11-08 finish up
    [Pragmatic.kicad_pcb, Pragmatic.sch]
2021-11-08 export to gerber
    [Pragmatic-B_Cu.gbr, Pragmatic-B_Mask.gbr, Pragmatic-B_Paste.gbr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]
2021-11-08 refactor clean
    [Pragmatic-B_Cu.gbr, Pragmatic-B_Mask.gbr, Pragmatic-B_Paste.gbr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]
2021-11-08 fit into manufacture requirement
    [Pragmatic-B_Cu.gbl, Pragmatic-B_Mask.gbs, Pragmatic-B_Paste.gbr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]
2021-11-08 apply jlc rule
    [Pragmatic-B_Cu.gbl, Pragmatic-B_Mask.gbs, Pragmatic-B_Paste.gbr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]
2021-11-17 mirror sample
    [Pragmatic-B_Cu.gbl, Pragmatic-B_Mask.gbs, Pragmatic-B_SilkS.gbo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]
2021-11-17 fix schematic to PCB problem。
    [Pragmatic.kicad_pcb, Pragmatic.sch]
2021-11-18 double side design
    [Pragmatic-B_Cu.gbl, Pragmatic-B_Mask.gbs, Pragmatic-B_SilkS.gbo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]
2021-11-18 left hand done.
    [Pragmatic.kicad_pcb, Pragmatic.sch]
2021-11-18 credit list
    [Pragmatic-B_Cu.gbl, Pragmatic-B_Mask.gbs, Pragmatic-B_Paste.gbp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]
2021-11-19 controller done
    [Pragmatic.kicad_pcb, Pragmatic.sch]
2021-11-19 minor tweak
    [DIP-24 W15.24mm IC Socket.STEP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]
2021-11-20 via under pad experiment
    [Pragmatic-B_Cu.gbl, Pragmatic-B_Mask.gbs, Pragmatic-B_Paste.gbp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]
2021-11-20 fabrication lengend
    [Pragmatic.kicad_pcb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]
2021-11-20 fix power line routing
    [Pragmatic-B_Cu.gbl, Pragmatic-B_Mask.gbs, Pragmatic-B_SilkS.gbo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]
2021-11-30 Rework for Pro Micro compatibility
    [Pragmatic-B_Cu.gbl, Pragmatic-B_Cu.gbr, Pragmatic-B_Mask.gbr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]
2021-11-30 16P back to 14P, all via under pad
    [Pragmatic-B_Cu.gbl, Pragmatic-B_Mask.gbs, Pragmatic-B_Paste.gbp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]
2021-11-30 bridge - input concept. While computer is the brain.
    [Pragmatic-B_Cu.gbr, Pragmatic-B_Mask.gbr, Pragmatic-B_Paste.gbr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]
2021-12-04 move via out of pad
    [Pragmatic.kicad_pcb]
2021-12-19 build instruction draft
    [Pragmatic-B_Cu.gbl, Pragmatic-B_Cu.gbr, Pragmatic-B_Mask.gbr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]
2021-12-20 v1 plate
    [Plate-V1.dxf]
2022-01-09 migrate to Kicad 6
    [Pragmatic.kicad_pcb, Pragmatic.kicad_sch]
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2022-01-31 clean up
    [Plate-V1.dxf]
2022-02-07 add elite C extension
    [Pragmatic-B_Cu.gbl, Pragmatic-B_Mask.gbs, Pragmatic-B_Silkscreen.gbo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]
2022-04-26 v3.1 fix mounting hole position
    [Pragmatic.kicad_pcb]
2022-06-08 init 34
    [34.kicad_pcb, 34.kicad_sch]
2022-06-10 right hand ready
    [34.kicad_pcb, 34.kicad_sch]
2022-06-13 postpone i2c design
    [34.kicad_pcb, 34.kicad_sch]
2022-06-15 progress update
    [Pragmatic-B_Cu.gbl, Pragmatic-B_Mask.gbs, Pragmatic-B_Silkscreen.gbo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]
2022-06-16 v3.1 34
    [34R.step, Pragmatic.kicad_pcb, Pragmatic.step]
2022-06-16 increase plate border for manufacture.
    [Plate-Edge_Cuts.gm1, Plate-F_Cu.gtl, Plate-F_Mask.gts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]
2022-06-16 60 plate
    [Plate-Edge_Cuts.gm1, Plate-F_Cu.gtl, Plate-F_Mask.gts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]
2022-06-16 add origin
    [Pragmatic.kicad_pcb]
2022-06-16 update footprint
    [Pragmatic.kicad_pcb]
2022-06-16 prepare for manufacture
    [Pragmatic-B_Cu.gbl, Pragmatic-B_Mask.gbs, Pragmatic-B_Silkscreen.gbo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]
2022-06-16 shrink IDC silkscreen
    [Pragmatic-B_Cu.gbl, Pragmatic-B_Mask.gbs, Pragmatic-B_Silkscreen.gbo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]
2022-06-17 change footprint
    [Pragmatic-B_Cu.gbl, Pragmatic-B_Mask.gbs, Pragmatic-B_Silkscreen.gbo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]
2022-06-18 reversed pro micro
    [Pragmatic-B_Cu.gbl, Pragmatic-B_Mask.gbs, Pragmatic-B_Silkscreen.gbo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]
2022-06-20 fix silk screen
    [Pragmatic.kicad_pcb]
2022-06-21 fix mount hole dimension
    [Plate-B_Cu.gbl, Plate-B_Mask.gbs, Plate-B_Silkscreen.gbo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]
2022-06-25 update border.
    [Control.kicad_pcb, Control.kicad_sch]
2022-07-22 plate 1
    [Pragmatic-Edge_Cuts.gm1, Pragmatic-F_Cu.gtl, Pragmatic-F_Mask.gts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]
2022-07-22 almost there
    [Pragmatic.kicad_pcb, Pragmatic.step]
2022-07-22 export model
    [Pragmatic.step]
2022-07-22 outline ready
    [34a.kicad_pcb, 34a.kicad_sch]
2022-07-22 plate ready
    [Plate-Edge_Cuts.gm1, Plate-F_Cu.gtl, Plate-F_Mask.gts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]
2022-07-22 ready for print
    [34a-B_Cu.gbl, 34a-B_Mask.gbs, 34a-B_Silkscreen.gbo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]
2022-08-07 update logo
    [Plate.kicad_pcb]
2022-08-07 tidy up
    [34.kicad_pcb, 34.kicad_sch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]
2022-08-07 fix rubber position
    [Input.kicad_pcb]
2022-08-07 add part number and replot
    [Input-B_Cu.gbl, Input-B_Mask.gbs, Input-B_Silkscreen.gbo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]
2022-08-07 fix plate
    [Plate-Edge_Cuts.gm1, Plate-F_Cu.gtl, Plate-F_Mask.gts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]
2022-08-07 change logo
    [Pragmatic-B_Cu.gbl, Pragmatic-B_Mask.gbs, Pragmatic-B_Silkscreen.gbo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]
2022-08-30 update control board
    [Control-B_Cu.gbl, Control-B_Mask.gbs, Control-B_Silkscreen.gbo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]
2023-01-12 use step model for fusion 360
    [Control.kicad_pcb]
2023-01-12 new type c board
    [Control-B_Cu.gbl, Control-B_Mask.gbs, Control-B_Silkscreen.gbo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]
2023-01-14 new case
    [MX60 V3 Low Profile.3mf]
2023-01-30 with '#' will be ignored, and an empty message aborts the commit.
    [V4-B_Cu.gbl, V4-B_Cu.gbr, V4-B_Mask.gbr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]
2023-02-07 fix diode direction, missing wire, and pin position
    [V4-B_Cu.gbl, V4-B_Mask.gbs, V4-B_Paste.gbp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]
2023-02-07 add descriptive text
    [V4-B_Cu.gbl, V4-B_Mask.gbs, V4-B_Paste.gbp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]
2023-02-13 fix footprint
    [Kailh Choc FunkMonk 1u.step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]
2023-02-13 first release
    [Input.kicad_pcb, Input.kicad_sch, Kailh Choc FunkMonk 1u.step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]
2023-02-27 init R2 control
    [Control PCB.step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]
2023-03-07 fix all Kicad 7 DRC
    [Input-B_Cu.gbl, Input-B_Mask.gbs, Input-B_Silkscreen.gbo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]
2023-03-09 to be validated
    [Input-B_Cu.gbl, Input-B_Mask.gbs, Input-B_Silkscreen.gbo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]
2023-03-09 update model
    [PCB.step]
2023-03-13 36 validating
    [Input-B_Cu.gbl, Input-B_Mask.gbs, Input-B_Silkscreen.gbo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]
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2023-11-19 MX 36 wrap up
    [Input.kicad_pcb]
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2024-06-13 MX54 R2.2 key switch on south
    [Input.kicad_pcb, Input.kicad_sch]
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
